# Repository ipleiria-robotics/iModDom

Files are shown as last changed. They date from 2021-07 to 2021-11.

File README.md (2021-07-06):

# iModDom
*Inexpensive Modular Domotics*

O projeto iModDom consiste num ecossistema de *hardware* e *software* desenvolvido de forma a ser utilizado em conjunto para aplicações em domótica utilizando o [Home Assistant](https://www.home-assistant.io/ "Home Assistant") e o [ESPHome](https://esphome.io/ "ESPHome").
A parte de *hardware* do projeto consiste em três placas de circuito impresso desenvolvidas para albergar todos os componentes com o objetivo de obter uma solução compacta e de fácil utilização. Já a parte de *software* consiste numa página *web* desenvolvida para o projeto, onde contém ferramentas que possibilitam a programação, do respetivo *hardware*, através de blocos.
O projeto foi desenvolvido com o intuito e objetivo de ser uma solução económica e que permitisse a sua utilização aos utilizadores sem conhecimentos na área da programação.

<p align="center">

</p>

## Passos a Seguir
- Recomenda-se que comece por consultar o manual técnico do projeto de modo a ficar a conhecer todos os componentes utilizados e o processo de montagem do *hardware*.
- Consulte os tutoriais disponíveis para poder usufruir do *software* desenvolvido.
- Faça as atividades propostas para ficar apto a criar as suas próprias aplicações para domótica.

## Ajuda
Se estiver com problemas, pode reportá-los [aqui](https://github.com/ipleiria-robotics/iModDom/issues "aqui").

## Contribuições 
Estamos abertos a sugestões com a finalidade de melhorar o projeto, pode colocá-las em forma de [pull request](https://github.com/ipleiria-robotics/iModDom/pulls "pull request") ou relatando os erros detetados.

# Autores
 - Marco Pereira - estudante do [Politécnico de Leiria](https://www.ipleiria.pt) do curso TeSP em Automação, Robótica e manutenção Industrial, GitHub: [MarcoPereira00](https://github.com/MarcoPereira00)

## Orientado por:
- Luís Conde - [Politécnico de Leiria](https://www.ipleiria.pt), GitHub:  [Luís Conde](https://github.com/conde-ISR-UC-PT)
- Carlos Neves - [Politécnico de Leiria](https://www.ipleiria.pt), [INESC-Coimbra](http://inescc.estg.ipleiria.pt/) GitHub:  [Carlos Neves](https://github.com/carlos-neves)

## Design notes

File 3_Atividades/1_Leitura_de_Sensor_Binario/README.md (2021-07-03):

# iModDom
## Exercícios de Leitura de Sensor Binário
- Com estes exercícios o utilizador irá ficar apto a realizar leituras de sensores binários, nomeadamente de botões, com vários graus de complexidade.

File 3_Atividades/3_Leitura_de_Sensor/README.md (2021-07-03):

# iModDom
## Exercícios de Leitura de Sensor
- Estes exercícios permitem ao utilizador desenvolver capacidades ao nível da leitura de sensores e também irá ficar a apto a fazer *upload* via WiFi, a criar um *web server* e visualizar as mensagens de *debug*.

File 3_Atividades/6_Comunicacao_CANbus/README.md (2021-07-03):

# iModDom
## Exercícios de Comunicação CANbus
- Estes exercícios são relativos ao protoclo de comunicação CANbus e desafiam o utilizador a realizar algumas implementações, de diferentes graus de dificuldade, através desse protocolo de comunicação.

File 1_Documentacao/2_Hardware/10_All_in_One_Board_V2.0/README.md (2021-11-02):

# iModDom
## *All Boards V2.0*
- Nesta Pasta pode encontrar os ficheiros que permitem fabricar de forma facilitada todas as placas desenvolvidas relativas à versão V2.0.


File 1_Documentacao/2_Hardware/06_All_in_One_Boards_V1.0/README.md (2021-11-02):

# iModDom
## *All Boards V1.0*
- Nesta Pasta pode encontrar os ficheiros que permitem fabricar de forma facilitada todas as placas desenvolvidas relativas à versão V1.0.


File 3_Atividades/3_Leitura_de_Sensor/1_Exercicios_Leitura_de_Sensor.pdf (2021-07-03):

# iModDom

V1.0-2021

# Leitura de Sensor - Exercícios

Elaborado por:
Marco Pereira - 2190516

Orientado por:
Luís Bento
Carlos Neves

V1.0-2021

Leitura de Sensor - Exercícios

### Índice

V1.0-2021 | 1

### 1. Introdução

Este documento integra um conjunto de exercícios de programação através de blocos para colocar em prática no projeto iModDom. Nestes exercícios a utilização das placas de circuito impresso do projeto é facultativa. Pode encontrar as soluções dos exercícios na pasta onde estes se encontram, e poderá fazer upload do ficheiro na página onde utiliza os blocos, de forma a visualizar as soluções.

1.1.Objetivos

O objetivo com estes exercícios é que o utilizador comece a ganhar capacidade de criar os seus próprios programas através dos blocos do projeto.

V1.0-2021 | 2

### 2. Exercícios

### 1. Crie um programa que permita visualizar os valores de temperatura e humidade do

sensor DHT11/DHT22, com uma taxa de atualização de 10 segundos. O pino utilizado para o sensor DHT fica ao seu critério.

1.1. Ao programa criado, adicione a possibilidade de realizar o upload via WiFi.

### 1.2. Implemente as funcionalidades que permitam a criação de um web server e a

visualização de mensagens do nível debug.

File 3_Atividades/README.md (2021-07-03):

# iModDom
## Atividades
- Nesta secção pode encontrar exercícios abrangentes a todas as funcionalidades do *software* desenvolvido. Após a realização de todos os exercicios ficará com as competências necessárias para executar e implementar as suas próprias aplicações em domótica. Cada exercício tem a respetiva solução.

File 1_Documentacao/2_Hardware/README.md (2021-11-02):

# iModDom
## *Hardware*
- Aqui estão disponíveis todos os ficheiros das placas de circuito impresso desenvolvidas através do *software Autodesk Eagle*. As placas contêm versões pelo que deverá sempre optar pela versão mais recente.
- Se desejar realizar alterações ao *hardware* desenvolvido tem todas as bibliotecas que foram utilizadas disponíveis na pasta [02_Eagle_Libraries](https://github.com/ipleiria-robotics/iModDom/tree/main/1_Documentacao/2_Hardware/02_Eagle_Libraries "02_Eagle_Libraries").
- Na pasta [01_Lista_de_Hardware](https://github.com/ipleiria-robotics/iModDom/blob/main/1_Documentacao/2_Hardware/01_Lista_de_Hardware "01_Lista_de_Hardware") pode verificar os custos do projeto de forma descriminada. Note que podem existir variações nos valores.
### Nota:
As versões V2.0 das placas, à presente data, não foram testadas nem fabricadas, pelo que a sua utilização e fabrico ficará à responsabilidade do utilizador. À exceção da versão V2.0 da *Shunt Board* que está totalmente funcional e testada.

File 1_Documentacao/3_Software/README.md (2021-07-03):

# iModDom
## *Software*
- Aqui encontra todos os ficheiros da solução de *software* desenvolvida e utilizada para a programação através de blocos. Esta solução foi desenvolvida utilizando a biblioteca do [Blockly](https://github.com/google/blockly#blockly- "Blockly").
- Na pasta [iModDom](https://github.com/ipleiria-robotics/iModDom/tree/main/1_Documentacao/3_Software/iModDom "iModDom") encontra todos os ficheiros necessários para a implementação da página *web* dos blocos.
- Através do ficheiro [library.xml](https://github.com/ipleiria-robotics/iModDom/blob/main/1_Documentacao/3_Software/library.xml "library.xml") pode editar os blocos de programação existentes utilizando a página [Blockly Developer Tools](https://blockly-demo.appspot.com/static/demos/blockfactory/index.html "Blockly Developer Tools").



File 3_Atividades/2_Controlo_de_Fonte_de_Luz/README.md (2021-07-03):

# iModDom
## Exercícios de Controlo de Fonte de Luz
- Estes exercícios permitem ao utilizador desenvolver capacidades ao nível do controlo de fontes de luz, através de vários niveis de complexidade.

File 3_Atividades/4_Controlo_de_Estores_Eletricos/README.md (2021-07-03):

# iModDom
## Exercícios de Controlo de Estores Elétricos
- Estes exercícios são relativos ao controlo de estores elétricos e desafiam o utilizador a desenvolver programações com a finalidade de controlar estores elétricos através de botões e do *Home Assistant*.

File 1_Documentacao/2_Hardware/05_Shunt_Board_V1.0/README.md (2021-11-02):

# iModDom
## *Shunt Board V1.0*
- Esta versão está finalizada, no entanto, à presente data não foi fabricada nem testada, pelo que a sua utilização fica à responsabilidade do utilizador.



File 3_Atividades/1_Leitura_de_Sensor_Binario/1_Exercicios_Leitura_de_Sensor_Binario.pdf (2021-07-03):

# iModDom

V1.0-2021

# Leitura de Sensor Binário - Exercícios

Elaborado por:
Marco Pereira - 2190516

Orientado por:
Luís Bento
Carlos Neves

V1.0-2021

Leitura de Sensor Binário - Exercícios

### Índice

V1.0-2021 | 1

### 1. Introdução

Este documento integra um conjunto de exercícios de programação através de blocos para colocar em prática no projeto iModDom. Nestes exercícios a utilização das placas de circuito impresso do projeto é facultativa. Pode encontrar as soluções dos exercícios na pasta onde estes se encontram, e poderá fazer upload do ficheiro na página onde utiliza os blocos, de forma a visualizar as soluções.

1.1.Objetivos

O objetivo com estes exercícios é que o utilizador comece a ganhar capacidade de criar os seus próprios programas através dos blocos do projeto.

V1.0-2021 | 2

### 2. Exercícios

### 1. Utilizando os blocos do projeto iModDom, crie um programa que possibilite a

leitura do estado de um botão no Home Assistant. O pino a utilizar fica ao seu critério.

### 1.1. Adicione agora, uma saída ao seu programa. O interlock e o restore mode não

deverão estar ativos e o pino a utilizar fica ao seu critério.

### 1.2. Ao programa já criado, adicione uma automação ao sensor binário, para que

quando o botão sofra um clique, de no máximo até 0.5 segundos de duração, a saída seja ativada e quando o botão sofrer um duplo clique com uma duração máxima de 0.5 segundos, a saída seja desativada.

1.3. Repita os exercícios anteriores, mas desta vez utilizando pinos, ao seu critério, do PCF8574 com o endereço 0x20 para receber a leitura do botão e do PCF8574 com o endereço 0x22 para comandar a saída.

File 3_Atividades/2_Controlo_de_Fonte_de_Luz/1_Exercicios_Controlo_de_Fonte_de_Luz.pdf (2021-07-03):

# iModDom

V1.0-2021

# Controlo de Fonte de Luz - Exercícios

Elaborado por:
Marco Pereira - 2190516

Orientado por:
Luís Bento
Carlos Neves

V1.0-2021

Controlo de Fonte de Luz - Exercícios

### Índice

V1.0-2021 | 1

### 1. Introdução

Este documento integra um conjunto de exercícios de programação através de blocos para colocar em prática no projeto iModDom. Nestes exercícios a utilização das placas de circuito impresso do projeto é facultativa. Pode encontrar as soluções dos exercícios na pasta onde estes se encontram, e poderá fazer upload do ficheiro na página onde utiliza os blocos, de forma a visualizar as soluções.

1.1.Objetivos

O objetivo com estes exercícios é que o utilizador comece a ganhar capacidade de criar os seus próprios programas através dos blocos do projeto.

V1.0-2021 | 2

### 2. Exercícios

### 1. Crie um programa, que permita controlar o estado de uma fonte de luz através do

Home Assistant. O pino utilizado para a fonte de luz fica ao seu critério.

### 1.1. Adicione ao programa criado, a possibilidade de acender a fonte luz no

momento em que se pressiona um botão e apagar quando se liberta esse mesmo botão. O pino utilizado para o botão fica ao seu critério.

### 1.2. Repita os exercícios anteriores, mas utilizando pinos, à sua escolha, do

PCF8574 com o endereço 0x22, para a fonte de luz, e do PCF8574 com o endereço 0x20 para receber a leitura do estado do botão.

### 1.3. No programa já existente, adicione mais uma fonte de luz, em que o seu estado

será alterado aquando de um clique duplo no botão com uma duração máxima, de cada clique, de 0.5 segundos. O estado da fonte de luz adicionada anteriormente será alterado sempre que existir um clique com uma duração máxima de 0.5 segundos. Deverá adicionar a nova fonte de luz num pino do PCF8574 com o endereço 0x22.

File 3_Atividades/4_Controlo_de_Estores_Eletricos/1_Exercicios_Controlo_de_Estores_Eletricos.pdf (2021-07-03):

# iModDom

V1.0-2021

# Controlo de Estores Elétricos - Exercícios

Elaborado por:
Marco Pereira - 2190516

Orientado por:
Luís Bento
Carlos Neves

V1.0-2021

Controlo de Estores Elétricos - Exercícios

### Índice

V1.0-2021 | 1

### 1. Introdução

Este documento integra um conjunto de exercícios de programação através de blocos para colocar em prática no projeto iModDom. Nestes exercícios a utilização das placas de circuito impresso do projeto é facultativa. Pode encontrar as soluções dos exercícios na pasta onde estes se encontram, e poderá fazer upload do ficheiro na página onde utiliza os blocos, de forma a visualizar as soluções.

1.1.Objetivos

O objetivo com estes exercícios é que o utilizador comece a ganhar capacidade de criar os seus próprios programas através dos blocos do projeto.

V1.0-2021 | 2

### 2. Exercícios

### 1. Crie um programa que permita controlar uns estores elétricos através do Home

Assistant, utilizando duas saídas para simular a abertura e fecho dos estores. O tempo de abertura e de fecho deverá ser de 5 segundos para cada ação.

### 1.1. Adicione ao programa, a possibilidade de abrir, fechar e parar os estores

elétricos através de três botões, um para cada função. Deverá definir a duração máxima de 0.5 segundos para cada clique. Os pinos de cada botão ficam ao seu critério.

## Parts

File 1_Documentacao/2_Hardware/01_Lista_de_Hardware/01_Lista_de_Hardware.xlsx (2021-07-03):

 |  | Dep. Eng. Eletrotécnica - UC de Projeto em Engenharia Eletrotécnica e de Computadores
 |  | Lista de Material e Fornecedores
 |  | Título Projeto: | iModDom
 |  | Orientadores: | Luis Conde Bento, Carlos Neves
 |  | Data: | 2021-06-17
Item | Descrição | Referência | Qtd | Fornecedor
 | ESPHOME
1 | Placas de Circuito Impresso (Quantidade mínima de 5 unidades) |  | 1 | JLPCB | https://jlcpcb.com/VGB
2 | Módulo RJ45 2x4 (Quantidade mínima de 10) | 10Pcs Sample 2x4 Ports 59 Series Stack-up Female RJ45 Ethernet Network LAN PCB Socket Connector Jack | 1 | AliExpress | https://es.aliexpress.com/item/32274753116.html
3 | I/O Expander PCF8574 | PCF8574 I2C Interface 8bit IO MCU Expansion Board I/O Expander I2C Bus Evaluation Development Module AVR STM8 C8051F For Arduino | 6 | AliExpress | https://es.aliexpress.com/item/4001011447071.html
4 | Módulo de 8 Relés de Estado Sólido | Low Level 5V 1/2/4/8 Channel Solid State Relay Module SSR G3MB-202P 240V 2A Output with Resistive Fuse For Arduino 1 2 4 8 Way | 3 | AliExpress | https://es.aliexpress.com/item/32788946442.html?albpd=pt32788946442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
5 | ESP32-PoE-ISO |  | 1 | Olimex | https://www.olimex.com/Products/IoT/ESP32/ESP32-POE-ISO/open-source-hardware
6 | Módulo CANbus MCP2515 | KKCHIP MCP2515 CAN Bus Module TJA1050 receiver SPI For 51 MCU ARM controller | 3 | AliExpress | https://es.aliexpress.com/item/1005002304689735.html
7 | ESP8266 D1 Mini | D1 Mini ESP8266 ESP-12 ESP-12F CH340G CH340 V2 USB WeMos WIFI Development Board D1 Mini NodeMCU Lua IOT Board 3.3V With Pins | 2 | AliExpress | https://es.aliexpress.com/item/1005001636509632.html?spm=a2g0s.9042311.0.0.30d04c4dn6QdZj
8 | Pinos conectores fêmea (Quantidade mínima de 10 unidades de 40 pinos cada) | 10pcs 40 Pin 1x40 Single Row Male And Female 2.54 Breakable Pin Header Connector Strip For Arduino Black | 1 | AliExpress | https://es.aliexpress.com/item/1005002368609978.html
9 | Parafusos plásticos M3x18 (Quantidade mínima de 50 unidades) | 50pcs Brand New M2 M3 M4 High Quality Black White Nylon Plastic Phillips Pan Head Cross Round Screw Bolt length 5mm-25mm | 1 | AliExpress | https://es.aliexpress.com/item/32979035684.html
10 | Porcas M3 (Quantidade mínima de 50 unidades) | 50pcs Brand New M2 M3 M4 High Quality Black White Nylon Plastic Phillips Pan Head Cross Round Screw Bolt length 5mm-25mm | 1 | AliExpress | https://es.aliexpress.com/item/32979035684.html
11 | Espaçadores M3 11mm (Quantidade mínima de 100 unidades) | M3x11 Nuts Hex PCB Spacer Standoff Pillar Female to Female Plastic Nylon Accessories for UAV Quadrotor Off-White Pack 100 | 1 | AliExpress | https://es.aliexpress.com/item/32775392154.html
12 | Sensor DHT11 | DHT11 Temperature Humidity Sensor Module Digital Single Bus 3.3V-5V with Jumper Wires for Arduino Raspberry Pi | 1 | AliExpress | https://es.aliexpress.com/item/1005002119274556.html
13 | Ficha RJ45 (Quantidade mínima de 10) | 10Pcs Per Lot RJ45 Metal 8 Pin Female PCB Right Angle Board Jack Connector 8P8C Crystal Head Socket 18mm Network Interface | 1 | AliExpress | https://pt.aliexpress.com/item/32680360858.html
 | HOME ASSISTANT
14 | Raspberry Pi 4 Model B |  | 1 | Mauser | https://mauser.pt/catalog/product_info.php?products_id=096-7401&src=raspberrypi

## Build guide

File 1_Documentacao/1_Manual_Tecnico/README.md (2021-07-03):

# iModDom
## Manual Técnico
- Aqui poderá consultar o manual técnico do projeto, sendo que a versão do mesmo corresponde à versão do *hardware* do projeto. Este documento inclui a descrição de todos os componentes utilizados no projeto, listagem do material e o processo de montagem do *hardware*.

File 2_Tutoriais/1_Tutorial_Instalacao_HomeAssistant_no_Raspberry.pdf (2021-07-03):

# iModDom

V1.0-2021

# Tutorial – Instalação Home Assistant no Raspberry

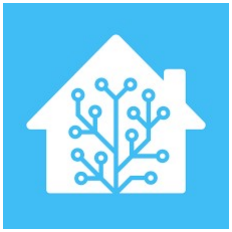
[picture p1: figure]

Elaborado por:
Marco Pereira - 2190516

Orientado por:
Luís Bento
Carlos Neves

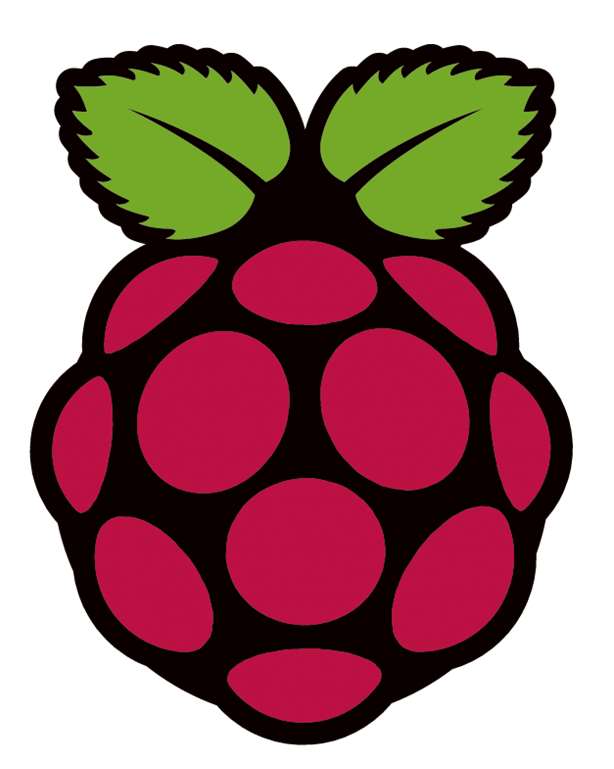
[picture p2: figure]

V1.0-2021

Tutorial – Instalação Home Assistant no Raspberry

### Índice

V1.0-2021 | 1

### 1. Introdução

O Home Assistant é uma plataforma de automação open source que permite rastrear e controlar vários dispositivos de forma automatizada. Já o Raspberry Pi é um pequeno computador que pode ser utilizado para múltiplas funções e projetos, neste caso será nele que irá estar instalado o Home Assistant.

1.1.Objetivos

Com este tutorial, o objetivo é ensinar a instalar o Home Assistant no Raspberry Pi.

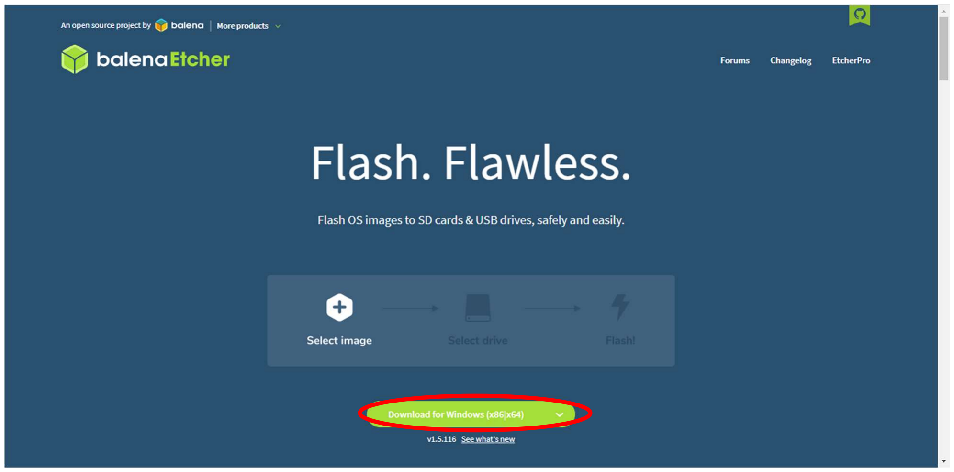
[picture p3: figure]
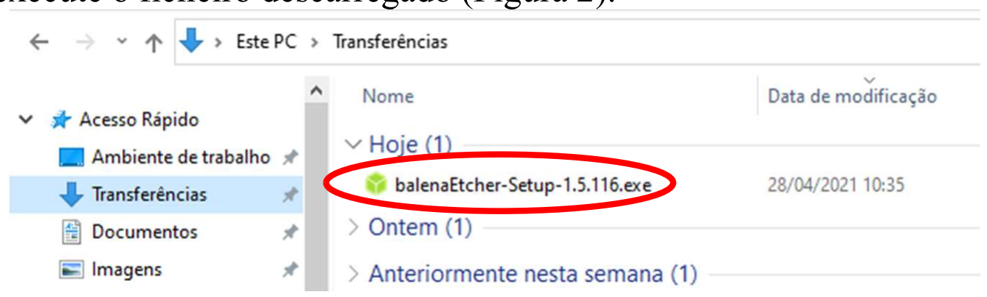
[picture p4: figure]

V1.0-2021 | 2

### 2. Instalação do Home Assistant

1. Aceda ao seguinte link: https://www.balena.io/etcher/.

### 2. Selecione o seu sistema operativo e inicie o download (Figura 1)

Figura 1 – Download balenaEtcher

### 3. Após o download estar concluído com sucesso, aceda à pasta “Transferências”

e execute o ficheiro descarregado (Figura 2).

Figura 2 – Executar o Ficheiro

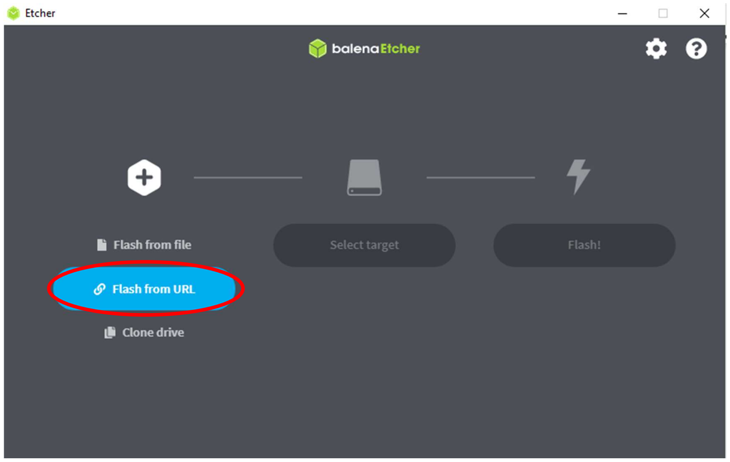
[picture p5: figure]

V1.0-2021 | 3
4. Na janela que irá surgir clique em “Aceito”.
5. De seguida clique em “Flash from URL” (Figura 3).

Figura 3 – Clicar em “Flash from URL”

6. Copie o URL que se adequa ao seu Raspberry Pi e cole no campo que surgiu, de seguida clique em “OK” (Figura 4).

Raspberry Pi 4 64-bit: https://github.com/home-assistant/operatingsystem/releases/download/5.13/hassos_rpi4-64-5.13.img.xz
Raspberry Pi 4 32-bit: https://github.com/home-assistant/operatingsystem/releases/download/5.13/hassos_rpi4-5.13.img.xz
Raspberry Pi 3 64-bit: https://github.com/home-assistant/operatingsystem/releases/download/5.13/hassos_rpi3-64-5.13.img.xz
Raspberry Pi 3 32-bit: https://github.com/home-assistant/operatingsystem/releases/download/5.13/hassos_rpi3-5.13.img.xz

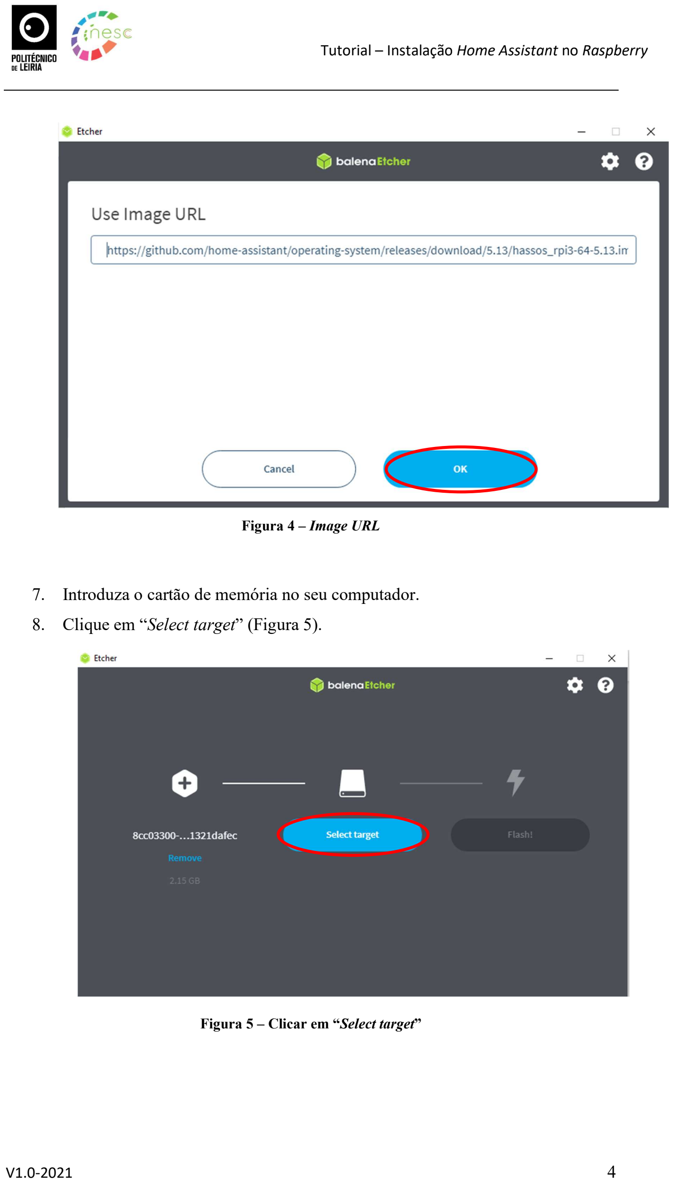
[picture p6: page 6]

V1.0-2021 | 4

Figura 4 – Image URL

7. Introduza o cartão de memória no seu computador.
8. Clique em “Select target” (Figura 5).

Figura 5 – Clicar em “Select target”

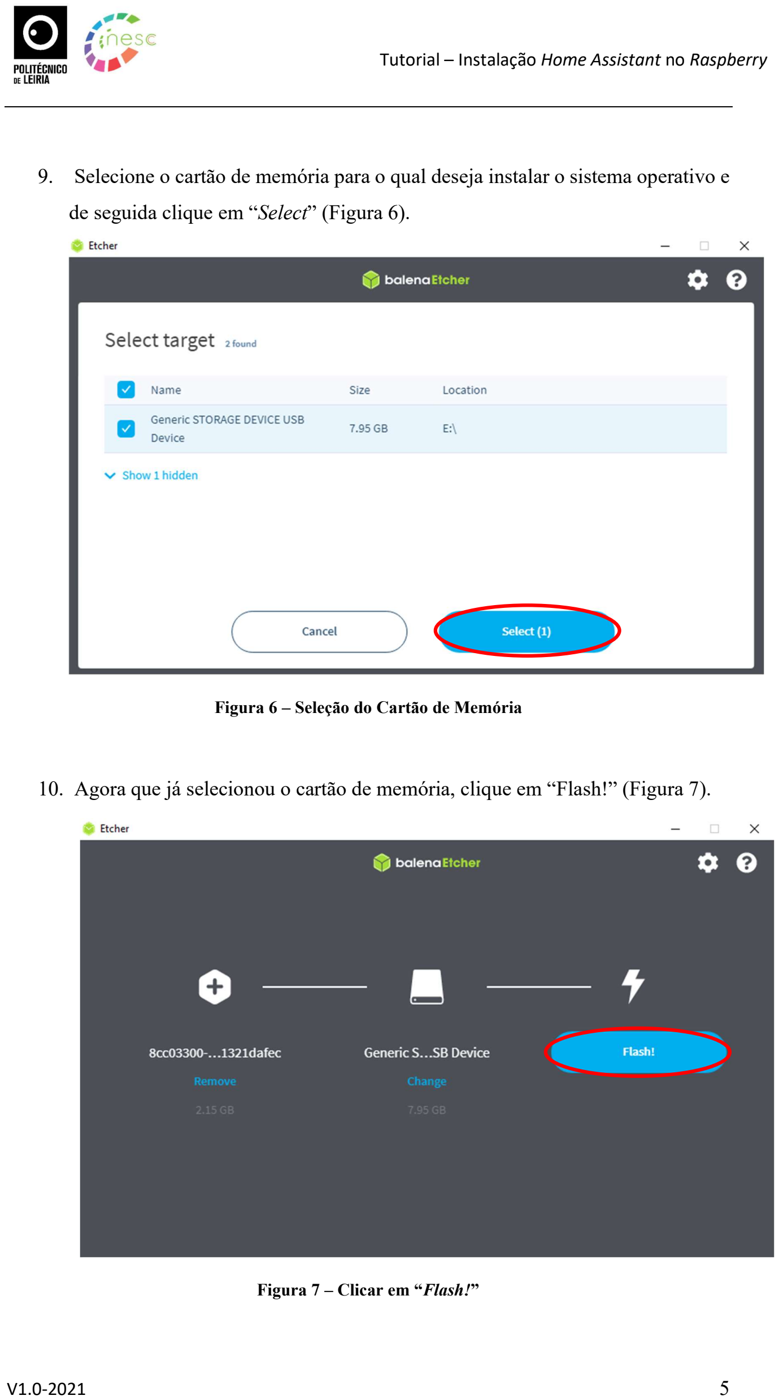
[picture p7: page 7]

V1.0-2021 | 5

### 9. Selecione o cartão de memória para o qual deseja instalar o sistema operativo e

de seguida clique em “Select” (Figura 6).

Figura 6 – Seleção do Cartão de Memória

10. Agora que já selecionou o cartão de memória, clique em “Flash!” (Figura 7).

Figura 7 – Clicar em “Flash!”

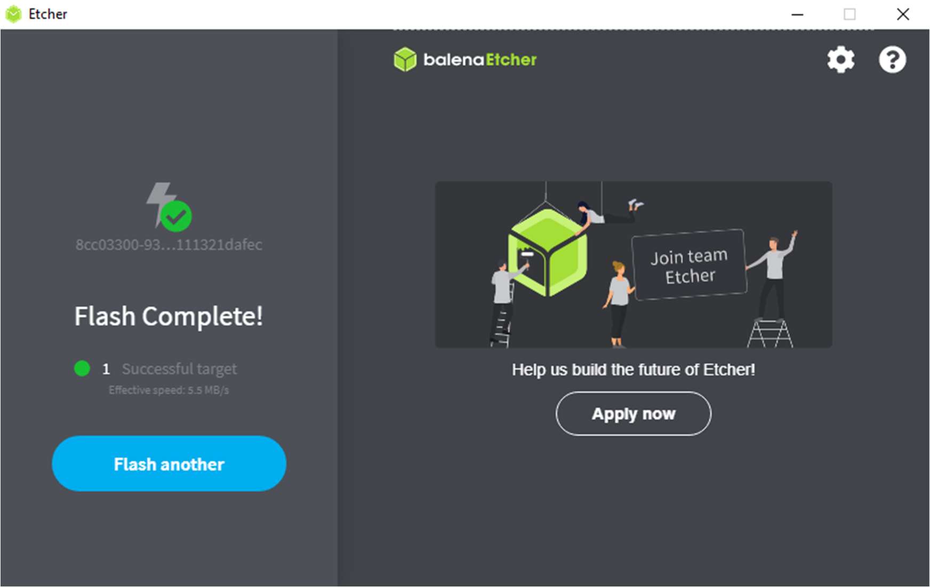
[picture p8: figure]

V1.0-2021 | 6

### 11. Quando a imagem tiver sido instalada com sucesso irá surgir-lhe uma

confirmação semelhante à da Figura 8 e pode fechar a janela.

Figura 8 – Instalação Terminada com Sucesso

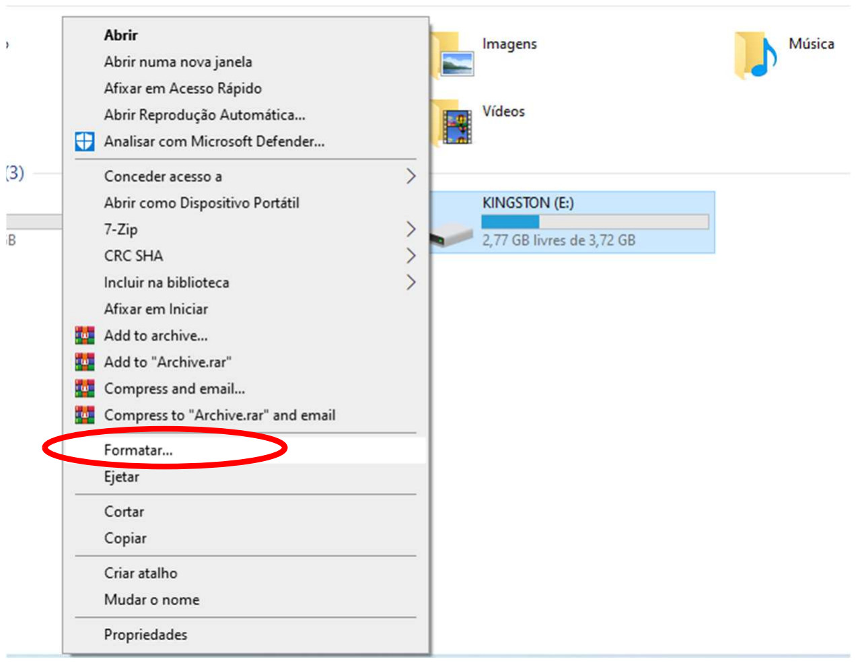
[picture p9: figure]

V1.0-2021 | 7

### 3. Arranque do Home Assistant

Nos próximos passos poderá querer ligar um monitor ao Raspberry Pi para facilitar a visualização das ações realizadas, contudo não é necessário.

### 1. Agora que já instalou o sistema operativo no cartão de memória, pode retirá-

lo e colocá-lo no seu Raspberry Pi.

### 2. Para conectar o Raspberry Pi à internet pode simplesmente ligar um cabo de

rede, se desejar fazer a ligação por WiFi terá de seguir os seguintes passos:

### 2.1. Primeiramente necessita de uma Pen formatada, para isso, clique com o lado

direito do rato sobre a Pen e de seguida clique em “Formatar…”, note que esta ação irá eliminar permanentemente todos os ficheiros da Pen (Figura 9).

Figura 9 - Formatar a Pen

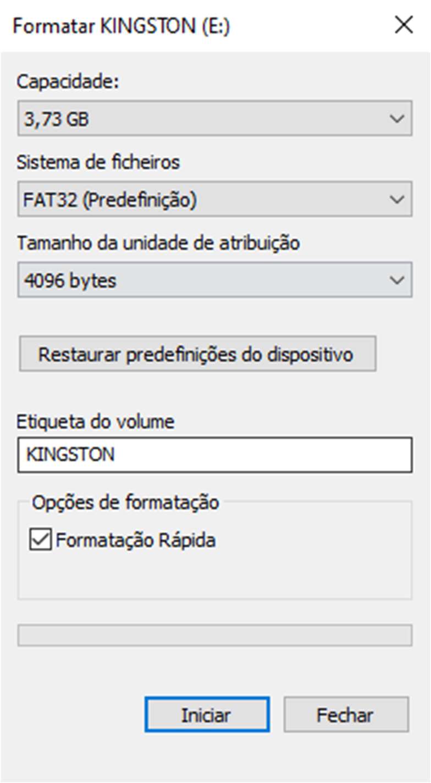
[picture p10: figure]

V1.0-2021 | 8

### 2.2. Na janela que irá surgir clique em “Iniciar” e aguarde até que a Pen esteja

formatada (Figura 10).

Figura 10 - Iniciar Formatação

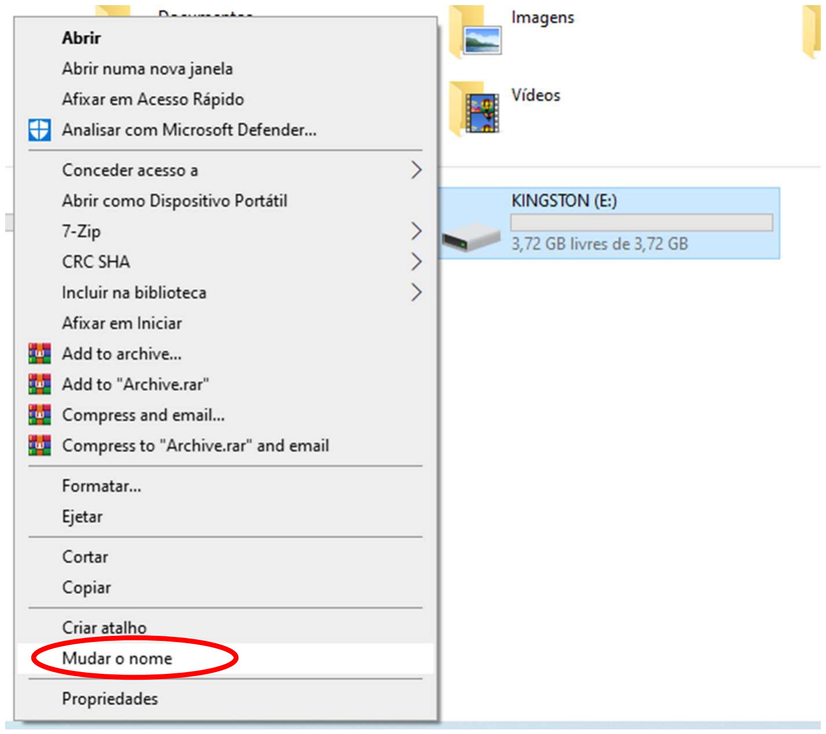
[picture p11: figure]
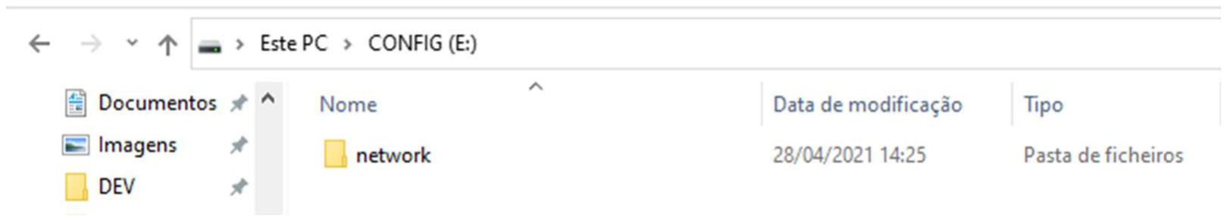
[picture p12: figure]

V1.0-2021 | 9

### 2.3. De seguida clique com o lado direito do rato na Pen e selecione a opção

“Mudar o nome” e atribua-lhe o nome “CONFIG” (Figura 11).

Figura 11 - Mudar o Nome

2.4. Crie uma pasta dentro da Pen com o nome “network” (Figura 12).

Figura 12 - Pasta "network"

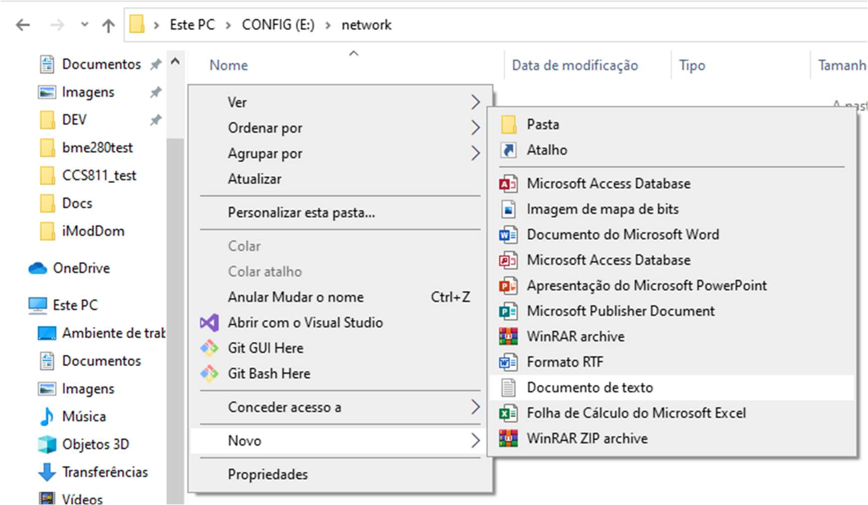
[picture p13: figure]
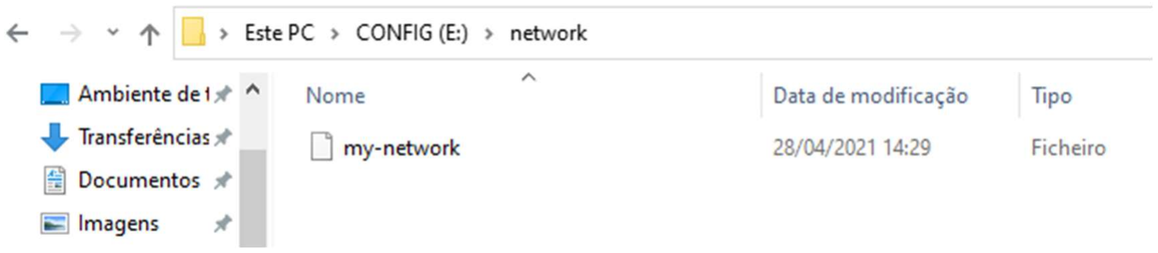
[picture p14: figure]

V1.0-2021 | 10

### 2.5. Dentro da pasta crie um ficheiro com o nome “my-network”, para isso, dentro

da pasta criada clique com o lado direito do rato, selecione “Novo” e de seguida “Documento de texto” (Figura 13). Quando atribuir o nome ao ficheiro é importante que elimine a extensão (“.txt”) do mesmo, ficando o ficheiro com o aspeto da Figura 14.

Figura 13 - Novo Ficheiro

Figura 14 - Aspeto Final do Ficheiro

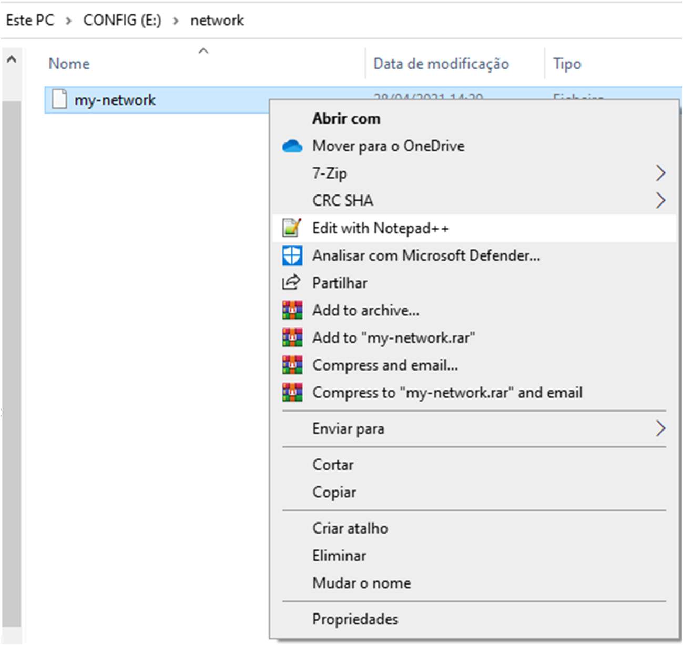
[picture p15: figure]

V1.0-2021 | 11

### 2.6. Selecione o ficheiro criado e clique com o botão direito do rato e selecione

“Edit With Notepad++” caso tenha o Notepad++ instalado, caso contrário selecione a opção do bloco de notas (Figura 15).

Figura 15 – Editar o Ficheiro

V1.0-2021 | 12

### 2.7. Coloque o seguinte texto no ficheiro, alterando “MY_SSID” por o nome da

rede à qual se pretende conectar e “MY_WLAN_SECRET_KEY” pela password da rede.

[connection]
id=my-network
uuid=72111c67-4a5d-4d5c-925e-f8ee26efb3c3 type=802-11-wireless

[802-11-wireless]
mode=infrastructure
ssid=MY_SSID
# Uncomment below if your SSID is not broadcasted #hidden=true

[802-11-wireless-security]
auth-alg=open
key-mgmt=wpa-psk
psk=MY_WLAN_SECRET_KEY

[ipv4]
method=auto

[ipv6]
addr-gen-mode=stable-privacy method=auto

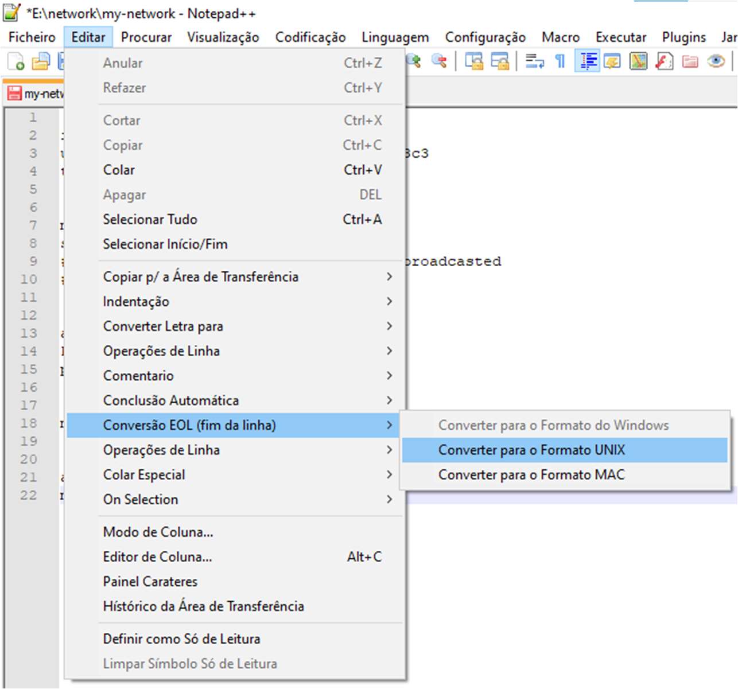
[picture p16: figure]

V1.0-2021 | 13

2.8.Ainda dentro do ficheiro, aceda a “Editar”, de seguida a “Conversão EOL (fim de linha)” e selecione a opção “Converter para o formato UNIX” (Figura 16), de seguida pode salvar e fechar o ficheiro.

Figura 16 – Conversão do Ficheiro

### 3. Se desejar conectar o Raspberry Pi por WiFi terá agora, de colocar a Pen

numa das entradas USB do mesmo, caso pretenda conectar o Raspberry Pi por cabo basta ligar o cabo ethernet.
Nota: A Pen só é necessária durante o primeiro arranque, após isso pode retirá-la e trabalhar apenas com o seu Raspberry Pi.
4. De seguida pode alimentar o Raspberry Pi com um transformador adequado, de notar que se o transformador não conseguir fornecer a potência suficiente o Raspberry Pi irá estar a reiniciar constantemente. Pode consultar as recomendações de alimentação da marca no seguinte link: https://www.raspberrypi.org/documentation/hardware/raspberrypi/power/REA DME.md

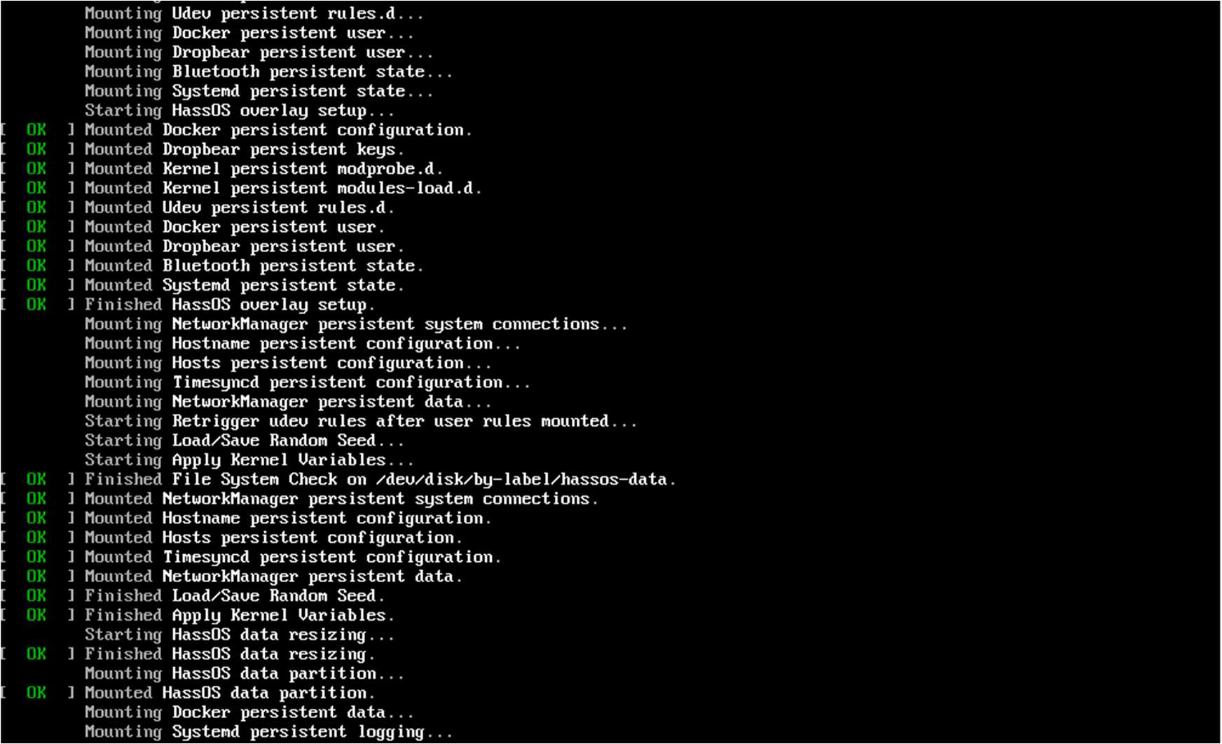
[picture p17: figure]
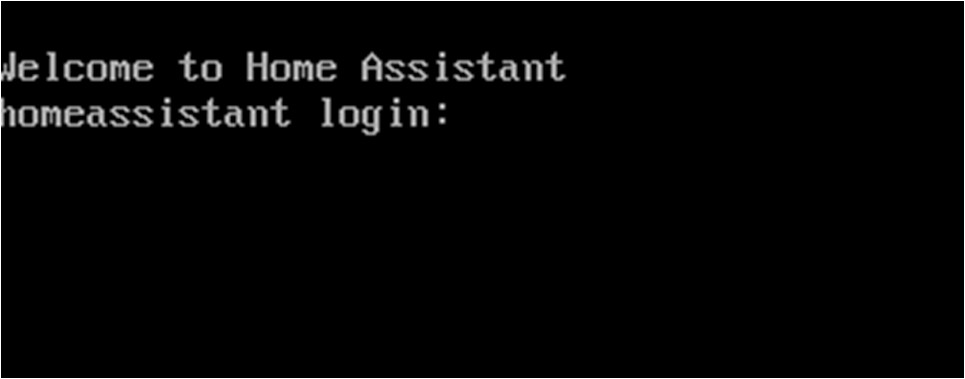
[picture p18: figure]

V1.0-2021 | 14

### 5. Se tiver o Raspberry Pi ligado a um monitor irá verificar que ao arrancar irá

apresentar uma imagem semelhante à Figura 17.

Figura 17 – Aspeto Durante o Arranque

6. Após a conclusão do arranque aparecerá uma imagem como a da Figura 18.

Figura 18 – Aspeto Após o Arranque

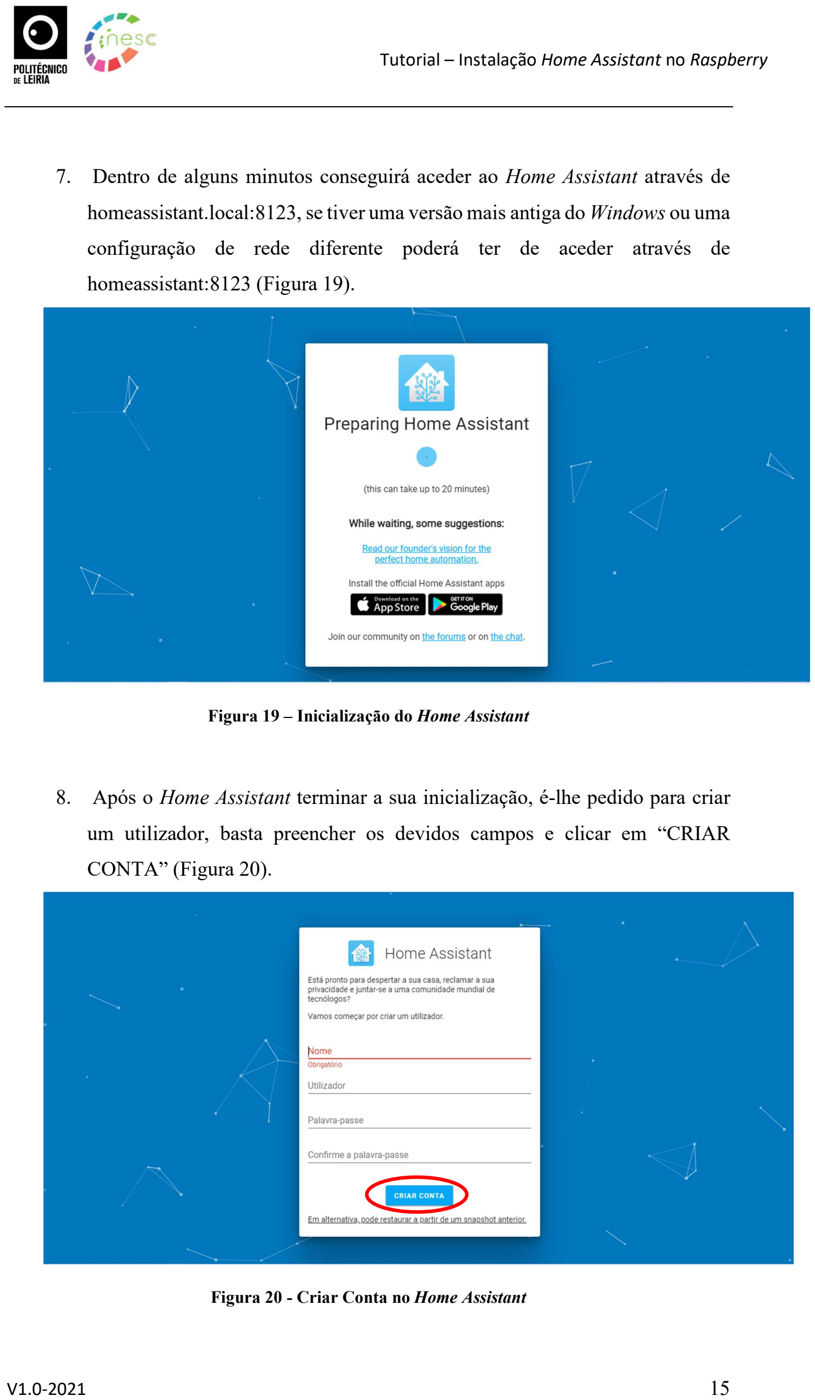
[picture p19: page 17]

V1.0-2021 | 15

### 7. Dentro de alguns minutos conseguirá aceder ao Home Assistant através de

homeassistant.local:8123, se tiver uma versão mais antiga do Windows ou uma configuração de rede diferente poderá ter de aceder através de homeassistant:8123 (Figura 19).

Figura 19 – Inicialização do Home Assistant

### 8. Após o Home Assistant terminar a sua inicialização, é-lhe pedido para criar

um utilizador, basta preencher os devidos campos e clicar em “CRIAR CONTA” (Figura 20).

Figura 20 - Criar Conta no Home Assistant

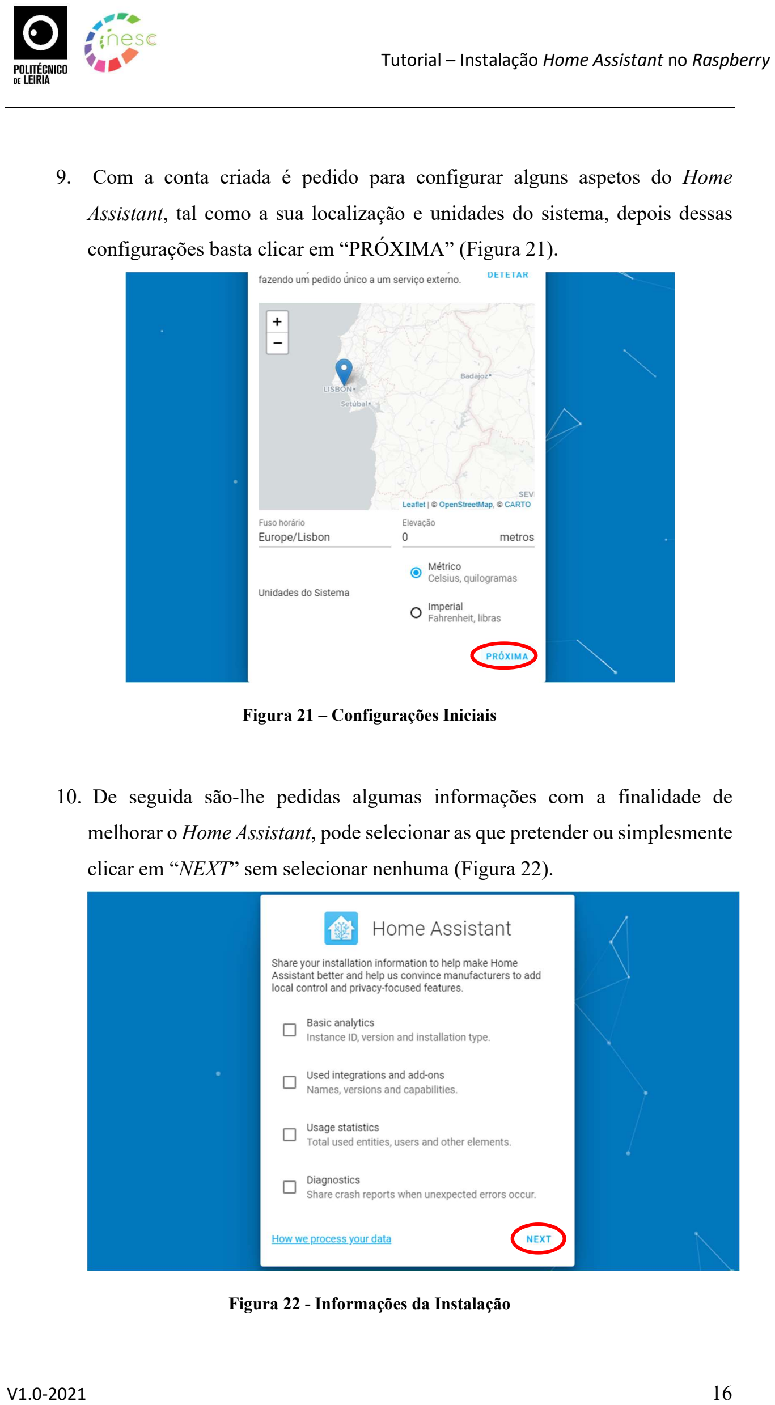
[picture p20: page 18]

V1.0-2021 | 16

### 9. Com a conta criada é pedido para configurar alguns aspetos do Home

Assistant, tal como a sua localização e unidades do sistema, depois dessas configurações basta clicar em “PRÓXIMA” (Figura 21).

Figura 21 – Configurações Iniciais

### 10. De seguida são-lhe pedidas algumas informações com a finalidade de

melhorar o Home Assistant, pode selecionar as que pretender ou simplesmente clicar em “NEXT” sem selecionar nenhuma (Figura 22).

Figura 22 - Informações da Instalação

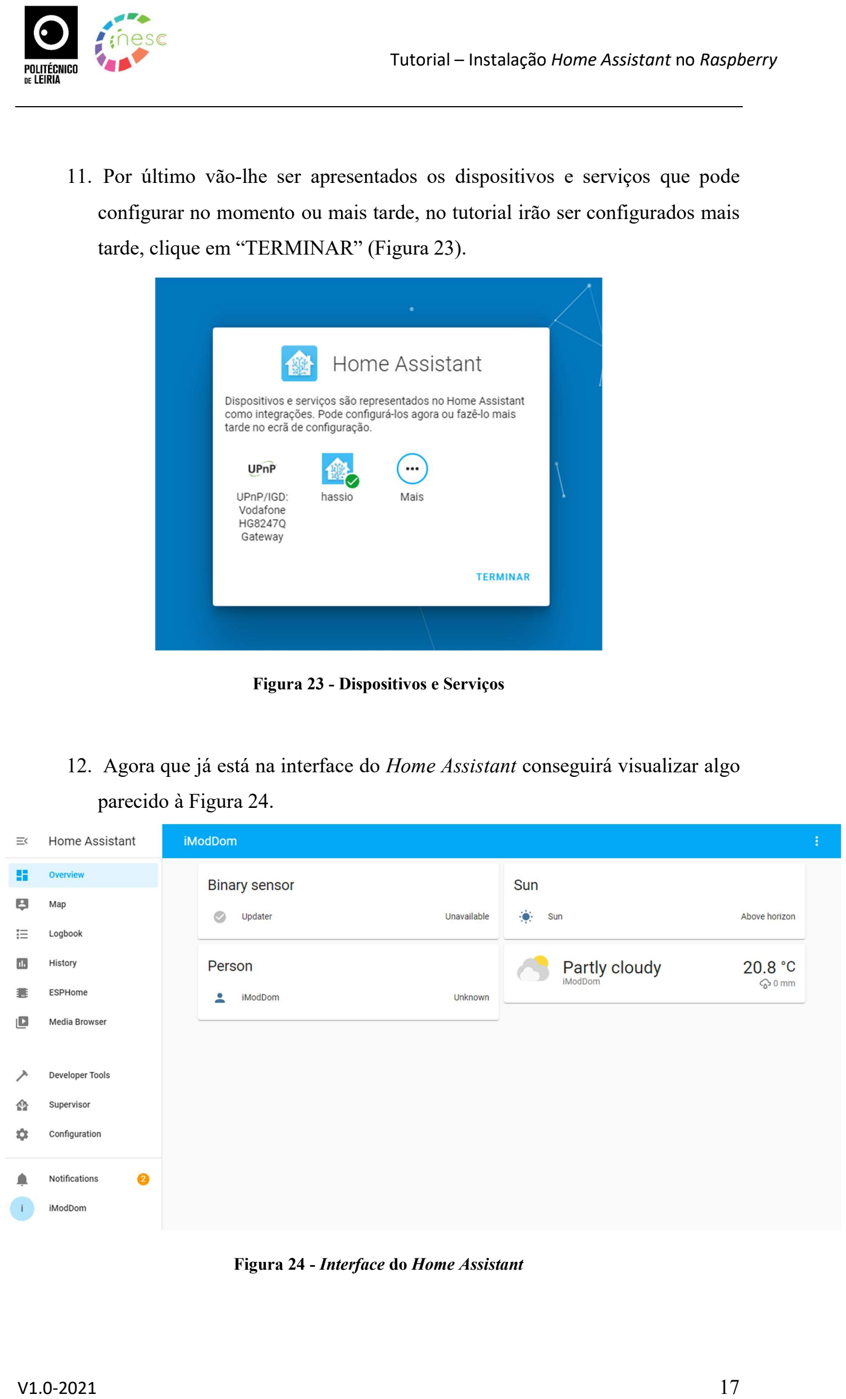
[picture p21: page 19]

V1.0-2021 | 17

### 11. Por último vão-lhe ser apresentados os dispositivos e serviços que pode

configurar no momento ou mais tarde, no tutorial irão ser configurados mais tarde, clique em “TERMINAR” (Figura 23).

Figura 23 - Dispositivos e Serviços

### 12. Agora que já está na interface do Home Assistant conseguirá visualizar algo

parecido à Figura 24.

Figura 24 - Interface do Home Assistant

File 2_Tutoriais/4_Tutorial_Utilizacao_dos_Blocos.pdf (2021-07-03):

# iModDom

V1.0-2021

# Tutorial – Utilização dos Blocos

Elaborado por:
Marco Pereira - 2190516

Orientado por:
Luís Bento
Carlos Neves

V1.0-2021

Tutorial – Utilização dos Blocos

### Índice

V1.0-2021

V1.0-2021 | 1

### 1. Introdução

Para facilitar a criação de código a todos os utilizadores, foram criados blocos que geram esse mesmo código de uma forma bastante intuitiva. Haverá pequenos passos que não serão explicados neste tutorial por já terem sido explicados em outros tutoriais.

1.1.Objetivos

O objetivo com este tutorial é ensinar a utilizar esses mesmos blocos e como tirar partido do código gerado.

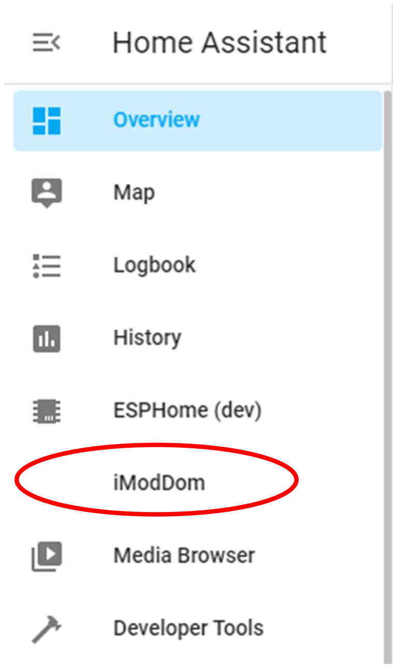
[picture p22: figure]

V1.0-2021 | 2

### 2. Utilização dos Blocos

Para utilizar os vários blocos do projeto e assim gerar o seu próprio código deverá seguir os seguintes passos.

### 1. Aceda à página do Home Assistant e de seguida ao separador “iModDom” de

modo a ter acesso a página dos blocos (Figura 1).

Figura 1 - Separador "iModDom"

### 2. Na página aberta, começando pelo canto superior esquerdo, encontram-se

vários logótipos, entre eles o do GitHub, se clicar sobre o mesmo será direcionado para o repositório do projeto, o logótipo do INESC Coimbra, em que se clicar sobre ele será direcionado para a respetiva página, o logótipo do Instituto Politécnico de Leiria, em que se clicar sobre o mesmo irá ser direcionado para a página da Escola Superior de Tecnologia e Gestão, por último existe o logótipo do Blockly que o direcionará para o repositório do mesmo. Ainda no canto superior esquerdo existem vários botões, sendo que o primeiro permite fazer o download do playground, de modo a salvar todo o trabalho realizado, o segundo botão permite fazer o upload do playground para que seja possível editar trabalhos salvos anteriormente, de seguida existe o botão que

V1.0-2021 | 3

permite guardar o código gerado num ficheiro yaml, o quarto botão tem o objetivo de gerar o código através dos blocos adicionados ao playground, através do quinto botão é possível copiar todo o conteúdo contido na caixa de texto e o ultimo botão permite apagar todo o conteúdo da caixa de texto e do playground. Abaixo dos botões existe uma caixa de texto onde será apresentado o código gerado e do lado direito da caixa de texto existem as várias abas que contêm os blocos para gerar código, estando estes divididos em “Beginner” e “Advanced”, tal como o nome indica, a primeira aba contém blocos básicos e de fácil utilização e a segunda já contém blocos mais avançados e completos. Do lado direito das abas dos blocos existe o playground, local onde colocará os blocos, no canto inferior direito existe um ícone de caixote do lixo, através do qual poderá apagar os seus blocos, arrastando-os para lá, existem ainda três ícones, sendo que o primeiro tem o objetivo de centrar os blocos na página, o segundo tem a função de zoom in e o terceiro a função de zoom out.

Figura 2 – Página “iModDom”

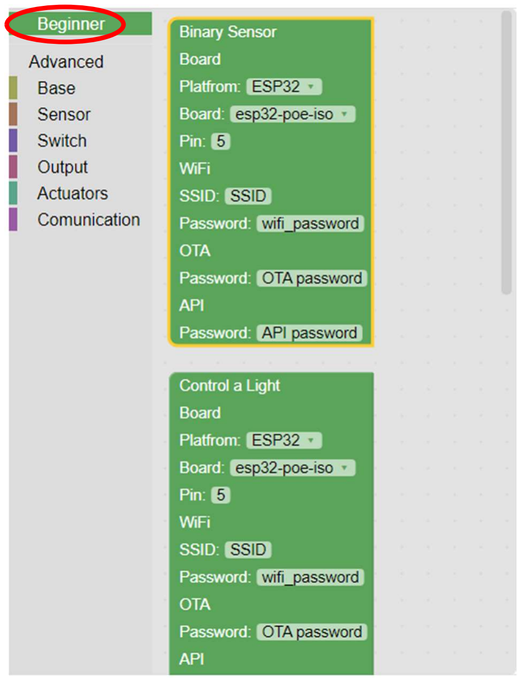
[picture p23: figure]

V1.0-2021 | 4

2.1.Utilização dos Blocos Beginner

Estes blocos permitem que o utilizador, de uma forma bastante fácil e intuitiva, utilize pela primeira vez blocos para gerar código. Os blocos desta secção só podem ser utilizados individualmente, isto é, aquando da utilização de um bloco deste tipo não se pode utilizar nenhum outro em simultâneo.

### 2.1.1. Binary Sensor

Este bloco permite gerar código para a utilização de um sensor binário, como é o caso de um botão por exemplo.

### 1. Comece por aceder ao separador “Beginner” e de seguida arraste o bloco

para o workspace (Figura 3).

Figura 3 - Seleção do bloco

### 2. Preencha todos os campos do bloco, sendo que no primeiro e segundo deve

selecionar o seu ESP, no terceiro campo (“Pin”), introduzida o número do pino onde irá ligar o seu botão, no campo “SSID” deverá introduzir o nome da rede WiFi à qual se deseja conectar e no campo “Password” a palavra-

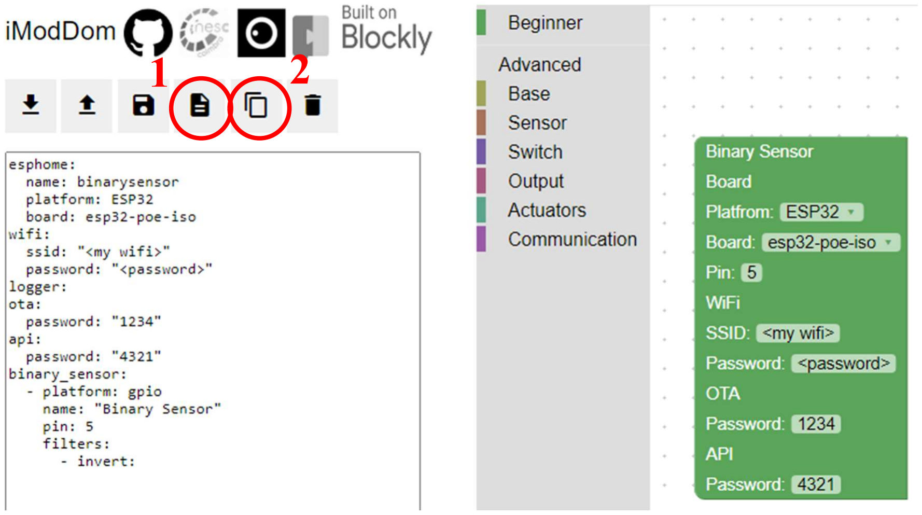
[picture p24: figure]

V1.0-2021 | 5

chave dessa mesma rede. De seguida deve colocar uma password para as atualizações por WiFi e por último uma password para poder integrar o código no Home Assistant (Figura 4).

Figura 4 - Aspeto final do bloco

### 3. Clique no ícone do ficheiro para gerar o código a ser utilizado e de seguida

clique no ícone de copiar para copiar todo o código (Figura 5).

Figura 5 - Gerar e Copiar o Código

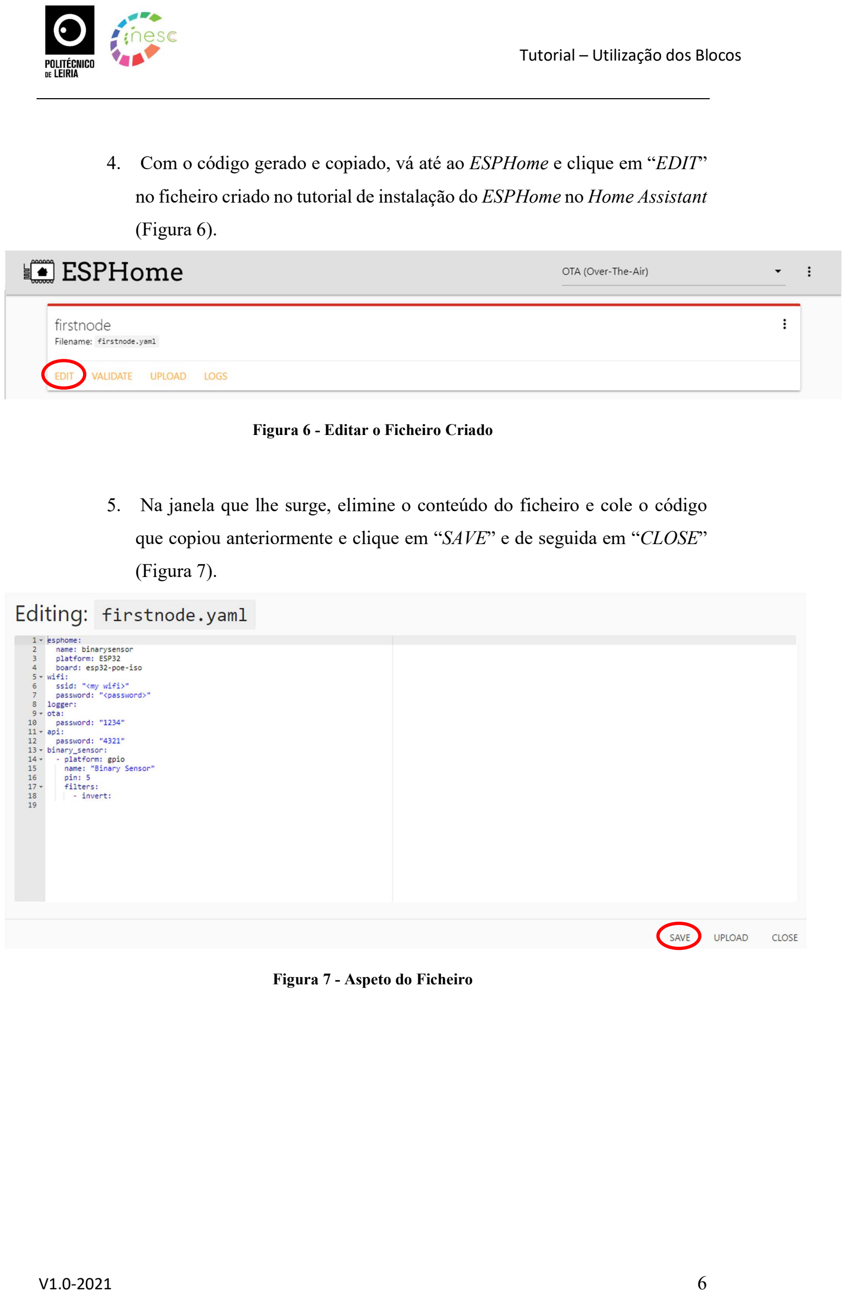
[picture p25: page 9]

V1.0-2021 | 6

### 4. Com o código gerado e copiado, vá até ao ESPHome e clique em “EDIT”

no ficheiro criado no tutorial de instalação do ESPHome no Home Assistant (Figura 6).

Figura 6 - Editar o Ficheiro Criado

### 5. Na janela que lhe surge, elimine o conteúdo do ficheiro e cole o código

que copiou anteriormente e clique em “SAVE” e de seguida em “CLOSE” (Figura 7).

Figura 7 - Aspeto do Ficheiro

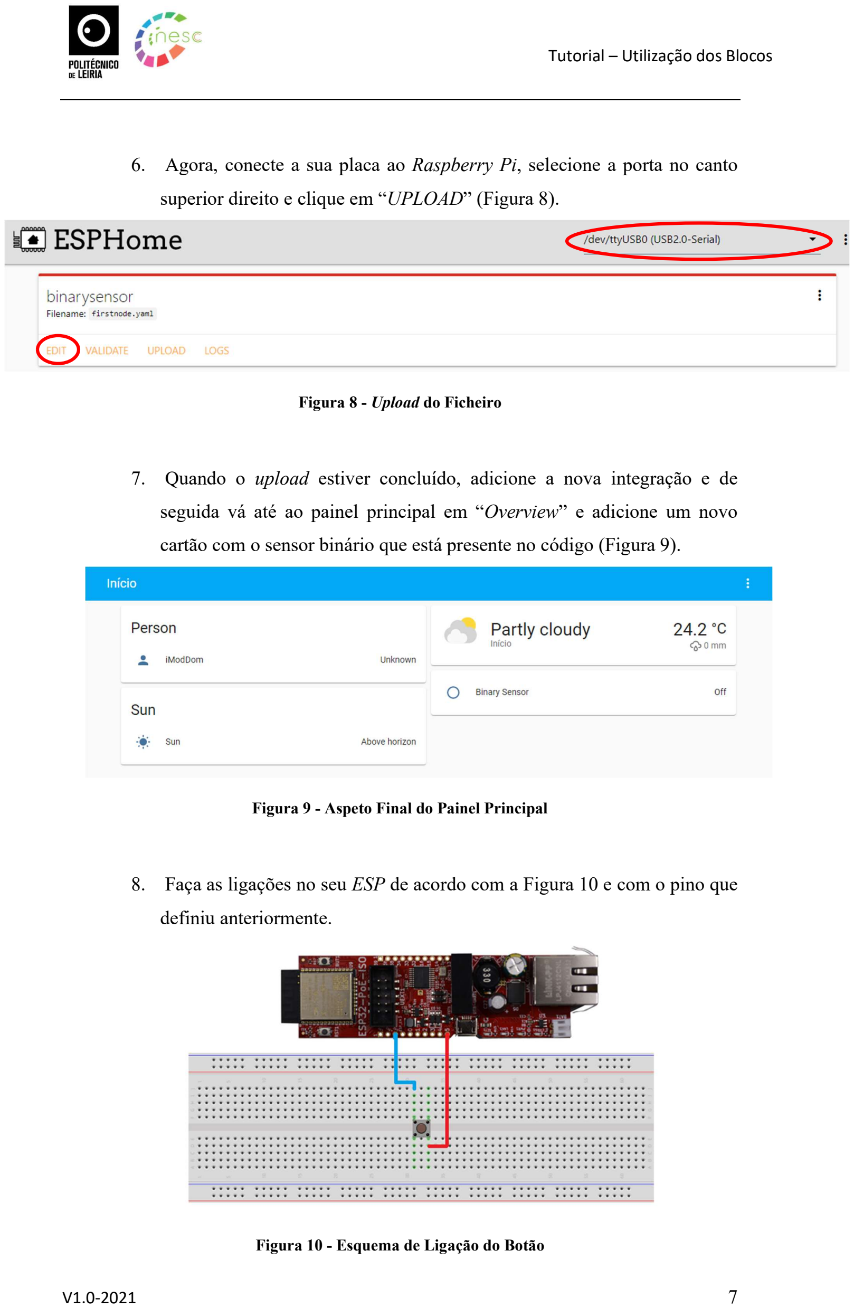
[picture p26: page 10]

V1.0-2021 | 7

### 6. Agora, conecte a sua placa ao Raspberry Pi, selecione a porta no canto

superior direito e clique em “UPLOAD” (Figura 8).

Figura 8 - Upload do Ficheiro

### 7. Quando o upload estiver concluído, adicione a nova integração e de

seguida vá até ao painel principal em “Overview” e adicione um novo cartão com o sensor binário que está presente no código (Figura 9).

Figura 9 - Aspeto Final do Painel Principal

### 8. Faça as ligações no seu ESP de acordo com a Figura 10 e com o pino que

definiu anteriormente.

Figura 10 - Esquema de Ligação do Botão

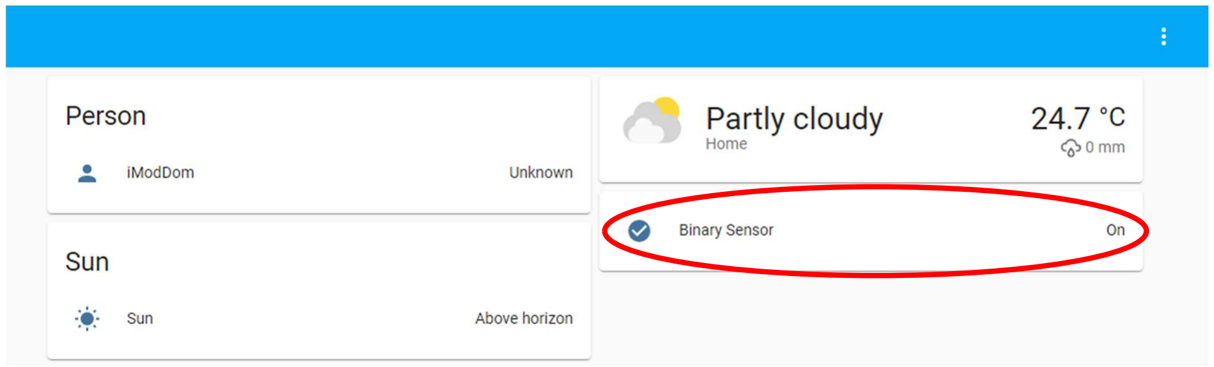
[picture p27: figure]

V1.0-2021 | 8

### 9. Verifique que ao clicar no botão o estado do sensor binário no Home

Assistant altera (Figura 11).

Figura 11 - Botão Acionado

### 2.1.2. Control a Light

Este bloco gera o código que permite controlar um LED.

### 1. Comece por arrastar o bloco “Control a Light” para o workspace e preencha

todos os campos do bloco com as mesmas informações do bloco anterior, sendo que neste bloco, o pino definido será para ligar o LED (Figura 12).

Figura 12 - Aspeto do Bloco

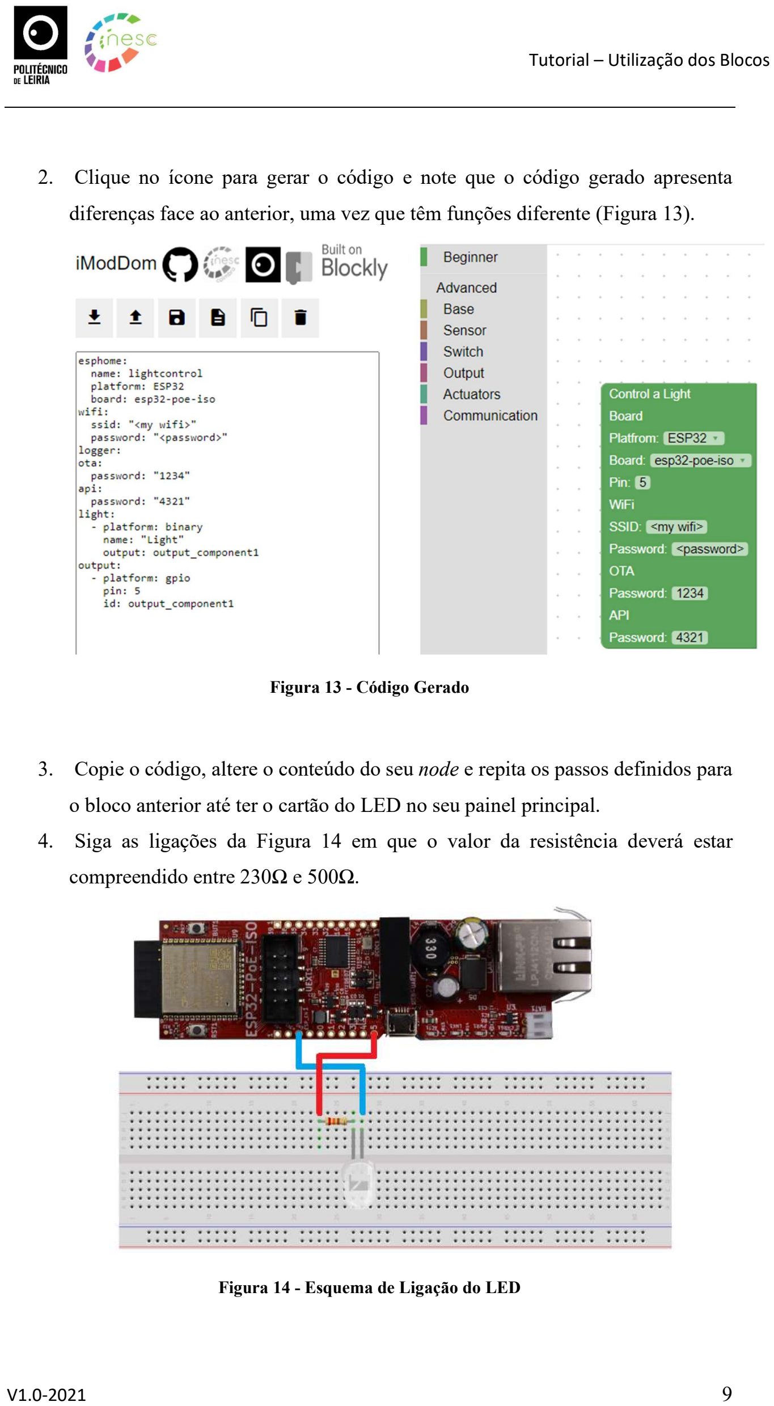
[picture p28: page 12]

V1.0-2021 | 9

### 2. Clique no ícone para gerar o código e note que o código gerado apresenta

diferenças face ao anterior, uma vez que têm funções diferente (Figura 13).

Figura 13 - Código Gerado

### 3. Copie o código, altere o conteúdo do seu node e repita os passos definidos para

o bloco anterior até ter o cartão do LED no seu painel principal.

### 4. Siga as ligações da Figura 14 em que o valor da resistência deverá estar

compreendido entre 230Ω e 500Ω.

Figura 14 - Esquema de Ligação do LED

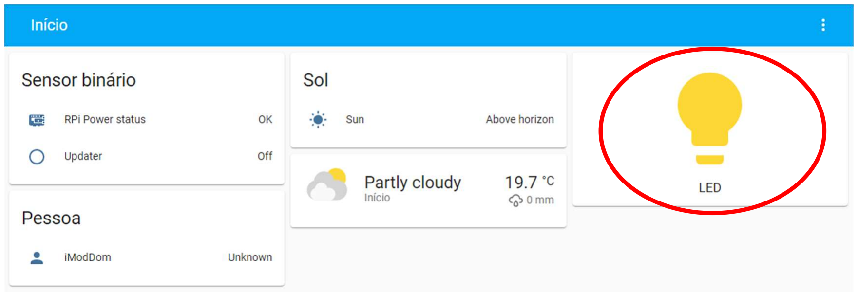
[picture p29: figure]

V1.0-2021 | 10

### 5. Como pode verificar, ao clicar no cartão do LED o estado do mesmo irá alterar

(Figura 15).

Figura 15 - Estado do LED

### 2.1.3. Control a Cover

O bloco “Control a Cover”, tal como o nome indica, permite controlar uns estores elétricos, desde a sua abertura, paragem e encerramento. Neste bloco em específico os estores têm uma duração de abertura de 5 segundos e outros 5 segundos para o seu encerramento.

### 1. Arraste o bloco para o workspace e preencha todos os campos, tal como nos

blocos anteriores, à exceção de que neste bloco existem cinco pinos a definir. O primeiro pino “Pin to open” será o pino no qual irá ligar o botão que irá abrir os estores, o segundo “Pin to close” o pino onde ligará o botão que permite fechar os estores, o terceiro “Pin to stop” onde se ligará o botão para parar os estores, no quarto pino “Open switch” ligará a saída que permite abrir os estores e no último “Close switch”, a saída que irá fechar os estores (Figura 16).

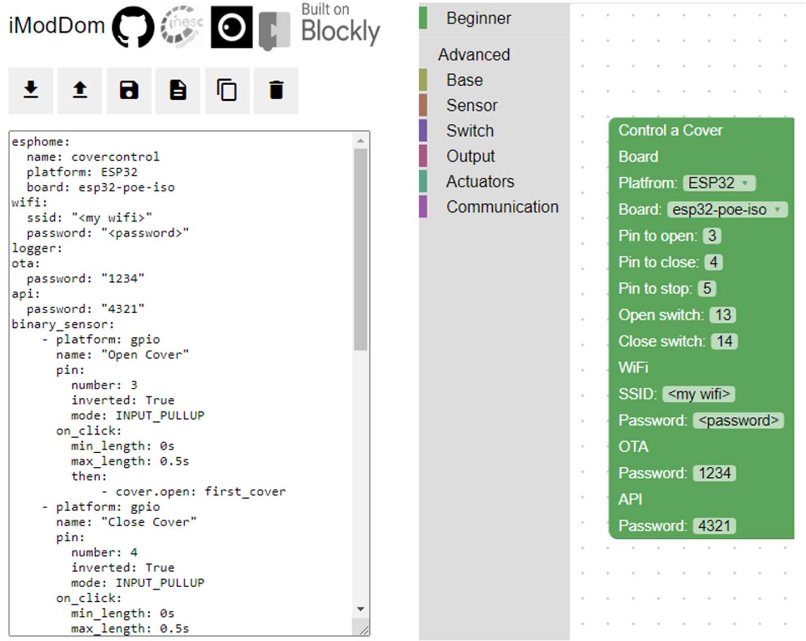
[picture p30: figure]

V1.0-2021 | 11

Figura 16 - Aspeto do Bloco

### 2. Agora com o bloco pronto, pode gerar o código, que será mais extenso e

complexo face aos anteriores, e repita todos os passos até ter adicionado os três botões e os dois switch ao painel principal (Figura 17).

Figura 17 - Código Gerado

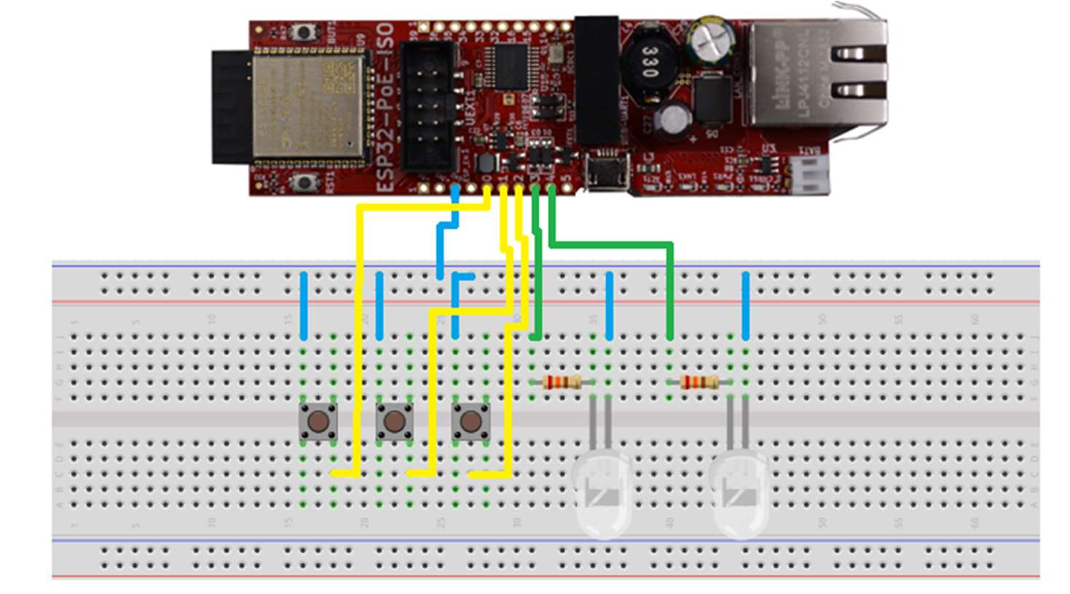
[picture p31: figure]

V1.0-2021 | 12
6. Faça as seguintes ligações para poder simular o controlo dos estores elétricos, onde os LEDs simulam a abertura e fecho dos mesmos (Figura 18). As duas resistências devem ter um valor compreendido entre 230Ω e 500Ω.

Figura 18 - Esquema de Ligações

### 3. Repare que agora, tanto pode controlar os estores elétricos clicando nos

botões que ligou ao seu ESP como clicando nos botões apresentados no Home Assistant (Figura 19). Note que só pode clicar nos botões no máximo durante 0.5 segundos para que as ações de abertura, encerramento ou paragem sejam efetuadas. Repare que se clicar no botão para abrir e de seguida para fechar ou vice versa, o que prevalece será sempre a última ordem para evitar que as duas sejam efetuadas em simultâneo, o que resultaria numa avaria do motor num caso prático.

Figura 19 - Funcionamento dos Estores Elétricos

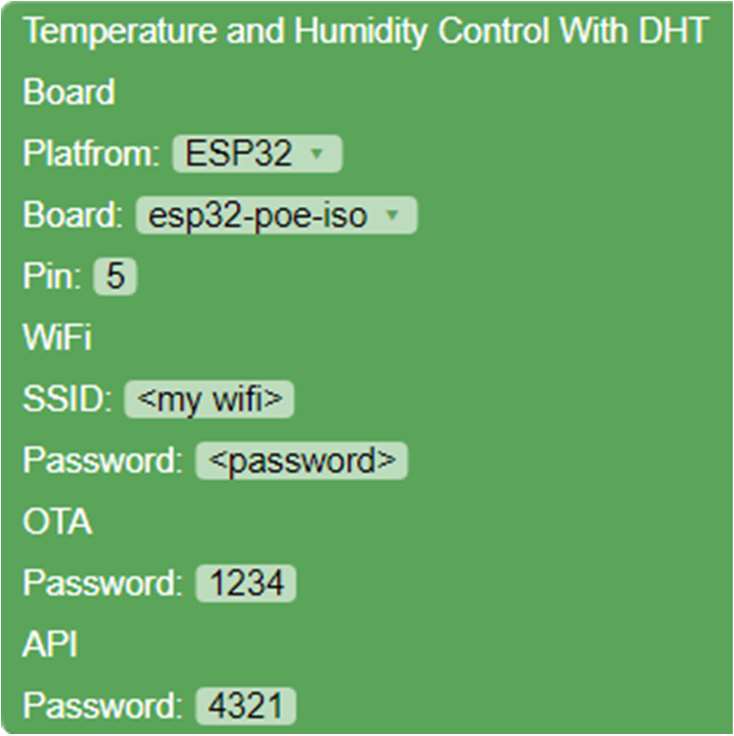
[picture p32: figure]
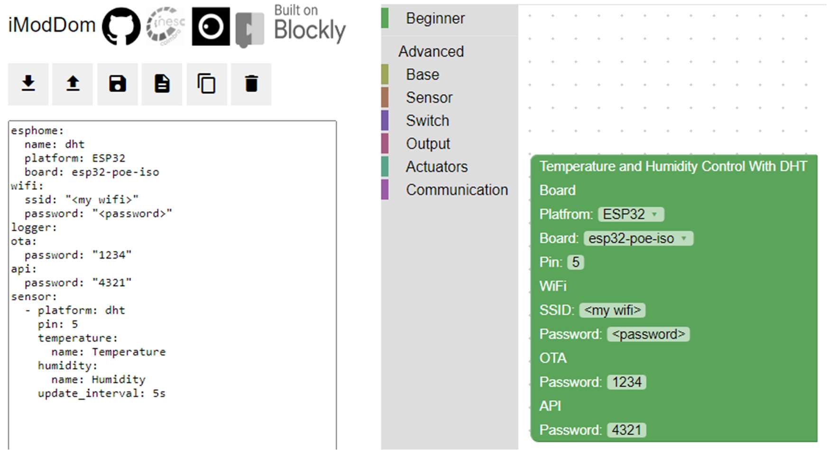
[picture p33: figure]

V1.0-2021 | 13

### 2.1.4. Temperature and Humidity Control With DHT

Através deste bloco é possível fazer leituras da temperatura e humidade com o sensor DHT, tanto o DHT11 como o DHT22, e visualizar os valores no Home Assistant.

### 1. Comece por arrastar o bloco para o workspace e de seguida preencha os

campos do mesmo tal como fez nos primeiros blocos, no campo “Pin” deve definir o pino ao qual vai ligar a saída do seu sensor DHT (Figura 20).

Figura 20 - Aspeto do Bloco

### 2. Gere o código e execute todos os passos até ter o cartão da humidade e da

temperatura apresentados no painel principal (Figura 21).

Figura 21 - Código Gerado

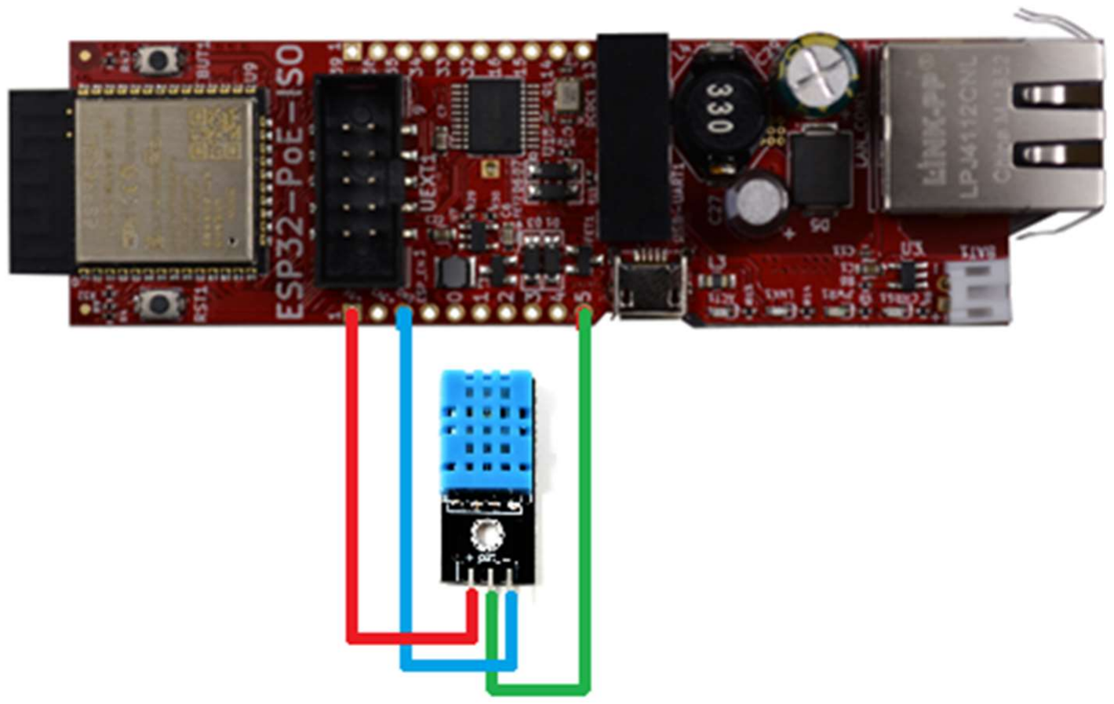
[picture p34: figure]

V1.0-2021 | 14
3. Ligue o sensor seguindo o esquema de ligações da Figura 22.

Figura 22 - Esquema de Ligações

### 4. Como pode confirmar, acendendo ao Home Assistant, pode visualizar

os valores de temperatura e humidade fornecidos pelo sensor (Figura 23).

Figura 23 - Visualização dos Valores

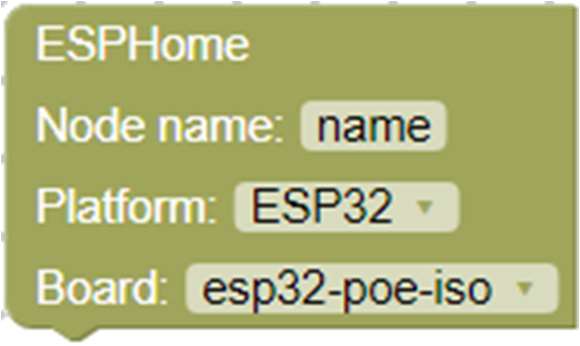
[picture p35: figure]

V1.0-2021 | 15

2.2.Utilização dos Blocos Advanced

Todos os blocos que estão incluídos na secção “Advanced”, já são mais complexos face à secção apresentada anteriormente e permitem gerar código mais completo.

### 2.2.1. Blocos Base

Na secção “Base” estão todos os blocos que geralmente são utilizados em todos os nodes ou aqueles que são mais gerais e não se incluem numa secção especifica. Todos os blocos desta secção só podem ser utilizados uma única vez e são do tipo “principais”, excetuando o bloco “I2C” que pode ser utilizado várias vezes.

### 2.2.1.1. ESPHome

Este bloco tem a função de atribuir um nome ao node, definir qual a plataforma a placa a utilizar (Figura 24). Note que a escolha da placa de desenvolvimento irá afetar a designação dos pinos, pelo que deve colocar a designação dos mesmos conforme se encontra na placa.

Figura 24 – ESPHome

V1.0-2021 | 16

### 2.2.1.2. Wifi

O bloco “Wifi” permite realizar a conexão ao WiFi, preenchendo no primeiro campo (“SSID”) com o nome da rede WiFi a conectar, e no último campo (“Password”) a password da rede. Este bloco tem ainda um encaixe lateral que permite, através de um outro bloco, definir o IP manualmente. Este bloco não pode ser utilizado se o bloco “Ethernet” estiver a ser utilizado.

Figura 25 – Wifi

### 2.2.1.3. IP

Através deste bloco é possível configurar o IP do node, colocando no primeiro campo (“Static ip”) o IP que deseja definir, no campo “Gateway” o gateway da sua rede e no último campo (“Subnet”), a subnet da sua rede. Este bloco apenas pode ser encaixado e utilizado com o bloco “Wifi” ou com o bloco “Ethernet”.

Figura 26 – IP

### 2.2.1.4. Ethernet

O bloco “Ethernet” tem a função de permitir uma ligação à rede via ethernet, onde no primeiro campo se define o chip de ethernet, no segundo campo (“MDC pin”) define-se o pino MDC, no terceiro campo (“MDIO pin”) é definido o pino MDIO, no quarto campo (“Clock mode”) seleciona-se o modo do clock e no campo “Power pin” define-se o pino através do qual controla a alimentação da placa. Este bloco contém

V1.0-2021 | 17

ainda um encaixe lateral onde se pode encaixar o bloco “IP”, para configurar o IP manualmente. Este bloco não pode ser utilizado se o bloco “Wifi” estiver a ser utilizado.

Figura 27 - Ethernet

### 2.2.1.5. API

O bloco “API”, tem a função de possibilitar a integração com o Home Assistant, sendo que para isso basta introduzir uma password no campo “API password” do bloco. Este bloco requer a utilização do bloco “Wifi” ou do bloco “Ethernet” e é do tipo “principal”, pelo que só poderá ser utilizado uma vez e encaixado em blocos do mesmo tipo.

Figura 28 - API

### 2.2.1.6. OTA

Este bloco permite fazer o upload do código via WiFi, sem ser necessário recorrer a um cabo USB, tendo em conta que o primeiro upload tem de ser feito sempre através do cabo USB e para que seja possível realizar o upload via WiFi é necessário que o nome do node seja o mesmo face ao programa que está no ESP. No campo “Safe mode” deste bloco é possível selecionar entre “True” e “False”, se estiver selecionado “True”, o safe mode é ativo e caso o ESPHome não consiga inicializar ao fim de 10 tentativas. irá inicializar em modo de segurança, desabilitando todos os componentes, e apenas a porta serial, o WiFi e o OTA serão inicializados, de modo que seja possível fazer o upload de um novo código. No campo “Password” define-se a password a

V1.0-2021 | 18

utilizar para realizar as atualizações via OTA. Este bloco requer a utilização do bloco “Wifi” ou “Ethernet”.

Figura 29 – OTA

### 2.2.1.7. Logger

O bloco “Logger” permite ativar as mensagens log, sendo que se pode selecionar uma das seguintes opções:

- NONE: Nenhuma mensagem é mostrada.
- ERROR: Apenas os erros são mostrados. Os erros são problemas que impedem o ESP de funcionar corretamente. São mostrados a vermelho.
- WARN: Os erros e os avisos são mostrados. Os avisos são problemas como leituras inválidas de sensores dos quais o ESP consegue recuperar, são mostrados a amarelo.
- INFO: Os erros e avisos são mostrados e também todas as mensagens de informações, são mostradas a verde.
- DEBUG: Todas as mensagens descritas anteriormente são apresentadas acrescentando ainda os valores das leituras de sensores e mensagens de estados, é mostrado a ciano
- VERBOSE: Semelhante ao “DEBUG”, acrescentando mensagens que geralmente são consideradas como spam, apresentadas a cinzento.
- VERY_VERBOSE: Todas as mensagens internas são apresentadas, incluindo os dados que são transmitidos nos barramentos de dados (I2C, SPI ou UART), são apresentadas a branco. Poderá fazer com que o dispositivo fique lento.

Figura 30 – Logger

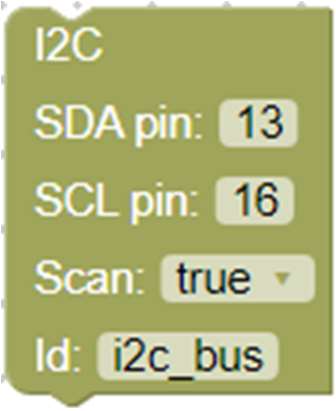
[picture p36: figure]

V1.0-2021 | 19

### 2.2.1.8. I2C

Este bloco permite definir o barramento I2C para que seja possível utilizar dispositivos que utilizem esse tipo de comunicação. No primeiro campo define-se o pino para a transmissão de dados, no segundo campo “SCL pin” define-se o pino da linha do clock, no campo “Scan” é possível escolher entre “true” e “false”, caso seja selecionada a primeira opção, o ESPHome irá fazer uma pesquisa de todos os endereços no barramento I2C. No último campo (“Id”) define-se o id do barramento I2C de forma a distinguir os vários barramentos caso haja mais do que um.

Figura 31 - I2C

### 2.2.1.9. Web Server

O bloco “Web Server” cria um web server tal como o nome indica, no campo “Port” deve definir em que porta é que o web server irá ser aberto. Para aceder ao mesmo pode utilizar o ip do node ou através de “<nome_do_node>.local/”. Note que a criação de um web server requer bastante memória do seu ESP e poderá gerar problemas, especialmente no ESP8266.

Figura 32 - Web Server

2.2.1.10.PCF8574

Este bloco permite utilizar o PCF8574, é um pequeno dispositivo que tem a função de adicionar entradas e saídas digitais. O PCF8574 em concreto, permite

V1.0-2021 | 20

expandir em até oito entradas ou saídas por dispositivo, num máximo de oito dispositivos, sendo que cada um deles necessita de um endereço que nunca pode ser repetido. Neste bloco já são apresentados o máximo de PCF8574 que podem ser utilizados em simultâneo e o utilizador deverá selecionar quantos deseja utilizar clicando na checkbox de cada um, sendo que o endereço é fixo para cada um e não pode ser alterado, o id de cada um também já está pré-definido, mas pode ser alterado desde que não seja repetido.

Figura 33 - PCF8574

### 2.2.2. Blocos Sensor

A secção “Sensor”, contém todos os blocos que estão relacionados a sensores, sejam os próprios sensores ou ações que possam ser geradas pelos mesmos. Nesta secção, apenas os blocos de cor mais escura, nomeadamente o bloco “Binary Sensor” e “Sensor”, é que são blocos do tipo “principais” e por isso apenas esses podem ser conectados a outros blocos principais.

### 2.2.2.1. Binary Sensor

Este bloco, apenas tem a função de inicializar o componente “Binary Sensor” (sensor binário), como é o caso de um botão ou de um sensor PIR. Nos encaixes exteriores podem ser encaixados todos os blocos “principais” e no encaixe interno, podem ser encaixados os blocos “Binary Sensor”, “Binary Sensor PCF8574”, “PIR Sensor” e “PIR Sensor PCF8574”. Este bloco só pode ser utilizado uma vez.

V1.0-2021 | 21

Figura 34 - Binary Sensor

### 2.2.2.2. Binary Sensor (componente)

Este bloco é utilizado para integrar o componente “Binary Sensor” no código, sendo que o encaixe superior e inferior apenas permite encaixar no interior do bloco anterior e nos blocos que representam sensores binários. Tem ainda um encaixe lateral onde poderá ser encaixado um bloco para realizar pequenas automações, através do bloco “Automations”. O primeiro campo tem a finalidade de definir o nome do componente, no segundo campo (“Id”) deverá atribuir um id que tem de ser único, no terceiro campo é onde se define o pino através do qual se vai ler o estado do sensor binário, no campo “Mode” poderá selecionar “input” que será uma entrada normal e os valores poderão sofrer flutuações, tem também a opção “input pullup” e “input pulldown” para evitar essas mesmas flutuações, sendo que o ESP faz uma pullup ou pulldown internamente (a opção “input pulldown” apenas pode ser utilizada no ESP32). Já no campo “Inverted” é possível escolher entre “True” e “False”, sendo que com a primeira opção irá inverter o valor lido no pino definido.

Figura 35 - Binary Sensor

### 2.2.2.3. Binary Sensor PCF8574

Este bloco tem a mesma função e características do anterior, à exceção de que neste se utiliza os pinos do I/O Expander e no anterior utilizam-se os pinos do ESP. Tendo isso em conta, os campos em comum têm as mesmas funções e características,

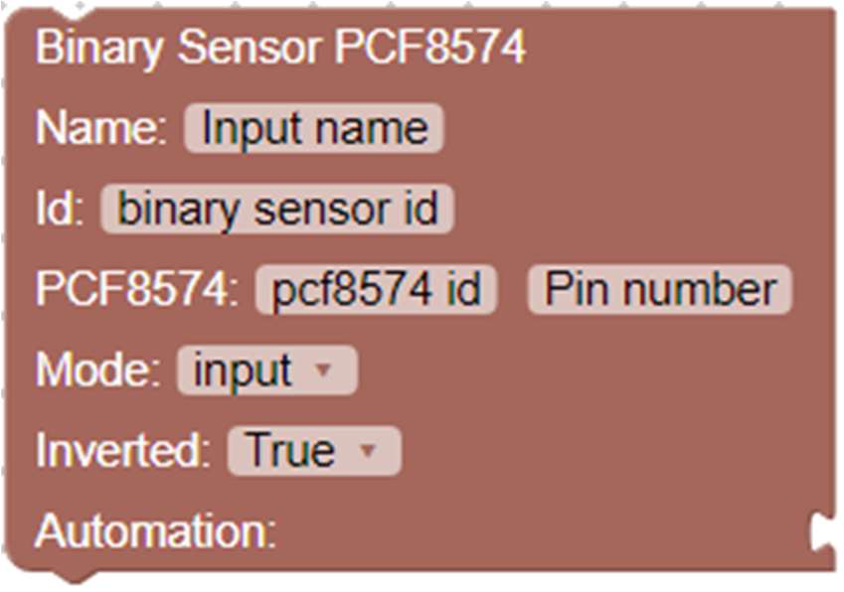
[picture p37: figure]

V1.0-2021 | 22

sendo apenas o campo “PCF8574” diferente, onde é necessário introduzir o id do PCF8574 previamente definido e o pino onde deseja ler o sensor binário, podendo ser um de oito pinos (de 0 a 7). Este bloco requer a utilização do bloco “PCF8574”.

Figura 36 - Binary Sensor PCF8574

### 2.2.2.4. PIR Sensor

Através do bloco “PIR Sensor” é possível integrar no código um sensor PIR (Passive Infrared Sensor), ou seja, um sensor de movimento. Para utilizar este bloco necessita de atribuir um nome ao sensor no primeiro campo, no campo “Id” definir um id único para o mesmo e no terceiro campo definir o pino do ESP através do qual irá fazer a leitura do sensor. Este bloco possui dois campos para realizar ações aquando da deteção e da não deteção de movimento, sendo que as ações apenas serão acionadas apenas no instante em que é detetado movimento, no caso do primeiro encaixe interior, e no instante em que o sensor deixou de detetar movimento, no caso do segundo encaixe interior. Nestes encaixes interiores apenas é possível encaixar o bloco “Binary Sensor Action” e o bloco “CAN bus Send Action”. Note que só é possível encaixar este bloco em blocos da mesma cor e que representem sensores binários ou no interior do bloco “Binary Sensor”.

Figura 37 - PIR Sensor

V1.0-2021 | 23

### 2.2.2.5. PIR Sensor PCF8574

Este bloco é igual ao anterior à exceção de que neste utiliza-se o PCF8574 para fazer a leitura do sensor PIR, definindo no campo “PCF8574” o id do I/O Expander e o número do pino. Este bloco requer a utilização do bloco “PCF8574”.

Figura 38 - PIR Sensor PCF8574

### 2.2.2.6. Automations

Este bloco tem a finalidade de incluir algumas automações nos sensores binários, nomeadamente no bloco “Binary Sensor” e “Binary Sensor PCF8574”, pois são os únicos blocos onde este bloco pode ser encaixado. Apresenta vários campos onde se podem introduzir várias ações, sendo que as ações que estiverem no campo “On Click” serão executadas quando, o botão é clicado, supondo que o sensor binário é um botão, no campo “On Double Click” quando existe um clique duplo no botão, no campo “On Multi Click” aquando o botão sofre um duplo clique ou um clique longo ou curto, no campo “On Press” as ações serão executadas quando um botão for pressionado e no campo “On Release” quando o botão deixar de ser pressionado.

V1.0-2021 | 24

Figura 39 – Automations

### 2.2.2.7. On Click

O bloco “On Click”, só pode ser encaixado no campo “On Click” do bloco “Automations”. Tem a finalidade de definir o tempo mínimo e máximo do clique necessário para que a ação, que é adicionada no encaixe interior seja executada. No encaixe interior deste bloco apenas é possível encaixar o bloco “Binary Sensor Action” e “CAN bus Send Action”.

Figura 40 - On Click

### 2.2.2.8. On Double Click

Este bloco é bastante semelhante ao anterior, no entanto tem o objetivo de definir a duração mínima e máxima dos duplos cliques para que a ação seja executada, ou seja, sempre que existir um clique duplo em que cada um tenha uma duração compreendida entre a duração mínima e máxima definida. Este bloco apenas pode ser encaixado no campo “On Double Click” do bloco “Automations” e o seu encaixe interior apenas aceita o bloco “Binary Sensor Action” e “CAN bus Send Action”.

V1.0-2021 | 25

Figura 41 - On Double Click

### 2.2.2.9. On Multi Click

O bloco “On Multi Click”, tem como objetivo executar várias ações para determinados tipos de cliques, sendo que na zona “Double click” deve definir o tempo máximo em que o botão, no primeiro clique, pode estar no estado ON, o tempo máximo que pode estar a OFF, o tempo máximo em que no segundo clique pode estar a ON e o tempo mínimo que necessita de estar a OFF para que execute a ação do primeiro encaixe do bloco. Nas zonas “Single long click” e “Single short click” é necessário definir o intervalo de tempo em que deseja que o botão esteja no estado ON e o tempo mínimo que esteja no estado OFF para que execute a ação correspondente. Nos encaixes interiores deste bloco só é possível encaixar os blocos “Binary Sensor Action” e “CAN bus Send Action” e o encaixe superior só aceita o encaixe do campo “On Multi Click” do bloco “Automations”.

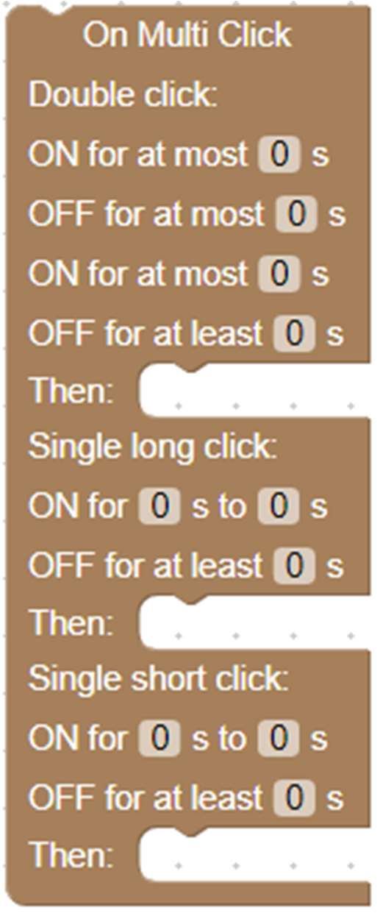
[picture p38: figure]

V1.0-2021 | 26

Figura 42 - On Multi Click

2.2.2.10.Binary Sensor Action

Este bloco é o responsável pela escolha das ações a executar, sendo que só pode ser encaixado nos campos “On Press” e “On Release” do bloco “Automations” e nos encaixes interiores dos blocos “On Click”, “On Double Click”, “On Multi Click”, “PIR Sensor”, “PIR Sensor PCF8574” em outros blocos “Binary Sensor Action” ou “CAN bus Send Action”. Só tem dois campos, um deles é para selecionar a ação a executar e o outro para definir o id do componente dessa mesma ação, sendo as opções de ações as seguintes:

- Switch toggle: Inverte o estado do componente switch, independentemente do estado atual.
- Switch turn on: Coloca o componente switch em questão no estado “ligado”.
- Switch turn off: Coloca o componente switch em questão no estado “desligado”.
- Cover open: Abre os estores elétricos definidos no campo “id”.
- Cover close: Fecha os estores elétricos definidos no campo “id”.

V1.0-2021 | 27
- Cover stop: Caso estes estejam em movimento, para os estores elétricos definidos no campo “id”.
- Light toggle: Inverte o estado do componente light.
- Light turn on: Liga o componente light em questão.
- Light turn off: Desliga o componente light definido no campo “id”.
- Fan toggle: Inverte o estado do componente fan.
- Fan turn on: Liga o componente fan definido no campo “id”.
- Fan turn off: Desliga o componente fan.
- Logger: Apresenta a mensagem escrita no campo “id” na consola.

Figura 43 – Binary Sensor Action

2.2.2.11.CAN bus Send Action

Este bloco é bastante semelhante ao anterior, sendo que as suas características de encaixe são iguais, com a diferença de que este permite enviar dados através do protocolo de comunicação CANbus. Este bloco requer a utilização do bloco “CAN Bus”. No primeiro campo deste bloco é necessário introduzir o id do componente CANbus, no campo “Can id” é necessário colocar o id do dispositivo para o qual enviará os dados e no último campo deverá colocar os dados a transmitir, sendo que terão de ser introduzidos num dos seguintes formatos:

- ‘mensagem’: Para enviar uma mensagem escrita.
- [0x01]: Para enviar um byte
- [0x01, 0x02, 0x03, 0x04, 0x05, 0x06, 0x07, 0x08]: Para enviar vários bytes, até num máximo de 8.

Figura 44 - CAN bus Send Action

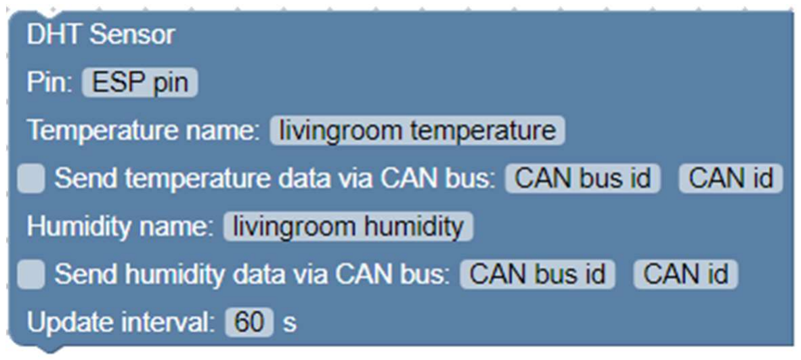
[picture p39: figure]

V1.0-2021 | 28

2.2.2.12.Sensor

O bloco “Sensor” é do tipo “principal” e por isso pode ser encaixado em outros blocos do mesmo tipo, tem a função de inicializar o componente “Sensor” para que seja possível utilizar os vários sensores disponíveis. No seu encaixe interior apenas podem ser encaixados blocos de cor azul clara que representem sensores. Este bloco apenas pode ser utilizado uma vez, não se podendo repetir.

Figura 45 – Sensor

2.2.2.13.DHT Sensor

O bloco “DHT Sensor” permite integrar o sensor DHT, tanto o DHT11 como o DHT22, sendo que no primeiro campo se deve definir o pino que irá receber a leitura do sensor, no campo “Temperature name” deve introduzir o nome a apresentar na componente de temperatura, no campo “Humidity name” o nome a apresentar na componente de humidade e no último campo o intervalo de tempo, em segundos, que o ESPHome deverá atualizar os valores. Caso pretenda enviar os valores do sensor através do protocolo de comunicação CANbus, deverá selecionar a checkbox do valor que pretende enviar, tal como o CANbus id do dispositivo CAN e o CAN id da mensagem a enviar, o CAN id deverá ser diferente e único. Este bloco apenas pode ser encaixado no encaixe interior do bloco “Sensor” e em blocos da mesma cor e caso selecione alguma das checkbox será necessário utilizar o bloco “CAN Bus”

Figura 46 - DHT Sensor

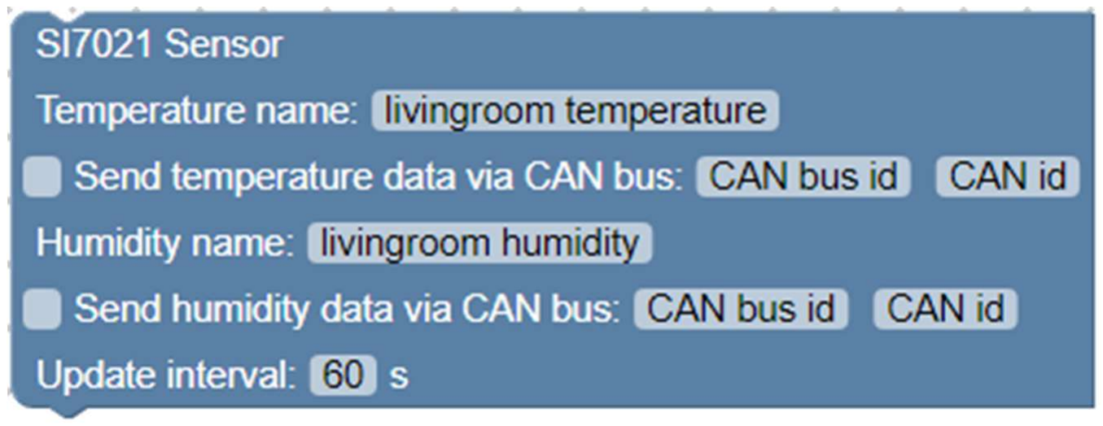
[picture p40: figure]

V1.0-2021 | 29

2.2.2.14.SI7021 Sensor

Este bloco é bastante semelhante ao anterior, alterando o facto de este integrar o sensor SI7021, também ele de temperatura e humidade, no entanto neste bloco não é necessário definir o pino de leitura, já que o ESPHome consegue detetar automaticamente o endereço do sensor, sendo necessário, para a utilização deste bloco, o componente I2C que pode ser integrado utilizando o bloco “I2C”. Todas as características dos campos e conexões do bloco são iguais às do bloco anterior.

Figura 47 - SI7021 Sensor

2.2.2.15.BMP280 Sensor

Este bloco integra o sensor BMP280, é um sensor de temperatura e pressão, comunica via I2C e como tal é necessário adicionar o componente I2C através do bloco “I2C”. No primeiro campo define-se o nome a apresentar para o valor de temperatura, no campo “Pressure name” define-se o nome a apresentar para o valor de pressão, no campo “Address” deve selecionar o endereço do sensor, podendo variar entre 0x77 e 0x76 (geralmente é 0x77), no último campo define-se a frequência com que o ESPHome deve atualizar os valores. Este bloco apenas pode ser encaixado no bloco “Sensor” ou em blocos da mesma cor e as características dos campos de envio de dados via CANbus são iguais às do bloco anterior.


V1.0-2021 | 30

Figura 48 – BMP280 Sensor

2.2.2.16.MQ-7

O bloco “MQ-7” integra o sensor MQ-7. Este sensor mede os níveis de monóxido de carbono presente no ar. No campo “Pin” deste bloco é necessário definir o pino do ESP através do qual se irão receber as leituras do sensor, de notar que o pino terá de ser capaz de receber valores analógicos, no segundo campo deverá definir o id do sensor que deve ser único, e no último campo a frequência com que o ESPHome atualiza os valores das leituras. As características dos encaixes bem como de envio de dados via CANbus são iguais às do bloco anterior. Este sensor necessita de calibração para que os valores do mesmo sejam coerentes.

Figura 49 - MQ-7

2.2.2.17.Template Sensor

A função deste bloco é criar um template de um sensor onde os valores do mesmo serão fornecidos através do bloco “CAN bus Receive Action”, ou seja, permite visualizar os valores de um sensor, que são recebidos através do protocolo de comunicação CANbus, na forma de sensor no Home Assistant. Este bloco apenas poderá ser encaixado em blocos da mesma cor e terá de ser utilizado em conjunto com o bloco “CAN bus Receive Action”. No seu primeiro campo, deverá atribuir um nome ao valor

V1.0-2021 | 31

que irá apresentar, no campo “Id” deve definir um id para o template do sensor, no campo “Unit of measurement” terá de colocar a unidade do valor que o template apresentará, sendo que pode selecionar um das seguintes opções:

- ºC: Graus Celsius.
- ºF: Graus Fahrenheit.
- %: Percentagem.
- hPa: Hectopascal.
- mbar: Milibar.
- lx: Lux.
- lm: Lúmen.
- CO: Monóxido de carbono.
- CO2: Dióxido de carbono.
- V: Diferença de potencial.
- A: Corrente elétrica.
- Wh: Watt-hora.
- kWh: Quilowatt-hora.
- W: Watt.
- kW: Quilowatt.

No campo “Device class” deve selecionar a classe dos valores, para que no Home Assistant seja mostrado o ícone certo, pode selecionar uma das seguinte opções:

- Temperature: Para valores de temperatura.
- Humidity: Para valores de humidade.
- Pressure: Para valores de pressão.
- Illuminance: Para valores de iluminância.
- Carbon moxide: Para valores de monóxido de carbono.
- Carbon dioxide: Para valores de dióxido de carbono.
- Battery: Para níveis de bateria.
- Voltage: Para valores de diferença de potencial.
- Current: Para valores de corrente elétrica.
- Energy: Para valores de energia.
- Power: Para valores de potência.

V1.0-2021 | 32

No campo “Update interval”, deve introduzir o intervalo de tempo, em segundos, que deseja que os valores sejam atualizados. Note que a seleção das unidades de medida não altera os valores do sensor em questão, apenas tem o objetivos de mostrar as unidades de medida no Home Assistant, cabe ao utilizador verificar a unidade dos valores.

Figura 50 - Template Sensor

### 2.2.3. Blocos Switch

A secção de blocos “Switch” permite utilizar os pinos do ESP para acionar alguns dispositivos, seja com recurso a relés ou ligando diretamente ao ESP. Nesta secção apenas o bloco “Switch” é do tipo “principal” e por isso apenas esse pode ser conectado a outros do mesmo tipo.

### 2.2.3.1. Switch

O bloco “Switch”, permite inicializar o componente switch possibilitando assim a utilização de todos os blocos desta secção. Este bloco é do tipo “principal” e só pode ser utilizado uma vez.

Figura 51 – Switch

V1.0-2021 | 33

### 2.2.3.2. Switch (componente)

Este bloco permite definir um pino do ESP como uma saída e apenas pode ser encaixado no interior do bloco “Switch” ou em blocos da mesma cor. No primeiro campo do bloco deve atribuir um nome para o switch, no campo “Pin” deverá definir o pino que será controlado, caso pretenda inverter o estado da sua saída, pode fazê-lo selecionando a opção “True” no campo “Inverted”. No campo “Id” deve introduzir o id que pretende atribuir ao componente e este tem de ser único. Este bloco permite realizar o interlock entre dois componentes switch, o interlock é útil em casos onde existem duas saídas que não podem ser acionadas em simultâneo, o interlock impedirá que isso aconteça. De modo a acionar essa função, basta selecionar a checkbox “Interlock”, atribuir um nome ao interlock que deseja fazer e no terceiro e quarto campo dessa linha, introduzir o id de cada switch que deseja que não sejam acionados em simultâneo. Deverá fazer este procedimento em ambos os blocos “Switch”, sendo que os nomes dos interlock têm de ser diferentes, veja-se o exemplo da Figura 53. Através deste bloco, é também possível ativar o restore mode, que permite ao ESPHome, em caso de falha, recuperar o estado do switch ou colocar o estado do mesmo a ON ou OFF quando o ESP ligar, para isso basta selecionar a checkbox do último campo e selecionar uma das várias opções da lista:

- Always OFF: Sempre que o ESP ligar o estado do switch será OFF.
- Always ON: Sempre que o ESP ligar o estado do switch será ON.
- Restore default OFF: Ao iniciar, o ESPHome irá tentar recuperar o estado anterior do switch, caso não seja possível a recuperação o mesmo iniciará com o estado OFF.
- Restore default ON: Ao iniciar, o ESPHome irá tentar recuperar o estado anterior do switch, caso não seja possível a recuperação o mesmo iniciará com o estado ON.


V1.0-2021 | 34

Figura 52 – Switch (componente)

Figura 53 - Exemplo de Interlock

### 2.2.3.3. Switch PCF8574

Este bloco é idêntico ao anterior em todos os aspetos, à exceção de que neste o pino a controlar não será do ESP, mas sim do PCF8574, como tal no campo “PCF8574” deverá introduzir o id do PCF8574 e o pino do mesmo ao qual vai ligar a sua saída. Este bloco requer a utilização do bloco “PCF8574”.

V1.0-2021 | 35

Figura 54 - Switch PCF8574

### 2.2.3.4. Restart Switch

O bloco “Restart Switch” tem o objetivo de criar um switch que permite reinicializar o ESP. O bloco apenas tem um campo, onde deve definir um nome para o switch e este bloco pode ser encaixado no interior do bloco “Switch” ou em qualquer um da mesma cor.

Figura 55 - Restart Switch

### 2.2.3.5. Shutdown Switch

Este bloco permite desligar o node através de um switch, colocando-o em deep sleep. Após isso a única maneira de iniciar o node é clicando no botão de reset do ESP ou desconectar o ESP da alimentação e voltar a conectá-lo à mesma. Este bloco tem as mesmas características de encaixes do anterior.

Figura 56 - Shutdown Switch

### 2.2.4. Blocos Output

A secção de blocos “Output”, permite utilizar pinos do ESP como saída, no entanto, ao contrário dos blocos da secção anterior, estes não são apresentados no Home

V1.0-2021 | 36

Assistant nem no web server. Estes blocos são apenas blocos intermediários que podem ser utilizados com blocos “Light” por exemplo.

### 2.2.4.1. Output

O bloco “Output” é do tipo “principal”, e como tal apenas pode ser encaixado em outros blocos do mesmo tipo e utilizado uma única vez. Tem o objetivo de inicializar o componente output, de modo a possibilitar a utilização de blocos desta secção.

Figura 57 – Output

### 2.2.4.2. Output (componente)

Este bloco permite controlar um pino do ESP como saída, de forma intermediária. No seu primeiro campo deve definir o pino do ESP a controlar, no campo “Inverted” pode inverter o estado da saída escolhendo a opção “True”, e no último campo deve atribuir, ao componente, um id que tem de ser único. Este bloco apenas pode ser encaixado no interior do bloco “Output” e nos blocos da mesma cor.

Figura 58 - Output (componente)

### 2.2.4.3. Output PCF8574

O bloco “Output PCF8574” possui as mesmas características face ao anterior, alterando o facto de que neste bloco o pino a ser controlado é do PCF8574, e por isso, no primeiro campo deve introduzir o id do mesmo e o número do pino a controlar. Este bloco requer a utilização do bloco “PCF8574”.

V1.0-2021 | 37

Figura 59 - Output PCF8574

### 2.2.5. Blocos Actuators

Esta secção de blocos inclui todos os blocos que permitem acionar saídas de componentes específicos. Os blocos “Light” e “Fan” desta secção têm de ser utilizados em conjunto com o bloco “Output”, para que exista uma saída possível de acionar, já os blocos “Cover” e “Endstop Cover” terão de ser utilizados juntamente com o bloco “Switch” e o bloco “Endstop Cover” necessita também de dois blocos “Binary Sensor”.

### 2.2.5.1. Light

Este bloco permite inicializar o componente light e é do tipo “principal”, pelo que só poderá ser encaixado em blocos desse tipo e apenas pode ser utilizado uma vez.

Figura 60 – Light

### 2.2.5.2. Light (componente)

Através deste bloco pode integrar o componente light no seu node e assim controlar uma fonte de luz. Este bloco apenas pode ser encaixado no interior do bloco “Light”. No primeiro campo do bloco deve atribuir um nome ao componente, no campo “Output” deve colocar o id do componente output ao qual estará ligada a fonte de luz, no campo “Id” necessita de atribuir um id único ao componente light e no último campo pode selecionar a checkbox de modo que o ESPHome, em caso de falha, tente recuperar o estado do componente em questão ou colocar o estado do mesmo a ON ou OFF quando o ESP ligar, para isso basta selecionar uma das várias opções da lista:

- Always OFF: Sempre que o ESP ligar o estado da light será OFF.

V1.0-2021 | 38
- Always ON: Sempre que o ESP ligar o estado da light será ON.
- Restore default OFF: Ao iniciar, o ESPHome irá tentar recuperar o estado anterior da light, caso não seja possível a recuperação o mesmo iniciará com o estado OFF.
- Restore default ON: Ao iniciar, o ESPHome irá tentar recuperar o estado anterior da light, caso não seja possível a recuperação o mesmo iniciará com o estado ON.

Figura 61 - Light (componente)

### 2.2.5.3. Fan

O bloco “Fan” possibilita a integração do componente fan, é um bloco do tipo “principal”, o que faz com que apenas seja possível utilizá-lo uma vez e encaixá-lo em outros blocos do mesmo tipo.

Figura 62 – Fan

### 2.2.5.4. Binary Fan

Este bloco permite controlar o estado de uma ventoinha. No campo “Name” é pedido que atribua um nome ao componente, no segundo campo deve atribuir um id que seja único e no último campo deve introduzir o id do componente output onde a ventoinha estará ligada. Este bloco só pode ser encaixado no interior do bloco “Fan”.

V1.0-2021 | 39

Figura 63 - Binary Fan

### 2.2.5.5. Cover

O bloco “Cover” possibilita a integração do componente cover e a utilização dos seus blocos. É um bloco do tipo “principal”, ou seja, apenas poderá ser encaixado em blocos do mesmo tipo e só pode ser utilizado uma única vez.

Figura 64 – Cover

### 2.2.5.6. Cover (componente)

Este bloco permite controlar uns estores elétricos, sendo que no primeiro campo deve atribuir um nome ao componente e no segundo campo um id único ao mesmo. No campo “Open action” deverá colocar as ações que pretende realizar quando é dada ordem de abertura, o mesmo se passa nos campos “Close action” e “Stop Action”, para as ordens de fecho e paragem, respetivamente. No campo “Open duration” deverá introduzir o intervalo de tempo, em segundos, que os estores elétricos demoram a abrir e no campo “Close duration”, o intervalo de tempo que demoram a fechar, note que é de extrema importância que este valor seja certo já que os estores apenas irão parar de abrir e/ou fechar passado esse tempo (caso não seja bem definido o motor poderá entrar em esforço). Os encaixes interiores deste bloco apenas permitem encaixar o bloco “Cover Action” desta secção e os encaixes superior e inferior só permitem que o bloco seja encaixado no bloco “Cover” e em blocos da mesma cor. Este bloco requer a implementação de duas saídas através do bloco “Switch (componente)” e que os seus encaixes interiores estejam preenchidos.


V1.0-2021 | 40

Figura 65 - Cover (componente)

### 2.2.5.7. Endstop Cover

Este bloco permite controlar uns estores elétricos tal como o bloco anterior, no entanto, neste bloco a abertura e fecho dos estores será controlada através de sensores binários, ou seja, os estores só irão parar de fechar ou abrir quando o respetivo sensor for acionado, contudo, é necessário preencher os campos “Open duration” e “Close duration”. Todas as configurações deste bloco são iguais ao anterior, sendo que neste é necessário introduzir o id do sensor que irá detetar a abertura total e o fecho total, nos campos “Open endstop” e “Close endstop”, respetivamente. Este bloco requer a implementação de duas saídas através do bloco “Switch (componente)” e que os seus encaixes interiores estejam preenchidos, tal como a implementação de dois sensores binários através do bloco “Binary Sensor”.

Figura 66 - Endstop Cover

V1.0-2021 | 41

### 2.2.5.8. Cover Action

O bloco “Cover Action” tem a função de alterar o estado dos componentes switch quando dada ordem de abertura, fecho ou paragem dos estores elétricos, sendo que para isso, deve selecionar o estado que deseja e inserir o id do switch do qual pretende alterar o estado. Este bloco apenas pode ser encaixado em blocos iguais ou nos encaixes interiores dos blocos “Cover” e “Endstop Cover”.

Figura 67 - Cover Action

### 2.2.6. Blocos Communication

Esta secção de blocos inclui todos os blocos que permitem realizar a comunicação entre dispositivos via CANbus.

### 2.2.6.1. SPI

O bloco “SPI”, permite inicializar o componente SPI e desse modo adicionar outros blocos que dependam desse mesmo componente. Este bloco é do tipo “principal” e por isso, só pode ser encaixado noutros blocos do mesmo tipo. No primeiro campo deve definir o pino a utilizar para a linha do clock, no campo “Mosi pin” é onde se define o pino da linha mosi, através da qual o dispositivo master irá enviar os dados para os dispositivos slave, no campo “Miso pin” deverá definir o pino a utilizar para a linha miso, linha essa onde os dispositivos slave enviam os dados para os dispositivos master. No último campo, é necessário definir um id único para o barramento SPI.

Figura 68 – SPI


V1.0-2021 | 42

### 2.2.6.2. CAN Bus

O bloco “CAN Bus” possibilita a comunicação entre dispositivos via CANbus, que é um protocolo de comunicação que utiliza apenas duas linhas para a sua comunicação. Este bloco é do tipo “principal”, o que faz com que só possa ser encaixado em blocos do mesmo tipo e utilizado uma vez. Este bloco requer a utilização do bloco “SPI”. No primeiro campo deste bloco deve definir um id para o componente CANbus e no segundo campo, um id para identificar o dispositivo em questão, no campo “Use extended id” ao selecionar a opção “True” o componente irá suportar um espaço de 29 bits para o Can id, caso selecione “False” suportará um espaço de 11 bits. No campo “CS pin” deve definir o pino da linha chip select (CS), no campo “Bit rate” deverá selecionar uma das várias velocidades de comunicação, no campo “clock” deverá selecionar a frequência do clock utilizada no seu CANbus transceiver, no encaixe interior do bloco, deve colocar as ações que deseja executar através do bloco “CAN bus Receive Action” (só este bloco é suportado no encaixe), no campo “Mode” é necessário selecionar uma das seguintes opções de funcionamento:

- NORMAL: Irá ter o funcionamento normal, recebe e envia dados.
- LOOPBACK: Pode ser utilizado para testar as ligações do componente SPI, pelo que irá enviar mensagens e recebê-las de volta.
- LISTENONLY: Neste modo, o CANbus apenas irá receber mensagens.

Figura 69 - CAN Bus


V1.0-2021 | 43

### 2.2.6.3. CAN bus Receive Action

Este bloco apenas pode ser encaixado no encaixe interior do bloco “CAN Bus” e em blocos da mesma cor. O bloco “CAN bus Receive Action”, permite executar determinadas ações quando se recebe uma mensagem de determinado dispositivo, sendo que para isso basta introduzir o id da mensagem CANbus, do qual irá receber a mensagem, no primeiro campo. No último campo deverá introduzir o id do componente da ação a executar e selecionar uma ação da lista:

- Switch toggle: Inverte o estado do componente switch, independentemente do estado atual.
- Switch turn on: Coloca o componente switch em questão no estado “ligado”.
- Switch turn off: Coloca o componente switch em questão no estado “desligado”.
- Cover open: Abre os estores elétricos definidos no campo “id”.
- Cover close: Fecha os estores elétricos definidos no campo “id”.
- Cover stop: Caso estes estejam em movimento, para os estores elétricos definidos no campo “id”.
- Light toggle: Inverte o estado do componente light.
- Light turn on: Liga o componente light em questão.
- Light turn off: Desliga o componente light definido no campo “id”.
- Fan toggle: Inverte o estado do componente fan.
- Fan turn on: Liga o componente fan definido no campo “id”.
- Fan turn off: Desliga o componente fan.
- Receive sensor data: Coloca os valores recebidos no id definido no campo “Can id” no template definido através do seu id no campo “id”.
- Logger: Apresenta a mensagem escrita no campo “id” na consola.

Figura 70 – CAN bus Receive Action

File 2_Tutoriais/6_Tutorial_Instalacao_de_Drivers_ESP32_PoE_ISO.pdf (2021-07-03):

# iModDom


V1.0-2021

# Tutorial - Instalação de Drivers ESP32-PoE-ISO

Elaborado por:
Marco Pereira - 2190516

Orientado por:
Luís Bento
Carlos Neves

V1.0-2021

Tutorial - Instalação de Drivers ESP32-PoE-ISO

### Índice


V1.0-2021 | 1

### 1. Instalação dos Drivers

Se ao tentar fazer upload para a placa ESP32-PoE-ISO, aparecer um erro a indicar que a placa não está conectada, muito provavelmente necessitará de instalar os drivers da mesma.

### 1. Aceda ao seguinte link:

https://www.olimex.com/Products/IoT/ESP32/ESP32-POE-ISO/opensource-hardware.
2. Será direcionado para a página da Figura 1.

Figura 1 - Página Web

### 3. Fazendo scroll para a parte de baixo da página encontrará uma secção onde

contém os drivers, selecione aquele que se adequa ao seu sistema operativo e descompacte o ficheiro transferido (Figura 2).

Figura 2 - USB Drivers


V1.0-2021 | 2
4. Execute o ficheiro descompactado (Figura 3).

Figura 3 - Ficheiro a Executar

5. Na janela que surgirá, basta clicar em “INSTALL” (Figura 4).

Figura 4 - Janela de Instalação

### 6. Quando os drivers forem instalados com sucesso aparecerá a mensagem da

Figura 5 e já conseguirá fazer o upload.

Figura 5 - Mensagem de Instalação Concluída

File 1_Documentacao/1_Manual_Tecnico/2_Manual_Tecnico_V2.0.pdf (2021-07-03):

# iModDom

V1.0-2021

# Manual Técnico V2.0

Elaborado por:
Marco Pereira - 2190516

Orientado por:
Luís Bento
Carlos Neves

V1.0-2021

Manual Técnico V2.0

### Índice

V1.0-2021 | 1

### 1. Introdução

O projeto iModDom consiste num ecossistema de hardware e software desenvolvido de forma a ser utilizado em conjunto para aplicações em domótica. A parte de hardware do projeto consiste em três placas de circuito impresso desenvolvidas para albergar todos os componentes com o objetivo de obter uma solução compacta e de fácil utilização. Já a parte de software consiste numa página web desenvolvida para o projeto, onde contém ferramentas que possibilitam a programação, do respetivo hardware, através de blocos. O projeto foi desenvolvido com o intuito e objetivo de ser uma solução económica e que permitisse a sua utilização aos utilizadores sem conhecimentos na área da programação.
Neste documento poderá encontrar uma descrição bem como uma lista de todo o material necessário, a nível de hardware, para a realização deste projeto, também irá ficar a conhecer os passos necessários para a preparação, processo de soldadura e montagem da versão V2.0 do hardware do projeto.


V1.0-2021 | 2

### 2. Descrição dos Componentes

Nesta secção todos os componentes utilizados no projeto irão ser descritos detalhadamente, de forma a dar a conhecer o funcionamento e características de cada um.

### 1. ESP32-PoE-ISO

O ESP32-PoE-ISO é uma placa de desenvolvimento baseada no microcontrolador ESP32, fabricado pela Espressif Systems. Esta placa contém WiFi, Bluetooth Low Energy (BLE) e ethernet, suportando Power over Ethernet (PoE) através do chip Si3402-B, seguindo o padrão IEEE 802.3. Pode também ser alimentada através do seu conector de bateria ou através da sua porta micro USB, sendo também utilizada para programar a placa, a tensão de alimentação da placa através destas duas vias não deverá exceder os 5V DC. A placa tem uma tensão de operação de 3.3V DC, pelo que essa é a tensão máxima que os seus pinos aceitam.

### 2. ESP8266 D1 Mini

O ESP8266 D1 Mini, à semelhança do ESP32-PoE-ISO, é uma placa de desenvolvimento, no entanto é baseada no microprocessador ESP8266. É uma placa de pequenas dimensões, conta com WiFi e uma porta micro USB que pode ser utilizada

V1.0-2021 | 3

para programá-la e/ou fornecer energia, sendo que esta placa requer uma alimentação de 5V DC e a sua tensão de operação é de 3.3V DC.

### 3. Raspberry Pi 4 Model B

A Raspberry Pi 4 Model B é um minicomputador, possui um processador quad-core, existem versões de 2, 4 e 8gb de memória RAM, sendo esta a versão de 4gb, possui WiFi, BLE e LAN, conta com duas portas USB 2.0 e duas portas USB 3.0, duas portas micro HDMI e uma porta USB-C. A sua alimentação pode ser feita através dos seus pinos a 5V DC, da porta USB-C a 5V DC e ainda através da porta ethernet recorrendo a um adaptador, o PoE HAT. Neste projeto, a Raspberry irá albergar o sistema operativo do Home Assistant de modo a criar um servidor ao qual se possa aceder através da internet e controlar os dispositivos a partir de lá.

### 4. PoE HAT

O PoE HAT é um acessório para a Raspberry Pi, apenas é compatível com a Raspberry Pi 4 Model B e com a Raspberry Pi 3 Model B+. É um acessório que é encaixado sobre a Raspberry Pi e permite alimentá-la através de PoE, sendo que para

V1.0-2021 | 4

isso é necessário que a rede possua um aparelho que forneça esse tipo de alimentação. Note que não é aconselhável alimentar a Raspberry Pi simultaneamente por PoE e USB-C ou pelos seus pinos, assim como quando a alimentação da mesma seja feita através da porta USB-C, o PoE HAT não deve estar encaixado, correndo o risco de danificar a Raspberry Pi.

### 5. MCP2515

O MCP2515 para além de ser o nome do chip integrado neste módulo é um controlador CAN stand-alone que converte mensagens CAN em SPI, e vice versa, para facilitar a integração com os microcontroladores. Este módulo contém um cristal de 8MHz e o transceiver TJA1050, a tensão de alimentação do mesmo é de 5V DC e para realizar a comunicação CANbus tem disponíveis dois pontos de acesso, sendo um deles os pinos conectores macho representados como H e L no módulo, e o outro é o terminal de aperto. Contém também dois pinos conectores macho denominados de J1 que são um jumper para uma resistência de 120Ω, necessária em pelo menos um dos módulos quando se realiza a comunicação CANbus com vários módulos.

V1.0-2021 | 5

### 6. DHT11

O sensor DHT11 é um sensor de temperatura e humidade que permite realizar leituras de temperatura de 0ºC a 50ºC e leituras de humidade de 20% a 90%. Pode ser alimentado com tensões entre 3.3V e 5V DC e faz a comunicação com o microcontrolador através de apenas um pino.

### 7. PCF8574

O PCF8574 é um chip fabricado pela Texas Instruments e também o nome atribuído à placa que é um expansor de entradas e saídas digitais. Esta placa em concreto permite expandir até um máximo de 8 entradas/saídas, tem uma tensão de alimentação de 5V DC e comunica com o microcontrolador através do protocolo de comunicação I2C, pelo que necessita de um endereço que pode ser definido através dos três jumpers, a configuração dos endereços pode ser conhecida na Figura 1. Como pode verificar existem oito endereços diferentes o que significa que pode ligar oito expansores em simultâneo, ficando no total com 64 entradas/saídas disponíveis, sendo que cada um deverá possuir um endereço único.


V1.0-2021 | 6

Figura 1 - Tabela de Endereços

### 8. Módulo de 8 Relés

O módulo apresentado é uma placa que inclui 8 relés de estado sólido, a sua tensão de alimentação é de 5V DC e são ativos alimentado o respetivo canal com o sinal de ground. Os relés podem ser alimentados e ativos através dos pinos conectores machos (canto inferior esquerdo) ou através dos conectores de aperto (canto inferior direito). A saída destes relés em concreto, só funciona com cargas de corrente alternada (AC), sendo que, no máximo, cada relé suporta cargas de 240V e 2A. Estas saídas podem ser acedidas através dos conectores de aperto de cada relé (parte superior), onde um dos conectores é a entrada da fase e o outro a saída do relé, na Figura 2 pode-se observar um exemplo de ligação de uma carga num dos relés.


V1.0-2021 | 7

Figura 2 - Exemplo de Ligação

### 9. Módulo RJ45 2x4

O módulo de fichas RJ45 com a configuração de 2x4 permite integrar 8 fichas RJ45 de forma compacta e garante boas ligações entre dispositivos através de cabos de rede ethernet. É possível visualizar todas as cotas e dimensões deste módulo na Figura 3.


V1.0-2021 | 8

Figura 3 - Dimensões Módulo RJ45 2x4

### 10. Ficha RJ45

Esta ficha RJ45 é acoplada na placa remota e tem o objetivo de fornecer à mesma as tensões de 5V DC e 3V DC, tal como os respetivos ground e também o barramento de comunicação CANbus, que está encarregue de transmitir os dados dos sensores ou dispositivos remotos à placa principal. É possível visualizar todas as cotas e dimensões deste módulo na Figura 4.


V1.0-2021 | 9

Figura 4 - Dimensões da Ficha RJ45

### 11. Placa de Shunt

Uma das placas de circuito impresso tem a função de shunt e proteção nas placas de relés, de modo a evitar colocar um fio condutor com a fase em cada conector dos relés. Com esta placa, basta soldar o fio com a fase no orifício central e se desejar, pode soldar um fusível em cada saída com o objetivo de proteger o fusível do módulo de relés, já que é de difícil substituição. Caso não deseje colocar um fusível, poderá soldar os solder jumpers individualmente. Note que deverá fazer uma boa distribuição das cargas, já que cada saída da placa apenas poderá debitar 1,2A no máximo, no entanto, a placa de shunt não suporta mais do que 2,65A em cada metade da placa. Na Figura 5 pode-se observar o layout desta placa.

Figura 5 - Layout da Placa de Shunt


V1.0-2021 | 10

### 12. Placa Remota

A placa remota tem o objetivo de receber sinais de sensores ou dispositivos remotos, que estejam distantes da placa principal, e enviá-los, através do protocolo de comunicação CANbus, para a mesma, onde serão tratados e apresentados no Home Assistant. Esta placa remota irá albergar um módulo MCP2515, um ESP8266 D1 Mini, uma ficha RJ45 e pinos conectores fêmea. Na Figura 6 pode visualizar o esquema elétrico desta placa e na Figura 7 o layout, como pode verificar através das figuras, os pinos 7 e 8 da ficha RJ45 não estão conectados a nenhum dispositivo, mas estão acessíveis, assim como todos os pinos do ESP8266 D1 Mini. Através do esquema, é possível verificar que existe uma resistência de 4K7Ω, cuja sua função é limitar a tensão que chega ao pino D6 do ESP8266 D1 Mini, no entanto, através de testes realizados, chegou-se à conclusão de que a resistência poderá não ser colocada, sendo, nesse caso, necessário soldar o solder jumper que se encontra no mesmo local, de modo a permitir a comunicação entre o modulo MCP2515 e o ESP8266 D1 Mini.

Figura 6 - Esquema Elétrico da Placa Remota


V1.0-2021 | 11

Figura 7 - Layout da Placa Remota

### 13. Placa Principal

Esta é a placa principal do projeto, é nela que serão montados a maioria dos componentes descritos anteriormente de forma a ficar tudo compacto e bem conectado. Na Figura 8 pode visualizar o seu esquema elétrico e na Figura 9 o layout, verificando


V1.0-2021 | 12

que os pinos 7 e 8 da quarta ficha inferior e superior não estão conectados a nada, pelo que estão acessíveis junto do módulo de fichas RJ45 para o caso de serem necessários em aplicações futuras. Todos os pinos do ESP32-PoE-ISO também estão acessíveis junto do mesmo, de forma que seja possível pôr em prática novas aplicações. À semelhança da placa remota, nesta placa também existe uma resistência de 4K7Ω, cuja sua função é limitar a tensão que chega ao pino 15 do ESP32-PoE-ISO, no entanto, através de testes realizados, chegou-se à conclusão de que a resistência poderá não ser colocada, sendo, nesse caso, necessário soldar o solder jumper que se encontra no mesmo local, de modo a permitir a comunicação entre o modulo MCP2515 e o ESP32-PoE-ISO. A configuração das portas do módulo RJ45 pode ser visualizada na Figura 10 e Tabela 1, verificando-se que o pino 1 e 2 de cada porta estão destinados ao sinal de ground e o pino 3 e 4 estão destinados à tensão de 3.3V e 5V, respetivamente.

Figura 8 - Esquema elétrico da Placa Principal


V1.0-2021 | 13

Figura 9 - Layout da Placa Principal


V1.0-2021 | 14

Figura 10 – Configuração das Portas

Tabela 1 - Configuração das Portas

UP1 | UP2 | UP3 | UP4
LP1 | LP2 | LP3 | LP4

V1.0-2021 | 15

### 3. Lista de Material

Nesta secção ficará a conhecer quais os materiais necessários para a montagem de todo o hardware do projeto.

- 1x Placa principal
- 2x Placa remota
- 3x Placa de shunt
- 1x Módulo RJ45 2x4
- 6x PCF8574
- 1x DHT11/DHT22
- 3x Módulo de 8 relés
- 1x ESP32-PoE-ISO
- 3x Módulo MCP2515
- 2x ESP8266 D1 Mini
- 1x Raspberry Pi 4 Model B/Raspberry Pi 3 Model B+
- 1x PoE HAT
- 2x Ficha RJ45
- 3x 2 Pinos conectores fêmea
- 7x 4 Pinos conectores fêmea
- 3x 7 Pinos conectores fêmea
- 4x 8 Pinos conectores fêmea
- 10x 9 Pinos conectores fêmea
- 7x 10 Pinos conectores fêmea
- 1x Cartão micro SD
- 1x Switch PoE
- 12x Parafusos plásticos M3x18
- 12x Porcas M3
- 12x Espaçadores M3 11mm

V1.0-2021 | 16

### 4. Preparação da Montagem

Agora que já possui todos os materiais reunidos pode começar a preparar a montagem, visto que é necessário fazer alterações nos seis PCF8574, para isso siga os passos abaixo.

### 1. Com auxílio de um alicate, coloque, com cuidado, os pinos macho do

componente PCF8574 na vertical (Figura 11) de modo a ficar com o aspeto da Figura 12.

Figura 11 - Pinos Macho na Horizontal

Figura 12 - Pinos Macho na Vertical

### 2. Cuidadosamente, com o auxílio de um alicate, empurre a o plástico dos

pinos para baixo, até ficar encostado na placa, ficando com o aspeto da Figura 13.

Figura 13 - Plástico Encostado na Placa

V1.0-2021 | 17

### 3. Agora necessita de cortar os pinos de modo a ficarem nivelados com os

outros oito pinos do componente (Figura 14).

Figura 14 - Aspeto Final do Componente

V1.0-2021 | 18

### 5. Soldadura

5.1.Placa Principal

Tendo os componentes todos reunidos e preparados, pode começar a soldar os mesmos na placa de circuito impresso principal, para isso recomenda-se a visualização de um tutorial em vídeo onde ficará a conhecer todos os procedimentos. Note que, apesar do vídeo ser relativo à versão V1.0 da placa desenvolvida, poderá guiar-se pelo mesmo, uma vez que a montagem dos componentes é igual em ambas as versões, alterando apenas o facto, de que, na versão V2.0 existe um solder jumper no local destinado à resistência de 4K7Ω, pelo que se não desejar colocar a resistência terá de soldar o solder jumper. As restantes diferenças entre as versões das placas é apenas nas legendagem dos componentes. O vídeo está disponível através do seguinte link: https://www.youtube.com/watch?v=TkQqE3qw0ag.

Após todos os componentes estarem soldados, é de extrema importância que verifique, com um multímetro, se existem curto-circuitos ou pinos interligados que não seria suposto, de modo a garantir que quando alimentar os componentes nenhum se danifica. Pode fazer essa verificação com o teste de continuidade do multímetro.

5.2.Placa Remota

Para o processo de soldadura das placas remotas poderá seguir os passos abaixo para cada uma delas. Esta versão da placa, face à versão V1.0, apenas difere na legendagem da ficha RJ45 e na existência de um solder jumper no mesmo local da resistência de 4K7Ω.

V1.0-2021 | 19

### 1. Na face da placa mostrada na Figura 15, comece por encaixar as barras de 8

pinos conectores fêmea e proceda à soldadura das mesmas.

Figura 15 - Barras de 8 Pinos Conectores Fêmea

### 2. Ainda na mesma face da placa, coloque a resistência de 4K7Ω no local

destinado e proceda à sua soldadura, caso não deseje colocar a resistência, terá de soldar o solder jumper que se encontra no mesmo local (Figura 16).

Figura 16 - Resistência de 4K7Ω


V1.0-2021 | 20

### 3. Na mesma face dos passos anteriores, encaixe a ficha RJ45 no local

destinado e proceda à sua soldadura (Figura 17).

Figura 17 - Ficha RJ45

### 4. Na face oposta, encaixe as duas barras de 9 pinos conectores fêmea e

proceda à soldadura das mesmas (Figura 18).

Figura 18 - Barras de 9 pinos conectores fêmea


V1.0-2021 | 21

### 5. Na mesma face da placa de circuito impresso, encaixe a barra de 2 pinos

conectores fêmea, bem como a barra de 7 pinos conectores fêmea e proceda à soldadura de ambas (Figura 19).

Figura 19 - Barras de 2 e 7 pinos conectores fêmea

Após todos os componentes estarem soldados, é de extrema importância que verifique, com um multímetro, se existem curto-circuitos ou pinos interligados que não seria suposto, de modo a garantir que quando alimentar os componentes nenhum se danifica. Pode fazer essa verificação com o teste de continuidade do multímetro.


V1.0-2021 | 22

5.3.Placa de Shunt

Para proceder ao processo de soldadura da placa de shunt deverá seguir os passos descritos abaixo para cada uma das placas.

### 1. Se desejar, comece por colocar um fusível em cada saída da placa e proceda

á sua soldadura, caso contrário, apenas solde o solder jumper que se encontra no mesmo local (Figura 20).

Figura 20 - Fusível/Solder Jumper

### 2. De seguida, no orifício central, solde um fio que irá alimentar a placa com a

fase proveniente do seu quadro elétrico (Figura 21). Note que ao soldar o fio não o deve ter ligado a nada e que o mesmo deve de ter uma secção mínima de 2.5mm

, ou 1.5mm
caso todas as cargas sejam de iluminação.

Figura 21 - Alimentação da Placa

### 3. Após realizados os passos anteriores, as placas deverão ficar com um aspeto

semelhante à Figura 22, sendo que neste caso não se utilizaram fusíveis.

Figura 22 - Aspeto Final da Placa de Shunt


V1.0-2021 | 23

### 6. Montagem

Neste ponto já deverá ter todo o trabalho de soldadura realizado, posto isto, basta seguir os passos abaixo para finalizar a montagem das placas.

6.1.Fixação dos Relés

### 1. Com o módulo de relés no sítio, basta colocar o espaçador entre o mesmo e

a placa principal (Figura 23).

Figura 23 - Espaçador

### 2. Insira o parafuso através da furação placa principal, de modo que este entre

no espaçador e na furação do módulo de relés (Figura 24).

Figura 24 - Parafuso


V1.0-2021 | 24

### 3. Agora só necessita de apertar a porca no parafuso de modo a ficar seguro

(Figura 25), repita o processo para as restantes furações dos relés, ficando com o aspeto da Figura 26.

Figura 25 – Porca

Figura 26 - Aspeto Final


V1.0-2021 | 25

6.2.Montagem da Placa Remota

Após ter os devidos componentes soldados na placa, basta encaixar os restantes nos devidos conectores de modo a ficar com o aspeto da Figura 27 e da Figura 28. Note que o ESP8266 D1 Mini tem uma posição própria, sendo que pode danificá-lo caso não respeite a sua posição.

Figura 27 - Aspeto da Placa Finalizada Face 1

Figura 28 - Aspeto da Placa Finalizada Face 2


V1.0-2021 | 26

6.3.Montagem das Placas de Shunt

### 1. Para a montagem das placas de shunt, é necessário que, com o auxílio de uma

pequena chave de fendas, force a abertura de um ligador de cada saída da placa de relés, de forma a ter o espaço suficiente para encaixar as placas. Na Figura 29 estão demonstrados os ligadores que têm a necessidade de serem forçados.

Figura 29 – Ligadores a Forçar

### 2. Nos ligadores que acabou de forçar a sua abertura, encaixe a placa de shunt

exercendo força de forma uniforme por toda a placa e aperte os devidos parafusos dos ligadores para que fique fixa (Figura 30). Note que não deverá apertar em demasia os parafusos para evitar danificar a placa.

Figura 30 - Placa de Shunt Encaixada

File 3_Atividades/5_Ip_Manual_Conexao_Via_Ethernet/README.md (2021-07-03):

# iModDom
## Exercícios de Ip Manual e Conexão via *Ethernet*
- Estes exercícios desafiam o utilizador a desenvolver uma programação que lhe permita obter uma conexão à rede via *ethernet* e a definir um Ip manualmente.

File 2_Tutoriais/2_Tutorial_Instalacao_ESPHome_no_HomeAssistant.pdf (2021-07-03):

# iModDom


V1.0-2021

# Tutorial – Instalação ESPHome no Home Assistant

Elaborado por:
Marco Pereira - 2190516

Orientado por:
Luís Bento
Carlos Neves

V1.0-2021

Tutorial – Instalação ESPHome no Home Assistant

### Índice

V1.0-2021 | 1

### 1. Introdução

O ESPHome é um sistema que permite controlar o ESP8266/ESP32 através de arquivos de configuração simples, no entanto muito poderosos, e controlá-los remotamente através de sistemas de automação residencial. O Home Assistant é uma plataforma de automação open source que permite rastrear e controlar vários dispositivos de forma automatizada.

1.1.Objetivos

Com este tutorial, o objetivo é ensinar a instalar o ESPHome no Home Assistant.

### 2. Instalação do ESPHome


V1.0-2021 | 2

### 1. Dentro do Home Assistant, aceda a “Supervisor” e de seguida a “Add-on Store”

(Figura 1).

Figura 1 - Loja de Add-ons

### 2. Aceda aos três pontos no canto superior direito e clique em “Respositories”

(Figura 2)

Figura 2 – Repositórios


V1.0-2021 | 3

### 3. Na janela que irá surgir, coloque o seguinte link:

https://github.com/esphome/hassio, e clique em “ADD”, depois de adicionado o repositório pode clicar em “CLOSE” (Figura 3).

Figura 3 - Inserir o Repositório

### 4. Faça scroll até à parte de baixo da página e clique no Add-on “ESPHome (dev)”

(Figura 4).

Figura 4 - Selecionar o Add-on


V1.0-2021 | 4

### 5. De seguida será encaminhado para o Add-on e deverá clicar em “INSTALL”

(Figura 5).

Figura 5 – Instalar o ESPHome

### 6. Após a instalação estar concluída, clique em “START” para iniciar o ESPHome

(Figura 6). Note que pode ativar a opção “Show in sidebar” se desejar que o ícone do ESPHome apareça na barra lateral para facilitar o seu acesso.

Figura 6 - Iniciar o ESPHome


V1.0-2021 | 5

### 7. Pode agora, abrir o ESPHome, clicando no ícone na barra lateral caso tenha

ativado a opção ou clicando em “OPEN WEB UI” (Figura 7).

Figura 7 - Abrir o ESPHome

### 3. Primeiro Node


V1.0-2021 | 6

Nesta secção irá ficar a saber como criar um node e a fazer o seu upload para o ESP.

### 1. Em primeiro lugar deve conectar o seu ESP a uma porta USB do seu

Raspberry Pi.

### 2. De seguida clique no ícone verde que se encontra no canto inferior direito

(Figura 8).

Figura 8 - Criação de um Node

3. Irá surgir-lhe uma janela com o aspeto da Figura 9, clique em “BEGIN”.

Figura 9 - Janela do Wizard


V1.0-2021 | 7

### 4. De seguida deve atribuir um nome ao seu node e clicar em “NEXT” (Figura

10).

Figura 10 - Nome do node

### 5. No passo seguinte é-lhe pedido para selecionar o seu ESP, após isso clique

em “NEXT” (Figura 11).

Figura 11 - Seleção do ESP


V1.0-2021 | 8

### 6. Agora deve introduzir o nome da sua rede WiFi, a respetiva password e uma

password para realizar as atualizações OTA (over the air), via WiFi, de seguida clique em “NEXT” (Figura 12).

Figura 12 - Dados do WiFi

### 7. Por último irá surgir a informação que criou com sucesso o node e pode

clicar em “SUBMIT” (Figura 13).

Figura 13 - Node Criado com Sucesso


V1.0-2021 | 9
8. Note que agora o node que acabou de criar aparece no ESPHome.

### 9. Com o ESP conectado ao Raspberry Pi, aceda ao menu no canto superior

direito e selecione o ESP (Figura 14).

Figura 14 - Seleção do ESP

### 10. Após selecionar o ESP, clique em “UPLOAD” de modo a carregar o node

para o ESP (Figura 15). Irá surgir uma janela idêntica à da Figura 16.

Figura 15 - Upload do Node

Figura 16 - Janela de Upload


V1.0-2021 | 10

### 11. Caso surja um erro como o da Figura 17, deverá tentar fazer o upload

novamente, mas tentando umas das seguintes hipóteses:
1- Manter o botão de boot pressionado até que o upload esteja concluído. 2- Manter o botão de boot pressionado, clicar e soltar o botão de reset e quando o upload estiver concluído soltar o botão de boot.
3- Conectar o pino GND ao pino GPIO0 enquanto o upload é executado, seguindo o esquema apresentado na Figura 18.

Figura 17 - Erro de Upload

Figura 18 – Esquema de Ligação


V1.0-2021 | 11

### 12. Após o upload ter sido concluído com sucesso irá visualizar uma mensagem

semelhante à da Figura 19.

Figura 19 - Upload Concluído com Sucesso

### 4. Configuração do Painel Inicial


V1.0-2021 | 12

No painel inicial é onde vai poder controlar os seus dispositivos, no entanto, como verificar na Figura 20 ainda não existe nenhum dispositivo disponível, uma vez que o node criado não continha nenhum dispositivo. Nos passos seguintes vamos adicionar um LED.

Figura 20 - Painel Inicial

### 1. Primeiramente faça as seguintes ligações no seu ESP, para isso utilize um LED

vulgar e uma resistência com valores compreendidos entre 230Ω e 500Ω (Figura 21).

Figura 21 - Esquema de Ligação do LED


V1.0-2021 | 13
2. Comece por abrir o ESPHome e clicar em “EDIT” no seu node (Figura 22).

Figura 22 - Editar o Node

3. Cole o seguinte código de modo a ficar com o aspeto da Figura 23.

Figura 23 - Aspeto do Código

light:
- platform: binary
name: "LED"
output: output_component1

output:
- platform: gpio
pin: 5
id: output_component1


V1.0-2021 | 14

### 4. Após adicionar o código clique em “SAVE” e de seguida em “UPLOAD”

(Figura 23). O ESP apenas necessita de estar conectado ao Raspberry Pi no primeiro upload de cada node, após isso pode estar desconectado do mesmo, desde que esteja alimentado, pois o ESPHome irá fazer o upload através da rede WiFi, sendo que para isso é necessário que o node contenha o código necessário para essa funcionalidade.
5. Quando o upload estiver concluído pode clicar em “STOP” (Figura 24).

Figura 24 - Upload Concluído


V1.0-2021 | 15

### 6. Aceda à aba lateral e de seguida a “Configuration” e depois clique em “ADD

INTEGRATION” | (Figura | 25).

Figura 25 - Adicionar uma Integração

### 7. Na janela que surgiu, pesquise por “ESPHome” e clique na aba “ESPHome”

(Figura 26).

Figura 26 - Nova Integração


V1.0-2021 | 16

### 8. Irá ser-lhe pedido para que coloque o IP do seu ESP, coloque-o e de seguida

clique em “SUBMIT” (Figura 27). Note que é possível saber o IP do seu ESP quando faz o upload para o mesmo, tal como se pode verificar na primeira linha da Figura 24.

Figura 27 - IP do ESP

### 9. De seguida é-lhe pedido para colocar a password que definiu anteriormente

como password do API, coloque-a e clique em “SUBMIT” (Figura 28) e de seguida clique em “FINISH” (Figura 29).

Figura 28 - Password do API

Figura 29 - "FINISH"


V1.0-2021 | 17
10. Agora pode aceder ao painel inicial clicando em “Overview” (Figura 30).

Figura 30 - Aceder ao Painel Inicial

### 11. Para adicionar o controlo do LED ao painel inicial, aceda ao menu no canto

superior direito e clique em “Edit Dashboard” (Figura 31).

Figura 31 - Configurar Painel


V1.0-2021 | 18

### 12. Como pode verificar, neste momento pode configurar todo o painel, editando

cartões existentes e adicionando novos, para isso, clique em “ADD CARD” (Figura 32).

Figura 32 - Adicionar Cartão

### 13. Na janela que se abrirá clique no cartão “Button” que corresponde ao LED que

acabou de adicionar (Figura 33).

Figura 33 - Cartão do LED


V1.0-2021 | 19

### 14. Neste momento é capaz de configurar o seu cartão, pode alterar o nome do

mesmo, alterar o ícone, entre outras. Após concluir a configuração clique em “SAVE” (Figura 34).

Figura 34 - Configuração do Cartão

15. Pode alterar as posições dos cartões clicando nas setas que os mesmos contêm. Quando o painel inicial estiver com o aspeto que deseja pode clicar no ícone no junto do nome do seu painel (Figura 35).

Figura 35 - Configuração Concluída


V1.0-2021 | 20

### 16. Como pode observar, neste momento já tem o cartão do LED disponível no

painel inicial, pode alterar o estado do mesmo clicando sobre o cartão (Figura 36).

Figura 36 - Aspeto Final do Painel Inicial

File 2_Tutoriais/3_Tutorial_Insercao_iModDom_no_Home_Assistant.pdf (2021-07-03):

# iModDom

V1.0-2021

# Tutorial – Inserção iModDom no Home Assistant

Elaborado por:
Marco Pereira - 2190516

Orientado por:
Luís Bento
Carlos Neves


V1.0-2021

Tutorial – Inserção iModDom no Home Assistant

### Índice

V1.0-2021 | 1

### 1. Introdução

Sendo o Home Assistant uma ferramenta poderosa ao nível da automação residencial e sendo bastante configurável, uma das suas muitas vantagens é permitir aceder a ficheiros locais ou até páginas web através de um botão na aba lateral.

1.1.Objetivos

Neste tutorial, vai aprender a criar um iframe Panel e a aceder aos ficheiros do sistema operativo do Home Assistant.

### 2. Instalação do Add-on Filebrowser


V1.0-2021 | 2

De forma a poder aceder aos ficheiros do sistema operativo do Home Assistant, terá de instalar o Add-on Filebrowser, para isso, siga os próximos passos.

### 1. Na sua página do Home Assistant, no separador “Supervisor” aceda a “Add-on

Store” (Figura 1).

Figura 1 - Add-on Store

### 2. Clique no ícone apresentado no canto superior direito da página e selecione

“Repositories” (Figura 2).

Figura 2 – Repositories


V1.0-2021 | 3

### 3. Na janela que surgiu coloque no campo “Add” o seguinte link:

https://github.com/alexbelgium/hassio-addons. De seguida clique em “ADD”, quando terminar de adicionar o repositório pode clicar em “CLOSE” (Figura 3).

Figura 3 - Adição do Add-on

### 4. Ainda no separador “Add-on Store”, faça scroll até ao final da página e clique

no add-on “Filebrowser” (Figura 4).

Figura 4 - Add-on Filebrowser


V1.0-2021 | 4

### 5. Clique em “INSTALL” para proceder à instalação do add-on e aguarde que a

mesma esteja concluída (Figura 5).

Figura 5 - Instalar o Add-on

### 3. Inserção iModDom no Home Assistant


V1.0-2021 | 5
1. Clique em “START” para iniciar o add-on (Figura 6), após o mesmo ter iniciado, clique em “OPEN WEB UI” de forma a abrir a interface do add-on (Figura 7).

Figura 6 - Iniciar o Add-on

Figura 7 - Abrir a Interface do Add-on


V1.0-2021 | 6

### 2. Será direcionado para uma página web, onde lhe é pedido um nome de utilizador

e uma password para aceder aos ficheiros do sistema, o utilizador e a password são ambos “admin” (Figura 8). Note que o utilizador e password podem ser alterados posteriormente.

Figura 8 - Acesso aos Ficheiros

### 3. Como pode verificar, agora tem acesso a todos os ficheiros do sistema. Aceda

à pasta “config” (Figura 9).

Figura 9 - Acesso à pasta "config"


V1.0-2021 | 7

### 4. Nesta pasta, clicando em “New folder”, crie uma nova pasta com o nome

“www” (Figura 10 e Figura 11).

Figura 10 - "New folder"

Figura 11 - Nome da Nova Pasta

### 5. Faça o upload da pasta iModDom, que se encontra no repositório do GitHub em

1_Documentacao->3_Software->iModDom, para esta nova pasta, clicando no ícone de “upload” no canto superior direito (Figura 12), de seguida clique em “Folder” (Figura 13) e selecione a pasta iModDom.

Figura 12 - Ícone de "upload"


V1.0-2021 | 8

Figura 13 - Upload Folder

### 6. Após ter realizado o upload, aceda novamente à pasta “config” e abra o ficheiro

"configuration.yaml" (Figura 14).

Figura 14 - Pasta "configuration.yaml"

### 7. Adicione o código da Caixa de Texto 1 ao ficheiro de forma a ficar com o aspeto

da Figura 15 e salve o ficheiro clicando no ícone no canto superior direito. Note que pode alterar o título do iframe Panel na terceira linha de código alterando “iModDom” por o título que deseja.

Caixa de Texto 1 - Código a Adicionar

panel_iframe:
router:
title: "iModDom"
url: "http://homeassistant.local:8123/local/iModDom/tests/iModDom.html"


V1.0-2021 | 9

Figura 15 - Aspeto do Código Final

### 8. Agora deverá desconectar o seu Raspberry Pi da alimentação e voltar a conectar

de forma que as alterações sejam carregadas.

### 9. Quando o Raspberry Pi iniciar, aceda ao Home Assistant e repare que o iframe

Panel já se encontra na aba lateral com o nome que lhe atribuiu (Figura 16), se clicar nele verifique que a página web surge dentro do Home Assistant (Figura
17) e deste modo poderá criar os seus programas diretamente a partir do Home Assistant.

Figura 16 - Iframe Panel


V1.0-2021 | 10

Figura 17 – Página Web Integrada

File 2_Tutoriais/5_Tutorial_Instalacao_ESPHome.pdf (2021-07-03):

# iModDom

V1.0-2021

# Tutorial - Instalação ESPHome

Elaborado por:
Marco Pereira - 2190516

Orientado por:
Luís Bento
Carlos Neves

V1.0-2021

Tutorial - Instalação ESPHome

### Índice

V1.0-2021 | 1

### 1. Introdução

O ESPHome é um sistema que permite controlar o ESP8266/ESP32 através de arquivos de configuração simples, no entanto muito poderosos, e controlá-los remotamente através de sistemas de automação residencial.

1.1.Objetivos

Pretende-se com este tutorial demonstrar como instalar o ESPHome bem como criar e configurar o primeiro projeto.


V1.0-2021 | 2

### 2. Instalação ESPHome

2.1.Instalação Python

Caso não tenha instalado o Python irá necessitar de o instalar, para isso basta aceder ao seguinte link: https://www.python.org/.

### 1. Após ter acedido ao link fornecido anteriormente, no menu “Downloads”, clique

em “Python 3.9.2” (Figura 1).

Nota: À data que estiver a seguir o tutorial a versão do Python poderá ser mais recente.

Figura 1 – Download Python

### 2. Após o download estar concluído com sucesso, aceda à pasta “Transferências”

e execute o ficheiro descarregado (Figura 2).

Figura 2 – Executar o Ficheiro


V1.0-2021 | 3

### 3. Na janela que irá surgir selecione a opção “Add Python 3.8 to PATH” e de

seguida clique em “Install Now” (Figura 3).

Figura 3 – Instalação do Python

### 4. Quando a instalação terminar, surgir-lhe-á a seguinte janela onde vai clicar em

“Disable path length limit” e de seguida em “Close” (Figura 4).

Figura 4 – Instalação Terminada

1

2

1

2


V1.0-2021 | 4

### 5. Pode confirmar que o Python foi instalado corretamente abrindo a linha de

comandos do seu computador e executar o seguinte comando “python --version”. Deverá surgir uma mensagem com a indicação da versão do Python instalada (Figura 5). Se ao executar o comando indicado surgir um erro semelhante ao da Figura 6 , aceda a https://packaging.python.org/tutorials/installing-packages/ de forma a solucionar o mesmo e conseguir prosseguir com o tutorial.

Figura 5 – Versão do Python Instalada

Figura 6 – Possível Erro ao Executar o Comando


V1.0-2021 | 5

2.2.Instalação do ESPHome

Agora que já instalou o Python com sucesso, passemos à instalação do ESPHome.

### 1. Comece por executar o comando “pip install esphome” (Figura 7), aguarde uns

segundos até que a instalação seja terminada com sucesso, ficando com o aspeto da Figura 8.

Figura 7 – Comando para Instalar o ESPHome

Figura 8 – Instalação Terminada com Sucesso


V1.0-2021 | 6

### 3. Primeiro Projeto

3.1.Criação de um Projeto

### 1. Agora que já instalou o ESPHome, crie uma pasta onde pretende guardar os seus

projetos, de seguida, na linha de comandos, selecione a diretoria da pasta criada através do comando “cd” seguido do caminho da pasta que criou (Figura 9).

Figura 9 – Pasta Criada

### 2. Execute o comando “esphome myfirst.yaml wizard” de modo a executar o

assistente de configuração do ESPHome. O primeiro passo é atribuir um nome para o node, pode atribuir o nome que desejar (Figura 14).

Figura 10 - Nome do Node

### 3. Depois de escolher o nome do seu node, é-lhe pedido para escolher entre o

ESP32 e o ESP8266 dependendo daquele que esteja a utilizar, escolha um (Figura 11).

Figura 11 - Seleção do Microcontrolador


V1.0-2021 | 7

### 4. De seguida é pedido para selecionar a placa que está a utilizar, de notar que é

apresentada uma lista das mesmas (Figura 12).

Figura 12 - Seleção da Placa

### 5. O próximo passo será introduzir as credenciais da sua rede WiFi, primeiramente

é-lhe pedido para introduzir o ssid e de seguida a password da rede (Figura 13).

Figura 13 - Configuração da Rede WiFi


V1.0-2021 | 8

### 6. O último passo será para introduzir uma password para realizar uploads dos

seus nodes via WiFi, caso não pretenda definir uma password basta clicar na tecla “ENTER” (Figura 14).

Figura 14 – Password OTA

3.2.Editar o Projeto

### 1. Agora que criou o seu projeto, abra o ficheiro “myfirst.yaml” com um editor à

sua escolha (Figura 15).

Figura 15 - Abrir o Ficheiro “myfirst.yaml”


V1.0-2021 | 9

### 2. Pode verificar que todas as configurações estão contidas neste ficheiro e podem

ser alteradas (Figura 16).

Figura 16 - Conteúdo do Ficheiro

3.3.Upload do Projeto

### 1. Neste momento necessita de conectar a sua placa à porta USB do seu

computador.

### 2. Voltando à linha de comandos, pode agora, executar o comando “esphome

myfirst.yaml run” de modo a compilar o ficheiro ”myfirst.yaml” e a criar e fazer upload do firmware para a sua placa (Figura 17).

Nota: Se ao fazer este passo, ocorrer um erro a informar que a placa não está conectada, muito provavelmente necessitará de instalar os drivers da mesma, pode encontrar alguns dos drivers aqui: https://docs.espressif.com/projects/esp-idf/en/latest/esp32/get-started/establish-serial-connection.html. Caso esteja a utilizar a placa ESP32-PoE-ISO, pode encontrar os drivers para a mesma no seguinte link: https://www.olimex.com/Products/IoT/ESP32/ESP32-POE-ISO/open-source-hardware ou seguir o tutorial “6_Tutorial_Instalacao_de_Drivers_ESP32_PoE_ISO”.


V1.0-2021 | 10

Figura 17 - Comando para Compilar

### 3. Após executar o comando irá aparecer a seguinte informação, onde terá de

escolher se pretende realizar o upload através da porta USB ou Over The Air (OTA), ou seja, via WiFi, como é a primeira vez que irá fazer o upload tem de ser através da porta USB, por isso escolha a opção 1 (Figura 18).

Figura 18 - Opção de Upload

### 4. Quando o upload estiver concluído com sucesso irá surgir uma mensagem do

género da apresentada na Figura 19. Caso surja o erro apresentado na Figura 20 deverá fazer o upload novamente, mas tentando uma das seguintes hipóteses:

1. Manter o botão de boot pressionado até que o upload esteja concluído.

### 2. Manter o botão de boot pressionado, clicar e soltar o botão de reset e

quando o upload estiver concluído soltar o botão de boot.
3. Conectar o pino GND ao pino GPIO0 enquanto o upload é executado, seguindo o esquema apresentado na Figura 21.


V1.0-2021 | 11

Figura 19 - Upload Concluído com Sucesso

Figura 20 - Erro no Upload

Figura 21 - Esquema de Ligação

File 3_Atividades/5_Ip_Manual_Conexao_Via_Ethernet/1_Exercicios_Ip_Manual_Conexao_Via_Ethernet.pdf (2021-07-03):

# iModDom

V1.0-2021

# Ip Manual/Conexão Via Ethernet - Exercícios

Elaborado por:
Marco Pereira - 2190516

Orientado por:
Luís Bento
Carlos Neves

V1.0-2021

Ip Manual/Conexão Via Ethernet - Exercícios

### Índice

V1.0-2021 | 1

### 1. Introdução

Este documento integra um conjunto de exercícios de programação através de blocos para colocar em prática no projeto iModDom. Nestes exercícios a utilização das placas de circuito impresso do projeto é facultativa. Pode encontrar as soluções dos exercícios na pasta onde estes se encontram, e poderá fazer upload do ficheiro na página onde utiliza os blocos, de forma a visualizar as soluções.

1.1.Objetivos

O objetivo com estes exercícios é que o utilizador comece a ganhar capacidade de criar os seus próprios programas através dos blocos do projeto.

V1.0-2021 | 2

### 2. Exercícios

1. Utilizando | o | programa | criado | no | exercício | 1.2 | do | documento
“Exercícios_Leitura_de_Sensor”, altere o ip do node para um ip à sua escolha e aceda ao web server através do mesmo.

### 1.1. Faça as modificações necessárias para que a conexão à rede de internet seja

feita através de ethernet, mantendo o ip definido na alínea anterior.

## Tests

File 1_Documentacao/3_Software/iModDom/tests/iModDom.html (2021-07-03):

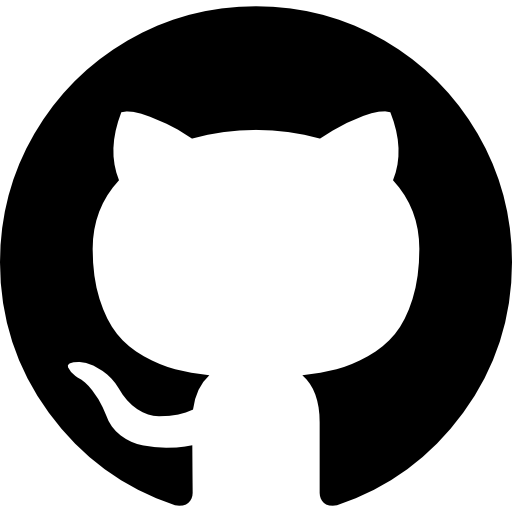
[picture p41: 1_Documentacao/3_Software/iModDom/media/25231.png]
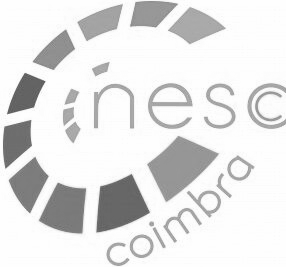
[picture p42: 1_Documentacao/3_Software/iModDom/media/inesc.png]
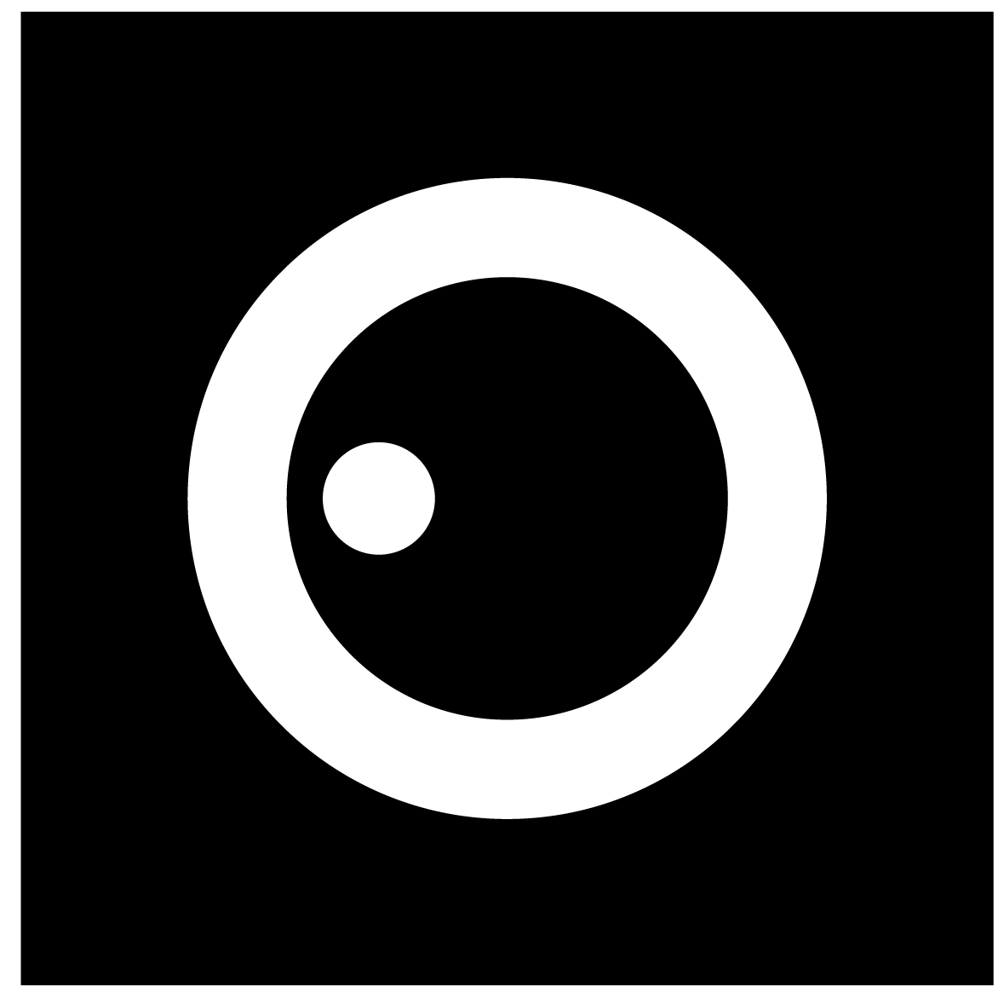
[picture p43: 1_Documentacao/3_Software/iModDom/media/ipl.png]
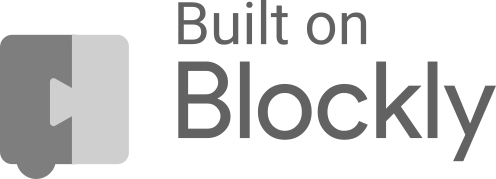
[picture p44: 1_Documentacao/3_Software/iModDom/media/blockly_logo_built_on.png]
# iModDom  (https://github.com/ipleiria-robotics/iModDom)  (https://www.uc.pt/en/org/inescc)  (https://www.ipleiria.pt/estg/)  (https://github.com/google/blockly)

download file_upload save description content_copy delete

ESP32 esp32-poe-iso 5 SSID wifi_password OTA password API password ESP32 esp32-poe-iso 5 SSID wifi_password OTA password API password ESP32 esp32-poe-iso 3 4 5 13 14 SSID wifi_password OTA password API password ESP32 esp32-poe-iso 5 SSID wifi_password OTA password API password name ESP32 esp32-poe-iso SSID wifi_password 0 0 0 0 0 0 0 0 0 0 0 0 LAN8720 23 18 GPIO17_OUT 12 API password True insert your password NONE 13 16 True i2c_bus 80 TRUE pcf8574_0x20 FALSE pcf8574_0x21 FALSE pcf8574_0x22 FALSE pcf8574_0x23 FALSE pcf8574_0x24 FALSE pcf8574_0x25 FALSE pcf8574_0x26 FALSE pcf8574_0x27 Input name binary sensor id esp pin INPUT True Input name binary sensor id pcf8574 id pin number True sensor name pir_id esp pin sensor name pir_id pcf8574 id pin number 0 0 0 0 0 0 0 0 0 0 0 0 0 0 switch.toggle id CAN bus id CAN id data to transmit ESP pin livingroom temperature livingroom humidity 60 livingroom temperature livingroom humidity 60 outside temperature outside pressure 0x77 60 adc pin mq7_id 60 value name sensor id ยบC temperature 60 switch name esp pin true switch id TRUE interlock name switch id switch id TRUE always_off switch name pcf8574 id pin number true switch id TRUE interlock name switch id switch id TRUE always_off switch name switch name ESP pin true output id pcf8574 id pin number true output id input name output id light id TRUE always off input name fan id output id input name cover id open duration close duration input name cover id open duration binary sensor id close duration binary sensor id switch.turn_on switch id 14 2 15 spi_bus CAN bus id CAN id True 5 500KBPS 8MHZ NORMAL CAN id switch.toggle id

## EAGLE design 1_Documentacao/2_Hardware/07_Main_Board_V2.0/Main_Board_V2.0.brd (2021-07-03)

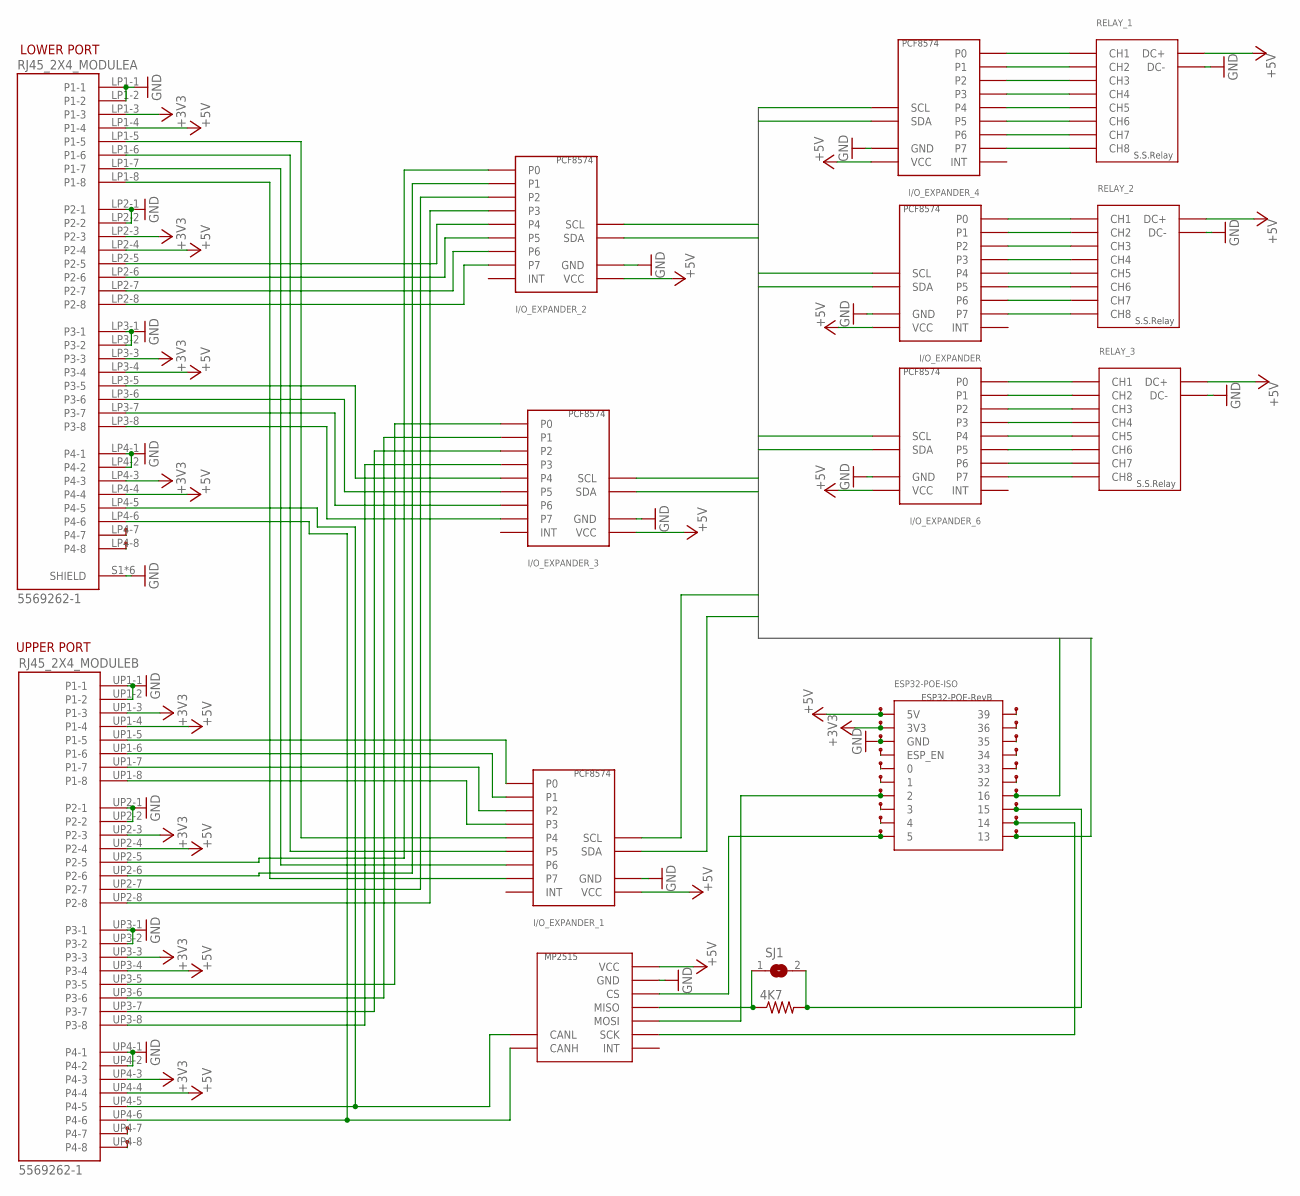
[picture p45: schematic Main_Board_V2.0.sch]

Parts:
4K7: R-US_0207/10; 0207/10
ESP32-POE-ISO: ESP-POE
I/O_EXPANDER: PCF8574-MODULE_ESPELHADO
I/O_EXPANDER_1, I/O_EXPANDER_2, I/O_EXPANDER_3, I/O_EXPANDER_4, I/O_EXPANDER_6: PCF8574-MODULE_ESPELHADO
RELAY_1, RELAY_2, RELAY_3: SSR_M_FULL_SEM_LIGACOES; SSR_M_SEM_LIGACOES
RJ45_2X4_MODULE: 5569262-1; TE_5569262-1
SJ1: SJ
U$1, U$2, U$4, U$5, U$6, U$7, U$8, U$9, U$10, U$11, U$12, U$13, U$14, U$15, U$16, U$17, U$18, U$19, U$20, U$21, U$22, U$23, U$24, U$25: TP
U$26: MCP2515_MODULE_SEM_LIGACOES

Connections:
+3V3: ESP32-POE-ISO.3V3, RJ45_2X4_MODULE.LP1-3 (P1-3), RJ45_2X4_MODULE.LP2-3 (P2-3), RJ45_2X4_MODULE.LP3-3 (P3-3), RJ45_2X4_MODULE.LP4-3 (P4-3), RJ45_2X4_MODULE.UP1-3 (P1-3), RJ45_2X4_MODULE.UP2-3 (P2-3), RJ45_2X4_MODULE.UP3-3 (P3-3), RJ45_2X4_MODULE.UP4-3 (P4-3), U$6.P$1
+5V: ESP32-POE-ISO.5V, I/O_EXPANDER.VCC, I/O_EXPANDER_1.VCC, I/O_EXPANDER_2.VCC, I/O_EXPANDER_3.VCC, I/O_EXPANDER_4.VCC, I/O_EXPANDER_6.VCC, RELAY_1.DC+, RELAY_2.DC+, RELAY_3.DC+, RJ45_2X4_MODULE.LP1-4 (P1-4), RJ45_2X4_MODULE.LP2-4 (P2-4), RJ45_2X4_MODULE.LP3-4 (P3-4), RJ45_2X4_MODULE.LP4-4 (P4-4), RJ45_2X4_MODULE.UP1-4 (P1-4), RJ45_2X4_MODULE.UP2-4 (P2-4), RJ45_2X4_MODULE.UP3-4 (P3-4), RJ45_2X4_MODULE.UP4-4 (P4-4), U$2.P$1, U$26.VCC
GND: ESP32-POE-ISO.GND, I/O_EXPANDER.GND, I/O_EXPANDER_1.GND, I/O_EXPANDER_2.GND, I/O_EXPANDER_3.GND, I/O_EXPANDER_4.GND, I/O_EXPANDER_6.GND, RELAY_1.DC-, RELAY_2.DC-, RELAY_3.DC-, RJ45_2X4_MODULE.LP1-1 (P1-1), RJ45_2X4_MODULE.LP1-2 (P1-2), RJ45_2X4_MODULE.LP2-1 (P2-1), RJ45_2X4_MODULE.LP2-2 (P2-2), RJ45_2X4_MODULE.LP3-1 (P3-1), RJ45_2X4_MODULE.LP3-2 (P3-2), RJ45_2X4_MODULE.LP4-1 (P4-1), RJ45_2X4_MODULE.LP4-2 (P4-2), RJ45_2X4_MODULE.S1 (SHIELD), RJ45_2X4_MODULE.S2 (SHIELD), RJ45_2X4_MODULE.S3 (SHIELD), RJ45_2X4_MODULE.S4 (SHIELD), RJ45_2X4_MODULE.S5 (SHIELD), RJ45_2X4_MODULE.S6 (SHIELD), RJ45_2X4_MODULE.UP1-1 (P1-1), RJ45_2X4_MODULE.UP1-2 (P1-2), RJ45_2X4_MODULE.UP2-1 (P2-1), RJ45_2X4_MODULE.UP2-2 (P2-2), RJ45_2X4_MODULE.UP3-1 (P3-1), RJ45_2X4_MODULE.UP3-2 (P3-2), RJ45_2X4_MODULE.UP4-1 (P4-1), RJ45_2X4_MODULE.UP4-2 (P4-2), U$7.P$1, U$26.GND
unnamed: I/O_EXPANDER_1.P0, RJ45_2X4_MODULE.UP1-5 (P1-5)
unnamed: I/O_EXPANDER_1.P1, RJ45_2X4_MODULE.UP1-6 (P1-6)
unnamed: I/O_EXPANDER_1.P2, RJ45_2X4_MODULE.UP1-7 (P1-7)
unnamed: ESP32-POE-ISO.ESP_EN, U$8.P$1
unnamed: ESP32-POE-ISO.0, U$9.P$1
unnamed: ESP32-POE-ISO.1, U$10.P$1
unnamed: ESP32-POE-ISO.2, U$11.P$1, U$26.MOSI
unnamed: ESP32-POE-ISO.3, U$12.P$1
unnamed: ESP32-POE-ISO.4, U$13.P$1
unnamed: ESP32-POE-ISO.5, U$14.P$1, U$26.CS
unnamed: ESP32-POE-ISO.39, U$15.P$1
unnamed: ESP32-POE-ISO.36, U$16.P$1
unnamed: ESP32-POE-ISO.35, U$17.P$1
unnamed: ESP32-POE-ISO.34, U$18.P$1
unnamed: ESP32-POE-ISO.33, U$19.P$1
unnamed: ESP32-POE-ISO.32, U$20.P$1
unnamed: I/O_EXPANDER_1.P3, RJ45_2X4_MODULE.UP1-8 (P1-8)
unnamed: 4K7.2, ESP32-POE-ISO.15, SJ1.2, U$22.P$1
unnamed: ESP32-POE-ISO.14, U$23.P$1, U$26.SCK
unnamed: I/O_EXPANDER_2.P0, RJ45_2X4_MODULE.UP2-5 (P2-5)
unnamed: I/O_EXPANDER_4.P0, RELAY_1.CH1
unnamed: I/O_EXPANDER_4.P1, RELAY_1.CH2
unnamed: I/O_EXPANDER_4.P2, RELAY_1.CH3
unnamed: I/O_EXPANDER_4.P3, RELAY_1.CH4
unnamed: I/O_EXPANDER_4.P4, RELAY_1.CH5
unnamed: I/O_EXPANDER_2.P1, RJ45_2X4_MODULE.UP2-6 (P2-6)
unnamed: I/O_EXPANDER_4.P5, RELAY_1.CH6
unnamed: I/O_EXPANDER_4.P6, RELAY_1.CH7
unnamed: I/O_EXPANDER_4.P7, RELAY_1.CH8
unnamed: I/O_EXPANDER_6.P0, RELAY_3.CH1
unnamed: I/O_EXPANDER_6.P1, RELAY_3.CH2
unnamed: I/O_EXPANDER_6.P2, RELAY_3.CH3
unnamed: I/O_EXPANDER_6.P3, RELAY_3.CH4
unnamed: I/O_EXPANDER_6.P4, RELAY_3.CH5
unnamed: I/O_EXPANDER_6.P5, RELAY_3.CH6
unnamed: I/O_EXPANDER_6.P6, RELAY_3.CH7
unnamed: I/O_EXPANDER_6.P7, RELAY_3.CH8
unnamed: I/O_EXPANDER.P0, RELAY_2.CH1
unnamed: I/O_EXPANDER.P1, RELAY_2.CH2
unnamed: I/O_EXPANDER.P2, RELAY_2.CH3
unnamed: I/O_EXPANDER.P3, RELAY_2.CH4
unnamed: I/O_EXPANDER.P4, RELAY_2.CH5
unnamed: I/O_EXPANDER.P5, RELAY_2.CH6
unnamed: I/O_EXPANDER.P6, RELAY_2.CH7
unnamed: I/O_EXPANDER.P7, RELAY_2.CH8
unnamed: I/O_EXPANDER_1.P4, RJ45_2X4_MODULE.LP1-5 (P1-5)
unnamed: I/O_EXPANDER_1.P5, RJ45_2X4_MODULE.LP1-6 (P1-6)
unnamed: I/O_EXPANDER_1.P6, RJ45_2X4_MODULE.LP1-7 (P1-7)
unnamed: I/O_EXPANDER_1.P7, RJ45_2X4_MODULE.LP1-8 (P1-8)
unnamed: I/O_EXPANDER_2.P2, RJ45_2X4_MODULE.UP2-7 (P2-7)
unnamed: I/O_EXPANDER_2.P3, RJ45_2X4_MODULE.UP2-8 (P2-8)
unnamed: I/O_EXPANDER_2.P4, RJ45_2X4_MODULE.LP2-5 (P2-5)
unnamed: I/O_EXPANDER_2.P5, RJ45_2X4_MODULE.LP2-6 (P2-6)
unnamed: I/O_EXPANDER_2.P6, RJ45_2X4_MODULE.LP2-7 (P2-7)
unnamed: I/O_EXPANDER_2.P7, RJ45_2X4_MODULE.LP2-8 (P2-8)
unnamed: 4K7.1, SJ1.1, U$26.MISO
unnamed: I/O_EXPANDER_3.P0, RJ45_2X4_MODULE.UP3-5 (P3-5)
unnamed: RJ45_2X4_MODULE.LP4-5 (P4-5), RJ45_2X4_MODULE.UP4-5 (P4-5), U$26.CL (CANL)
unnamed: I/O_EXPANDER_3.P1, RJ45_2X4_MODULE.UP3-6 (P3-6)
unnamed: I/O_EXPANDER_3.P2, RJ45_2X4_MODULE.UP3-7 (P3-7)
unnamed: I/O_EXPANDER_3.P3, RJ45_2X4_MODULE.UP3-8 (P3-8)
unnamed: I/O_EXPANDER_3.P4, RJ45_2X4_MODULE.LP3-5 (P3-5)
unnamed: I/O_EXPANDER_3.P5, RJ45_2X4_MODULE.LP3-6 (P3-6)
unnamed: I/O_EXPANDER_3.P6, RJ45_2X4_MODULE.LP3-7 (P3-7)
unnamed: I/O_EXPANDER_3.P7, RJ45_2X4_MODULE.LP3-8 (P3-8)
unnamed: RJ45_2X4_MODULE.UP4-7 (P4-7), U$1.P$1
unnamed: RJ45_2X4_MODULE.UP4-8 (P4-8), U$4.P$1
unnamed: RJ45_2X4_MODULE.LP4-7 (P4-7), U$5.P$1
unnamed: RJ45_2X4_MODULE.LP4-8 (P4-8), U$25.P$1
unnamed: RJ45_2X4_MODULE.LP4-6 (P4-6), RJ45_2X4_MODULE.UP4-6 (P4-6), U$26.CH (CANH)
SCL: ESP32-POE-ISO.16, I/O_EXPANDER.SCL, I/O_EXPANDER_1.SCL, I/O_EXPANDER_2.SCL, I/O_EXPANDER_3.SCL, I/O_EXPANDER_4.SCL, I/O_EXPANDER_6.SCL, U$21.P$1
SDA: ESP32-POE-ISO.13, I/O_EXPANDER.SDA, I/O_EXPANDER_1.SDA, I/O_EXPANDER_2.SDA, I/O_EXPANDER_3.SDA, I/O_EXPANDER_4.SDA, I/O_EXPANDER_6.SDA, U$24.P$1

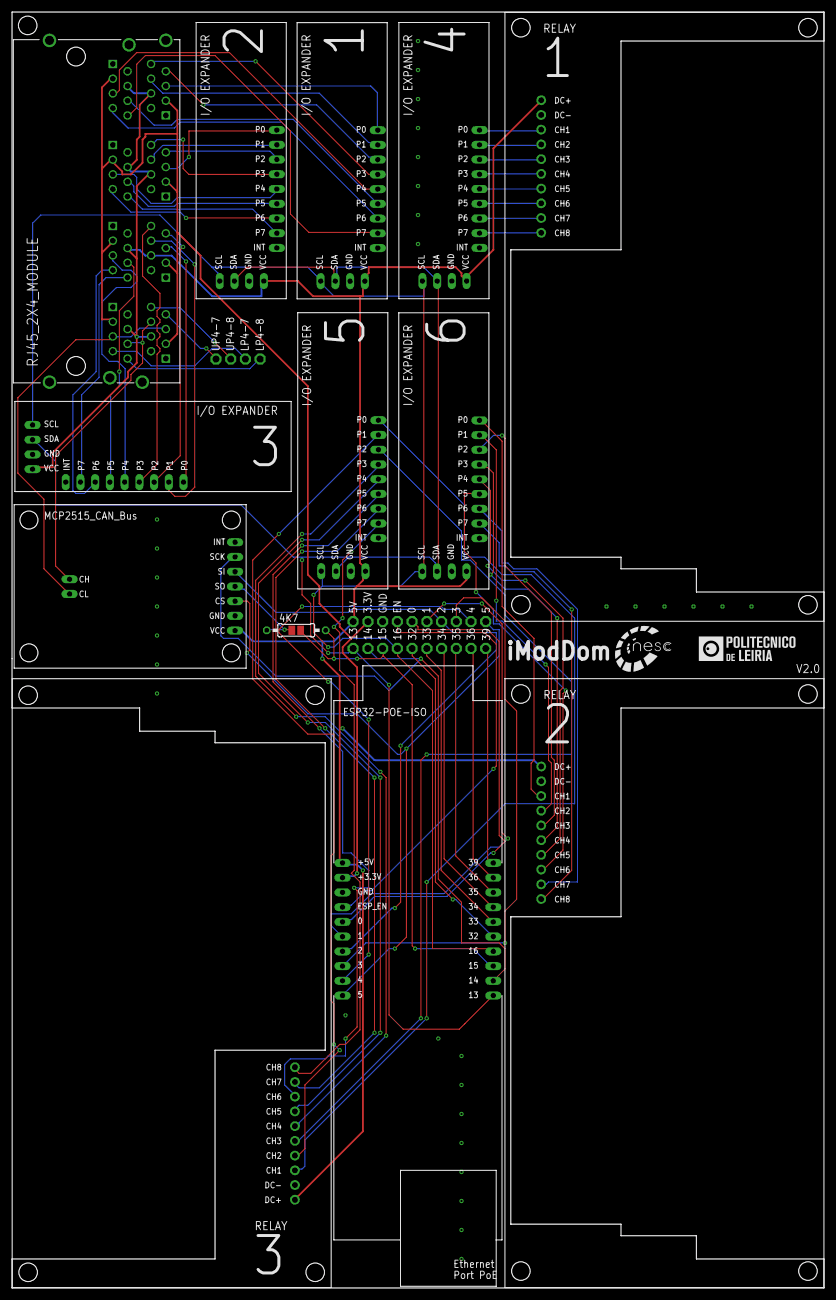
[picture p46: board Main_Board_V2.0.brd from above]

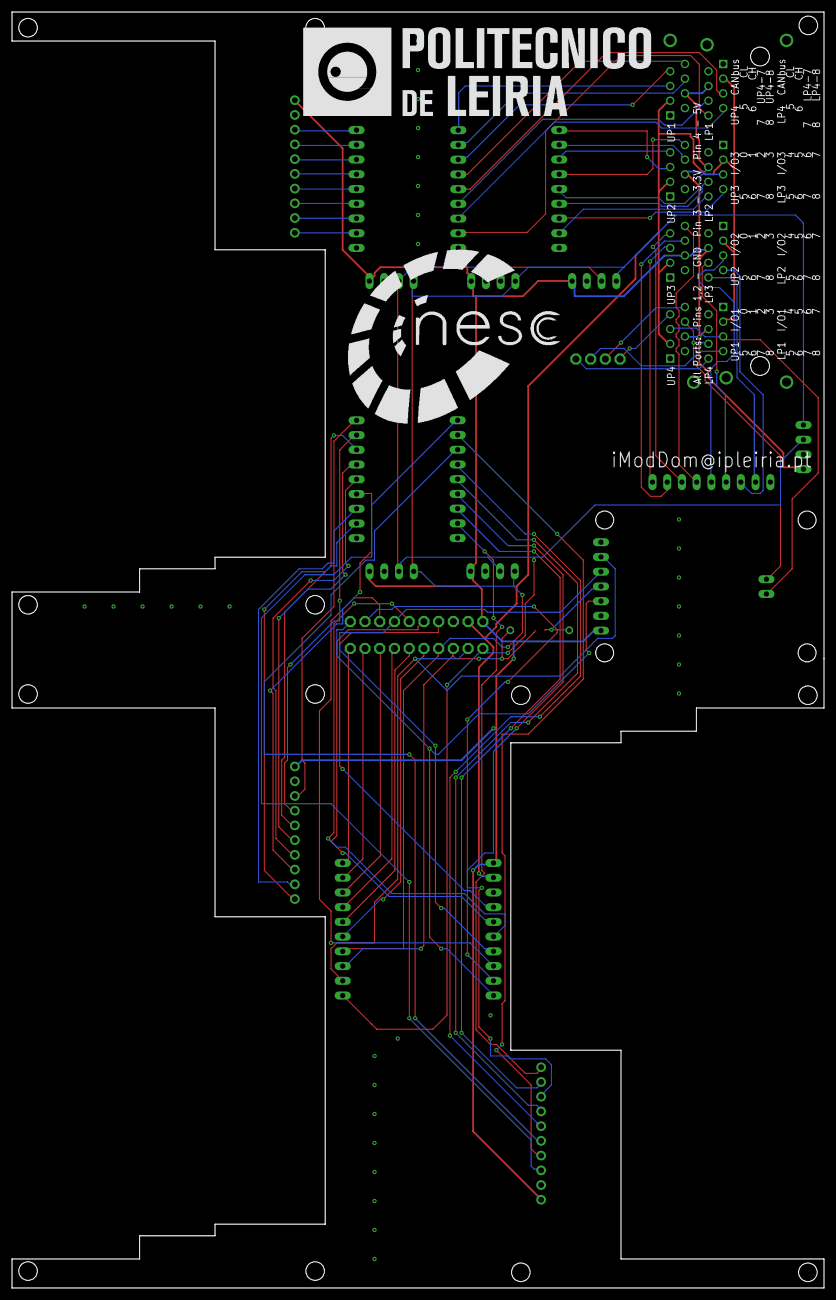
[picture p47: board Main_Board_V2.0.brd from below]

Board: 2 copper layers, 140.0 x 220.0 mm, 38 parts (5 on the bottom side), 75 nets.

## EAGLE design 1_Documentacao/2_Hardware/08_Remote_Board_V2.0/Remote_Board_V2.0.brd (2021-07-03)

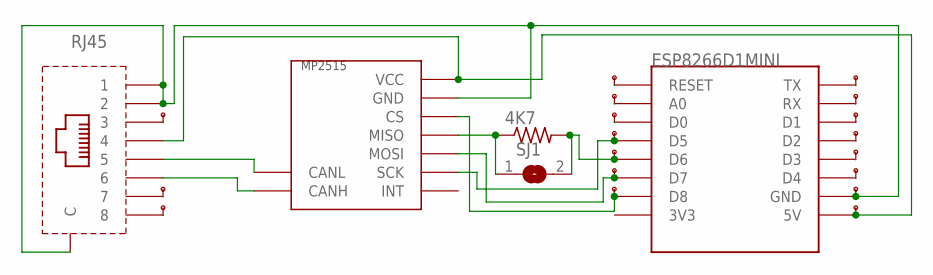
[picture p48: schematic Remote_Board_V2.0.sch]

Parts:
4K7: R-US_0207/10; 0207/10
ESP8266D1MINI: WEMOS-D1-MINI_SEM_LAYOUT
RJ45: ALI-RJ45_SEM_LAYOUT
SJ1: SJ
U$1, U$2, U$3, U$4, U$5, U$6, U$7, U$8, U$9, U$10, U$11, U$12, U$13, U$14, U$15, U$16, U$17, U$18: TP
U$31: MCP2515_MODULE_SEM_LAYOUT

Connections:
GND: ESP8266D1MINI.GND, RJ45.1, RJ45.2, RJ45.P$1 (C), RJ45.P$2 (C), U$15.P$1, U$31.GND
unnamed: RJ45.3, U$10.P$1
unnamed: RJ45.7, U$17.P$1
unnamed: RJ45.8, U$18.P$1
unnamed: ESP8266D1MINI.RESET, U$1.P$1
unnamed: ESP8266D1MINI.A0, U$2.P$1
unnamed: ESP8266D1MINI.D0, U$3.P$1
unnamed: ESP8266D1MINI.D5, U$4.P$1, U$31.SCK
unnamed: 4K7.2, ESP8266D1MINI.D6, SJ1.2, U$5.P$1
unnamed: ESP8266D1MINI.D7, U$8.P$1, U$31.MOSI
unnamed: ESP8266D1MINI.D8, U$9.P$1, U$31.CS
unnamed: RJ45.5, U$31.CL (CANL)
unnamed: RJ45.6, U$31.CH (CANH)
unnamed: ESP8266D1MINI.D4, U$14.P$1
unnamed: ESP8266D1MINI.D3, U$13.P$1
unnamed: ESP8266D1MINI.D2, U$12.P$1
unnamed: ESP8266D1MINI.D1, U$11.P$1
unnamed: ESP8266D1MINI.RX, U$7.P$1
unnamed: ESP8266D1MINI.TX, U$6.P$1
unnamed: 4K7.1, SJ1.1, U$31.MISO
unnamed: ESP8266D1MINI.5V, RJ45.4, U$16.P$1, U$31.VCC

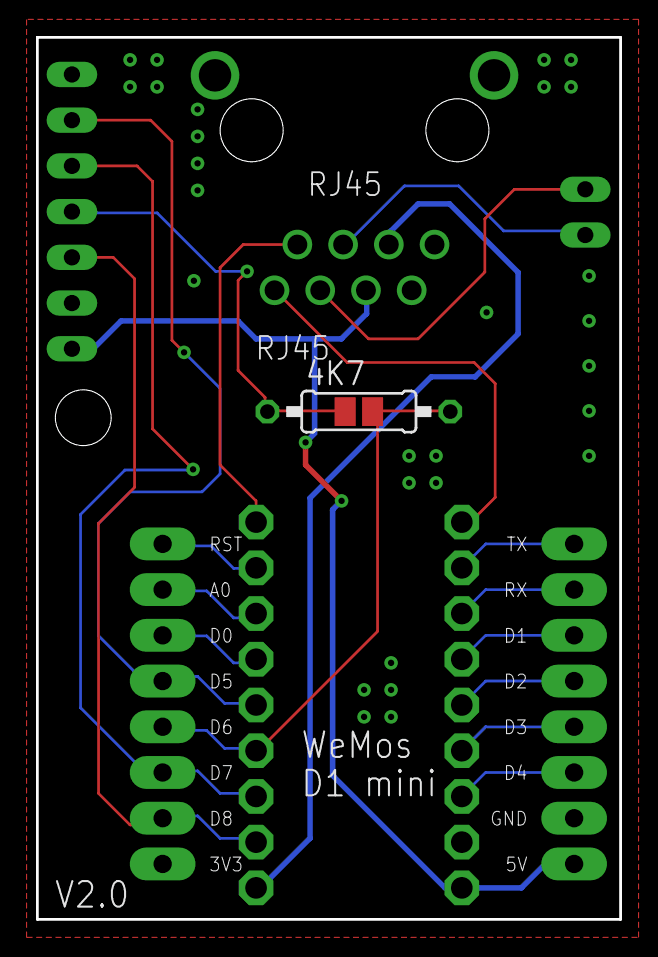
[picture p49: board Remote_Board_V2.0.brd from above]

Board: 2 copper layers, 32.4 x 49.0 mm, 23 parts (0 on the bottom side), 21 nets.

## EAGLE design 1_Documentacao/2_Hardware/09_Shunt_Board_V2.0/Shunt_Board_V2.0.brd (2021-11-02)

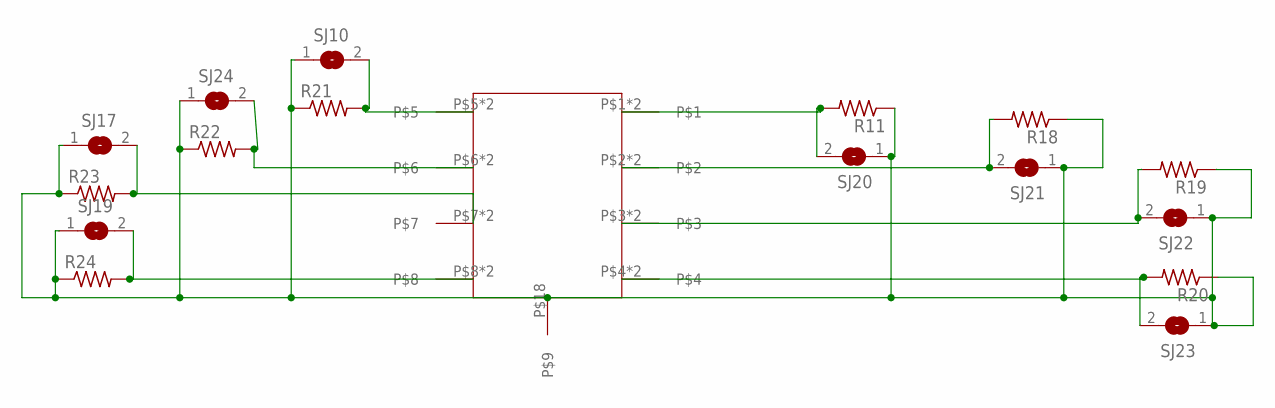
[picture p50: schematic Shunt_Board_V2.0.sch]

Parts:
R11, R18, R19, R20, R21, R22, R23, R24: R-US_0204/5; 0204/5
SJ10, SJ17, SJ19, SJ20, SJ21, SJ22, SJ23, SJ24: SJ
U$28: SHUNT2

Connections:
unnamed: R18.2, SJ21.2, U$28.P$2, U$28.P$11
unnamed: R19.2, SJ22.2, U$28.P$3, U$28.P$12
unnamed: R20.2, SJ23.2, U$28.P$4, U$28.P$13
unnamed: R21.2, SJ10.2, U$28.P$5, U$28.P$14
unnamed: R22.2, SJ24.2, U$28.P$6, U$28.P$15
unnamed: R23.2, SJ17.2, U$28.P$7, U$28.P$16
unnamed: R24.2, SJ19.2, U$28.P$8, U$28.P$17
unnamed: R11.1, R18.1, R19.1, R20.1, R21.1, R22.1, R23.1, R24.1, SJ10.1, SJ17.1, SJ19.1, SJ20.1, SJ21.1, SJ22.1, SJ23.1, SJ24.1, U$28.P$18
unnamed: R11.2, SJ20.2, U$28.P$1, U$28.P$10

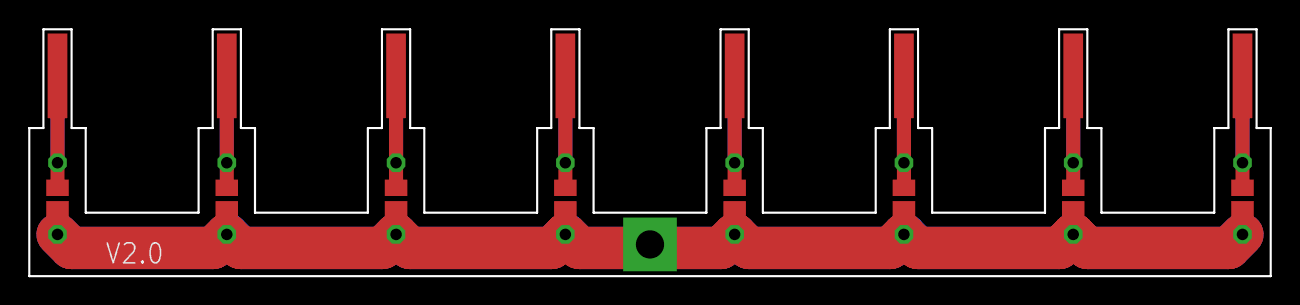
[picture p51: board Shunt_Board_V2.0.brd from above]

Board: 2 copper layers, 88.0 x 17.5 mm, 17 parts (0 on the bottom side), 9 nets.

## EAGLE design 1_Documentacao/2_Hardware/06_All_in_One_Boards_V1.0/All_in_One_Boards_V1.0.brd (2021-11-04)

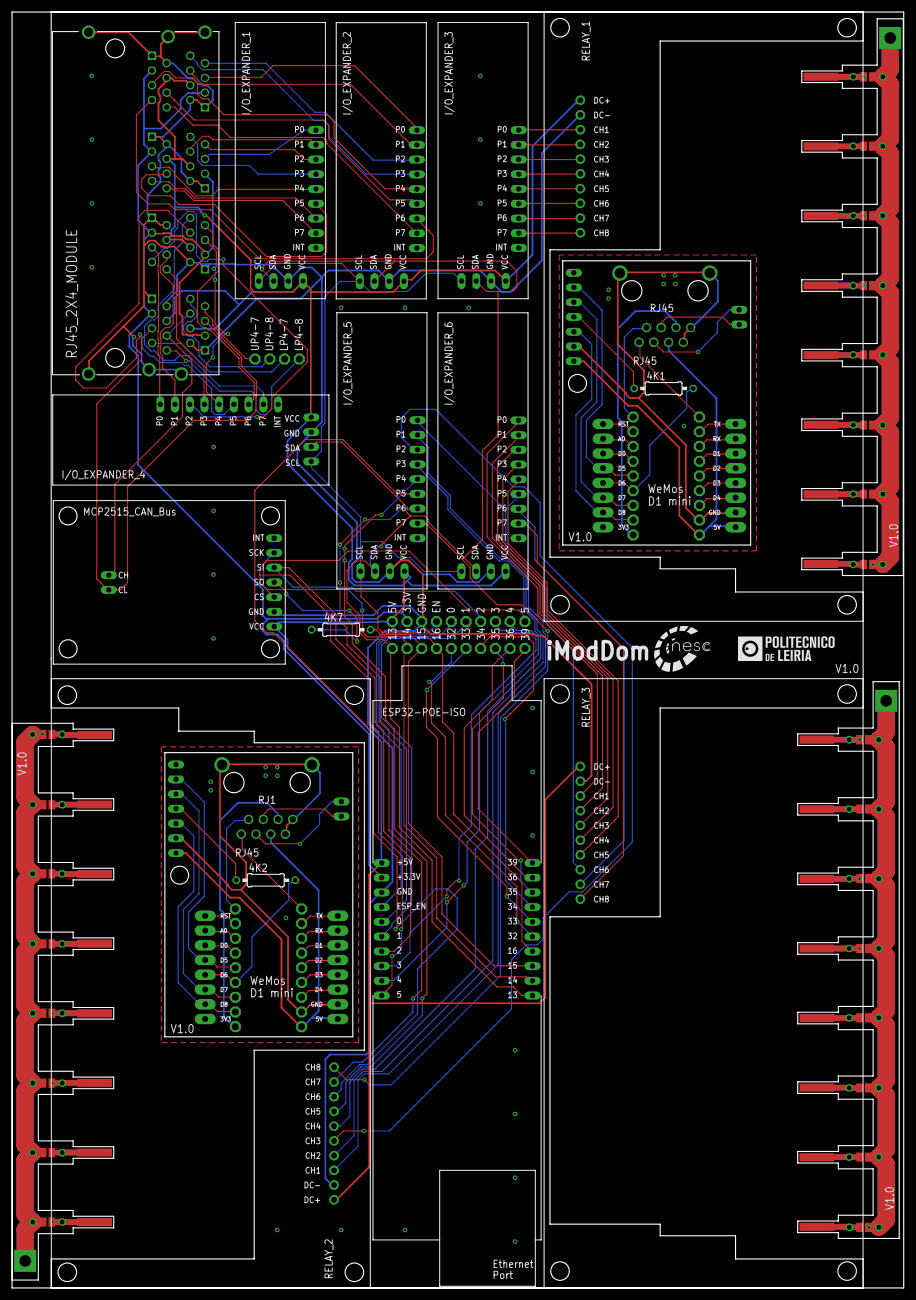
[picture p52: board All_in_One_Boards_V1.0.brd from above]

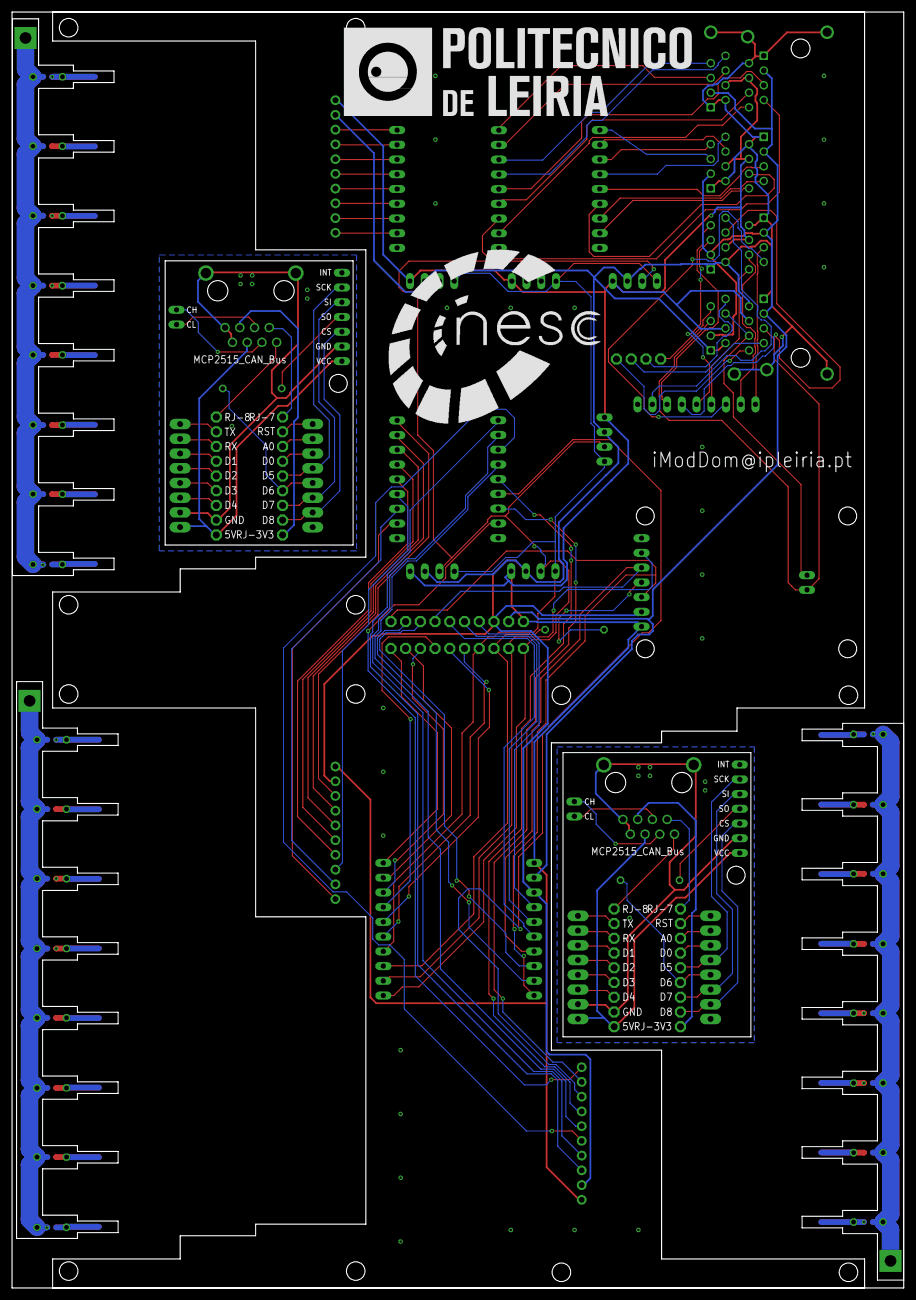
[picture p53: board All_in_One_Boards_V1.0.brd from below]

Board: 2 copper layers, 153.8 x 220.0 mm, 132 parts (8 on the bottom side), 144 nets.

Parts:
4K1, 4K2, 4K7: 0207/10
ESP32-POE-ISO: ESP-POE
ESP8266D1MINI, ESP8266D1MINI1: WEMOS-D1-MINI_SEM_LAYOUT
I/O_EXPANDER_1, I/O_EXPANDER_2, I/O_EXPANDER_3, I/O_EXPANDER_4, I/O_EXPANDER_5, I/O_EXPANDER_6: PCF8574-MODULE_ESPELHADO
R1, R2, R3, R4, R5, R6, R7, R8, R9, R10, R11, R12, R13, R14, R15, R16, R17, R18, R19, R20, R21, R22, R23, R24: 0204/5
RELAY_1, RELAY_2, RELAY_3: SSR_M_FULL_SEM_LIGACOES; SSR_M_SEM_LIGACOES
RJ1, RJ45: ALI-RJ45_SEM_LAYOUT
RJ45_2X4_MODULE: 5569262-1; TE_5569262-1
SJ1, SJ2, SJ3, SJ4, SJ5, SJ6, SJ7, SJ8, SJ9, SJ10, SJ11, SJ12, SJ13, SJ14, SJ15, SJ16, SJ17, SJ18, SJ19, SJ20, SJ21, SJ22, SJ23, SJ24: SJ
U$1, U$2, U$3, U$4, U$5, U$6, U$7, U$8, U$9, U$10, U$11, U$12, U$13, U$14, U$15, U$16, U$17, U$18, U$19, U$20, U$21, U$22, U$23, U$24, U$25, U$27, U$28, U$29, U$30, U$32, U$33, U$34, U$35, U$36, U$37, U$38, U$39, U$40, U$41, U$42, U$43, U$44, U$46, U$47, U$48, U$49, U$50, U$51, U$52, U$53, U$54, U$55, U$56, U$57, U$58, U$59, U$60, U$61, U$62, U$63: TP
U$26: MCP2515_MODULE_SEM_LIGACOES
U$31, U$45: MCP2515_MODULE_SEM_LAYOUT
U$64, U$65, U$66: SHUNT

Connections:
+3V3: ESP32-POE-ISO.3V3, RJ45_2X4_MODULE.LP1-3, RJ45_2X4_MODULE.LP2-3, RJ45_2X4_MODULE.LP3-3, RJ45_2X4_MODULE.LP4-3, RJ45_2X4_MODULE.UP1-3, RJ45_2X4_MODULE.UP2-3, RJ45_2X4_MODULE.UP3-3, RJ45_2X4_MODULE.UP4-3, U$6.P$1
+5V: ESP32-POE-ISO.5V, I/O_EXPANDER_1.VCC, I/O_EXPANDER_2.VCC, I/O_EXPANDER_3.VCC, I/O_EXPANDER_4.VCC, I/O_EXPANDER_5.VCC, I/O_EXPANDER_6.VCC, RELAY_1.DC+, RELAY_2.DC+, RELAY_3.DC+, RJ45_2X4_MODULE.LP1-4, RJ45_2X4_MODULE.LP2-4, RJ45_2X4_MODULE.LP3-4, RJ45_2X4_MODULE.LP4-4, RJ45_2X4_MODULE.UP1-4, RJ45_2X4_MODULE.UP2-4, RJ45_2X4_MODULE.UP3-4, RJ45_2X4_MODULE.UP4-4, U$2.P$1, U$26.VCC
GND: ESP32-POE-ISO.GND, I/O_EXPANDER_1.GND, I/O_EXPANDER_2.GND, I/O_EXPANDER_3.GND, I/O_EXPANDER_4.GND, I/O_EXPANDER_5.GND, I/O_EXPANDER_6.GND, RELAY_1.DC-, RELAY_2.DC-, RELAY_3.DC-, RJ45_2X4_MODULE.LP1-1, RJ45_2X4_MODULE.LP1-2, RJ45_2X4_MODULE.LP2-1, RJ45_2X4_MODULE.LP2-2, RJ45_2X4_MODULE.LP3-1, RJ45_2X4_MODULE.LP3-2, RJ45_2X4_MODULE.LP4-1, RJ45_2X4_MODULE.LP4-2, RJ45_2X4_MODULE.S1, RJ45_2X4_MODULE.S2, RJ45_2X4_MODULE.S3, RJ45_2X4_MODULE.S4, RJ45_2X4_MODULE.S5, RJ45_2X4_MODULE.S6, RJ45_2X4_MODULE.UP1-1, RJ45_2X4_MODULE.UP1-2, RJ45_2X4_MODULE.UP2-1, RJ45_2X4_MODULE.UP2-2, RJ45_2X4_MODULE.UP3-1, RJ45_2X4_MODULE.UP3-2, RJ45_2X4_MODULE.UP4-1, RJ45_2X4_MODULE.UP4-2, U$7.P$1, U$26.GND
GND1: ESP8266D1MINI.GND, RJ45.1, RJ45.2, RJ45.P$1, RJ45.P$2, U$31.GND, U$41.P$1
GND2: ESP8266D1MINI1.GND, RJ1.1, RJ1.2, RJ1.P$1, RJ1.P$2, U$45.GND, U$60.P$1
unnamed: I/O_EXPANDER_1.P7, RJ45_2X4_MODULE.LP2-8
unnamed: I/O_EXPANDER_1.P6, RJ45_2X4_MODULE.LP2-7
unnamed: I/O_EXPANDER_1.P5, RJ45_2X4_MODULE.LP2-6
unnamed: ESP32-POE-ISO.ESP_EN, U$8.P$1
unnamed: ESP32-POE-ISO.0, U$9.P$1
unnamed: ESP32-POE-ISO.1, U$10.P$1
unnamed: ESP32-POE-ISO.2, U$11.P$1, U$26.MOSI
unnamed: ESP32-POE-ISO.3, U$12.P$1
unnamed: ESP32-POE-ISO.4, U$13.P$1
unnamed: ESP32-POE-ISO.5, U$14.P$1, U$26.CS
unnamed: ESP32-POE-ISO.39, U$15.P$1
unnamed: ESP32-POE-ISO.36, U$16.P$1
unnamed: ESP32-POE-ISO.35, U$17.P$1
unnamed: ESP32-POE-ISO.34, U$18.P$1
unnamed: ESP32-POE-ISO.33, U$19.P$1
unnamed: ESP32-POE-ISO.32, U$20.P$1
unnamed: RJ45.3, U$34.P$1
unnamed: 4K7.2, ESP32-POE-ISO.15, U$22.P$1
unnamed: ESP32-POE-ISO.14, U$23.P$1, U$26.SCK
unnamed: RJ45.7, U$43.P$1
unnamed: I/O_EXPANDER_3.P0, RELAY_1.CH1
unnamed: I/O_EXPANDER_3.P1, RELAY_1.CH2
unnamed: I/O_EXPANDER_3.P2, RELAY_1.CH3
unnamed: I/O_EXPANDER_3.P3, RELAY_1.CH4
unnamed: I/O_EXPANDER_3.P4, RELAY_1.CH5
unnamed: I/O_EXPANDER_1.P4, RJ45_2X4_MODULE.LP2-5
unnamed: I/O_EXPANDER_3.P5, RELAY_1.CH6
unnamed: I/O_EXPANDER_3.P6, RELAY_1.CH7
unnamed: I/O_EXPANDER_3.P7, RELAY_1.CH8
unnamed: I/O_EXPANDER_6.P0, RELAY_3.CH1
unnamed: I/O_EXPANDER_6.P1, RELAY_3.CH2
unnamed: I/O_EXPANDER_6.P2, RELAY_3.CH3
unnamed: I/O_EXPANDER_6.P3, RELAY_3.CH4
unnamed: I/O_EXPANDER_6.P4, RELAY_3.CH5
unnamed: I/O_EXPANDER_6.P5, RELAY_3.CH6
unnamed: I/O_EXPANDER_6.P6, RELAY_3.CH7
unnamed: I/O_EXPANDER_6.P7, RELAY_3.CH8
unnamed: I/O_EXPANDER_5.P0, RELAY_2.CH1
unnamed: I/O_EXPANDER_5.P1, RELAY_2.CH2
unnamed: I/O_EXPANDER_5.P2, RELAY_2.CH3
unnamed: I/O_EXPANDER_5.P3, RELAY_2.CH4
unnamed: I/O_EXPANDER_5.P4, RELAY_2.CH5
unnamed: I/O_EXPANDER_5.P5, RELAY_2.CH6
unnamed: I/O_EXPANDER_5.P6, RELAY_2.CH7
unnamed: I/O_EXPANDER_5.P7, RELAY_2.CH8
unnamed: I/O_EXPANDER_1.P3, RJ45_2X4_MODULE.UP2-8
unnamed: I/O_EXPANDER_1.P2, RJ45_2X4_MODULE.UP2-7
unnamed: I/O_EXPANDER_1.P1, RJ45_2X4_MODULE.UP2-6
unnamed: I/O_EXPANDER_1.P0, RJ45_2X4_MODULE.UP2-5
unnamed: I/O_EXPANDER_2.P0, RJ45_2X4_MODULE.UP1-5
unnamed: I/O_EXPANDER_2.P1, RJ45_2X4_MODULE.UP1-6
unnamed: I/O_EXPANDER_2.P2, RJ45_2X4_MODULE.UP1-7
unnamed: I/O_EXPANDER_2.P3, RJ45_2X4_MODULE.UP1-8
unnamed: I/O_EXPANDER_2.P4, RJ45_2X4_MODULE.LP1-5
unnamed: I/O_EXPANDER_2.P5, RJ45_2X4_MODULE.LP1-6
unnamed: I/O_EXPANDER_2.P6, RJ45_2X4_MODULE.LP1-7
unnamed: I/O_EXPANDER_2.P7, RJ45_2X4_MODULE.LP1-8
unnamed: RJ45_2X4_MODULE.LP4-5, RJ45_2X4_MODULE.UP4-5, U$26.CL
unnamed: RJ45.8, U$44.P$1
unnamed: I/O_EXPANDER_4.P7, RJ45_2X4_MODULE.UP3-8
unnamed: I/O_EXPANDER_4.P6, RJ45_2X4_MODULE.UP3-7
unnamed: I/O_EXPANDER_4.P5, RJ45_2X4_MODULE.UP3-6
unnamed: I/O_EXPANDER_4.P4, RJ45_2X4_MODULE.UP3-5
unnamed: I/O_EXPANDER_4.P0, RJ45_2X4_MODULE.LP3-5
unnamed: I/O_EXPANDER_4.P1, RJ45_2X4_MODULE.LP3-6
unnamed: I/O_EXPANDER_4.P2, RJ45_2X4_MODULE.LP3-7
unnamed: I/O_EXPANDER_4.P3, RJ45_2X4_MODULE.LP3-8
unnamed: 4K7.1, U$26.MISO
unnamed: RJ45_2X4_MODULE.UP4-7, U$1.P$1
unnamed: RJ45_2X4_MODULE.UP4-8, U$4.P$1
unnamed: RJ45_2X4_MODULE.LP4-7, U$5.P$1
unnamed: RJ45_2X4_MODULE.LP4-8, U$25.P$1
unnamed: RJ45_2X4_MODULE.LP4-6, RJ45_2X4_MODULE.UP4-6, U$26.CH
unnamed: ESP8266D1MINI.RESET, U$3.P$1
unnamed: ESP8266D1MINI.A0, U$27.P$1
unnamed: ESP8266D1MINI.D0, U$28.P$1
unnamed: ESP8266D1MINI.D5, U$29.P$1, U$31.SCK
unnamed: 4K1.2, ESP8266D1MINI.D6, U$30.P$1
unnamed: ESP8266D1MINI.D7, U$31.MOSI, U$32.P$1
unnamed: ESP8266D1MINI.D8, U$31.CS, U$33.P$1
unnamed: ESP8266D1MINI.D4, U$40.P$1
unnamed: ESP8266D1MINI.D3, U$39.P$1
unnamed: ESP8266D1MINI.D2, U$38.P$1
unnamed: ESP8266D1MINI.D1, U$37.P$1
unnamed: ESP8266D1MINI.RX, U$36.P$1
unnamed: ESP8266D1MINI.TX, U$35.P$1
unnamed: ESP8266D1MINI.5V, RJ45.4, U$31.VCC, U$42.P$1
unnamed: RJ45.5, U$31.CL
unnamed: RJ45.6, U$31.CH
unnamed: 4K1.1, U$31.MISO
unnamed: RJ1.3, U$53.P$1
unnamed: RJ1.7, U$62.P$1
unnamed: RJ1.8, U$63.P$1
unnamed: ESP8266D1MINI1.RESET, U$46.P$1
unnamed: ESP8266D1MINI1.A0, U$47.P$1
unnamed: ESP8266D1MINI1.D0, U$48.P$1
unnamed: ESP8266D1MINI1.D5, U$45.SCK, U$49.P$1
unnamed: 4K2.2, ESP8266D1MINI1.D6, U$50.P$1
unnamed: ESP8266D1MINI1.D7, U$45.MOSI, U$51.P$1
unnamed: ESP8266D1MINI1.D8, U$45.CS, U$52.P$1
unnamed: ESP8266D1MINI1.D4, U$59.P$1
unnamed: ESP8266D1MINI1.D3, U$58.P$1
unnamed: ESP8266D1MINI1.D2, U$57.P$1
unnamed: ESP8266D1MINI1.D1, U$56.P$1
unnamed: ESP8266D1MINI1.RX, U$55.P$1
unnamed: ESP8266D1MINI1.TX, U$54.P$1
unnamed: ESP8266D1MINI1.5V, RJ1.4, U$45.VCC, U$61.P$1
unnamed: RJ1.5, U$45.CL
unnamed: RJ1.6, U$45.CH
unnamed: 4K2.1, U$45.MISO
unnamed: R18.2, SJ21.2, U$64.P$2
unnamed: R19.2, SJ22.2, U$64.P$3
unnamed: R20.2, SJ23.2, U$64.P$4
unnamed: R23.2, SJ17.2, U$64.P$7
unnamed: R24.2, SJ19.2, U$64.P$8
unnamed: R11.2, SJ20.2, U$64.P$1
unnamed: R21.2, SJ10.2, U$64.P$5
unnamed: R22.2, SJ24.2, U$64.P$6
unnamed: R11.1, R18.1, R19.1, R20.1, R21.1, R22.1, R23.1, R24.1, SJ10.1, SJ17.1, SJ19.1, SJ20.1, SJ21.1, SJ22.1, SJ23.1, SJ24.1, U$64.P$9
unnamed: R2.2, SJ5.2, U$65.P$2
unnamed: R3.2, SJ6.2, U$65.P$3
unnamed: R4.2, SJ7.2, U$65.P$4
unnamed: R7.2, SJ2.2, U$65.P$7
unnamed: R8.2, SJ3.2, U$65.P$8
unnamed: R1.2, SJ4.2, U$65.P$1
unnamed: R5.2, SJ1.2, U$65.P$5
unnamed: R6.2, SJ8.2, U$65.P$6
unnamed: R1.1, R2.1, R3.1, R4.1, R5.1, R6.1, R7.1, R8.1, SJ1.1, SJ2.1, SJ3.1, SJ4.1, SJ5.1, SJ6.1, SJ7.1, SJ8.1, U$65.P$9
unnamed: R10.2, SJ14.2, U$66.P$2
unnamed: R12.2, SJ15.2, U$66.P$3
unnamed: R13.2, SJ16.2, U$66.P$4
unnamed: R16.2, SJ11.2, U$66.P$7
unnamed: R17.2, SJ12.2, U$66.P$8
unnamed: R9.2, SJ13.2, U$66.P$1
unnamed: R14.2, SJ9.2, U$66.P$5
unnamed: R15.2, SJ18.2, U$66.P$6
unnamed: R9.1, R10.1, R12.1, R13.1, R14.1, R15.1, R16.1, R17.1, SJ9.1, SJ11.1, SJ12.1, SJ13.1, SJ14.1, SJ15.1, SJ16.1, SJ18.1, U$66.P$9
SCL: ESP32-POE-ISO.16, I/O_EXPANDER_1.SCL, I/O_EXPANDER_2.SCL, I/O_EXPANDER_3.SCL, I/O_EXPANDER_4.SCL, I/O_EXPANDER_5.SCL, I/O_EXPANDER_6.SCL, U$21.P$1
SDA: ESP32-POE-ISO.13, I/O_EXPANDER_1.SDA, I/O_EXPANDER_2.SDA, I/O_EXPANDER_3.SDA, I/O_EXPANDER_4.SDA, I/O_EXPANDER_5.SDA, I/O_EXPANDER_6.SDA, U$24.P$1

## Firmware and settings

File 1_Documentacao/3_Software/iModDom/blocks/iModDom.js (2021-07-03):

Blockly.defineBlocksWithJsonArray(  // BEGIN JSON EXTRACT
  [{
    "type": "device",
    "message0": "ESPHome %1 Node name: %2 %3 Platform: %4 %5 Board: %6",
    "args0": [
      {
        "type": "input_dummy"
      },
      {
        "type": "field_input",
        "name": "name",
        "text": "name"
      },
      {
        "type": "input_dummy"
      },
      {
        "type": "field_dropdown",
        "name": "cpu",
        "options": [
          [
            "ESP32",
            "ESP32"
          ],
          [
            "ESP8266",
            "ESP8266"
          ]
        ]
      },
      {
        "type": "input_dummy"
      },
      {
        "type": "field_dropdown",
        "name": "board",
        "options": [
          [
            "esp32-poe-iso",
            "esp32-poe-iso"
          ],
          [
            "esp32-poe",
            "esp32-poe"
          ],
          [
            "esp32cam",
            "esp32cam"
          ],
          [
            "wemos_d1_mini32",
            "wemos_d1_mini32"
          ],
          [
            "node32s",
            "node32s"
          ],
          [
            "nodemcu-32s",
            "nodemcu-32s"
          ],
          [
            "esp8266 d1",
            "d1"
          ],
          [
            "esp8266 d1_mini",
            "d1_mini"
          ],
          [
            "esp8266 d1_mini_lite",
            "d1_mini_lite"
          ],
          [
            "esp8266 d1_mini_pro",
            "d1_mini_pro"
          ],
          [
            "esp8266 nodemcu",
            "nodemcu"
          ],
          [
            "esp8266 nodemcuv2",
            "nodemcuv2"
          ]
        ]
      }
    ],
    "nextStatement": "Main",
    "colour": 65,
    "tooltip": "",
    "helpUrl": ""
  },
  {
    "type": "wifi",
    "message0": "Wifi %1 SSID: %2 %3 Password: %4 %5 Manual ip: %6",
    "args0": [
      {
        "type": "input_dummy"
      },
      {
        "type": "field_input",
        "name": "ssid",
        "text": "SSID"
      },
      {
        "type": "input_dummy"
      },
      {
        "type": "field_input",
        "name": "password",
        "text": "wifi_password"
      },
      {
        "type": "input_dummy"
      },
      {
        "type": "input_value",
        "name": "manual_ip",
        "check": "Ip"
      }
    ],
    "inputsInline": false,
    "previousStatement": "Main",
    "nextStatement": "Main",
    "colour": 65,
    "tooltip": "",
    "helpUrl": ""
  },
  {
    "type": "manual_ip",
    "message0": "IP %1 Static ip: %2 . %3 . %4 . %5 %6 Gateway: %7 . %8 . %9 . %10 %11 Subnet: %12 . %13 . %14 . %15",
    "args0": [
      {
        "type": "input_dummy"
      },
      {
        "type": "field_number",
        "name": "ip_1",
        "value": 0,
        "min": 0,
        "max": 255
      },
      {
        "type": "field_number",
        "name": "ip_2",
        "value": 0,
        "min": 0,
        "max": 255
      },
      {
        "type": "field_number",
        "name": "ip_3",
        "value": 0,
        "min": 0,
        "max": 255
      },
      {
        "type": "field_number",
        "name": "ip_4",
        "value": 0,
        "min": 0,
        "max": 255
      },
      {
        "type": "input_dummy"
      },
      {
        "type": "field_number",
        "name": "gatew_1",
        "value": 0,
        "min": 0,
        "max": 255
      },
      {
        "type": "field_number",
        "name": "gatew_2",
        "value": 0,
        "min": 0,
        "max": 255
      },
      {
        "type": "field_number",
        "name": "gatew_3",
        "value": 0,
        "min": 0,
        "max": 255
      },
      {
        "type": "field_number",
        "name": "gatew_4",
        "value": 0,
        "min": 0,
        "max": 255
      },
      {
        "type": "input_dummy"
      },
      {
        "type": "field_number",
        "name": "subn_1",
        "value": 0,
        "min": 0,
        "max": 255
      },
      {
        "type": "field_number",
        "name": "subn_2",
        "value": 0,
        "min": 0,
        "max": 255
      },
      {
        "type": "field_number",
        "name": "subn_3",
        "value": 0,
        "min": 0,
        "max": 255
      },
      {
        "type": "field_number",
        "name": "subn_4",
        "value": 0,
        "min": 0,
        "max": 255
      }
    ],
    "output": "Ip",
    "colour": 65,
    "tooltip": "",
    "helpUrl": ""
  },
  {
    "type": "logger",
    "message0": "Logger %1 Level: %2",
    "args0": [
      {
        "type": "input_dummy"
      },
      {
        "type": "field_dropdown",
        "name": "level",
        "options": [
          [
            "NONE",
            "NONE"
          ],
          [
            "ERROR",
            "ERROR"
          ],
          [
            "WARN",
            "WARN"
          ],
          [
            "INFO",
            "INFO"
          ],
          [
            "DEBUG",
            "DEBUG"
          ],
          [
            "VERBOSE",
            "VERBOSE"
          ],
          [
            "VERY_VERBOSE",
            "VERY_VERBOSE"
          ]
        ]
      }
    ],
    "previousStatement": "Main",
    "nextStatement": "Main",
    "colour": 65,
    "tooltip": "",
    "helpUrl": ""
  },
  {
    "type": "i2c",
    "message0": "I2C %1 SDA pin: %2 %3 SCL pin: %4 %5 Scan: %6 %7 Id: %8",
    "args0": [
      {
        "type": "input_dummy"
      },
      {
        "type": "field_input",
        "name": "sda_pin",
        "text": "13"
      },
      {
        "type": "input_dummy"
      },
      {
        "type": "field_input",
        "name": "scl_pin",
        "text": "16"
      },
      {
        "type": "input_dummy"
      },
      {
        "type": "field_dropdown",
        "name": "scan",
        "options": [
          [
            "true",
            "True"
          ],
          [
            "false",
            "False"
          ]
        ]
      },
      {
        "type": "input_dummy"
      },
      {
        "type": "field_input",
        "name": "id",
        "text": "i2c_bus"
      }
    ],
    "previousStatement": "Main",
    "nextStatement": "Main",
    "colour": 65,
    "tooltip": "",
    "helpUrl": ""
  },
  {
    "type": "web_server",
    "message0": "Web Server %1 Port: %2",
    "args0": [
      {
        "type": "input_dummy"
      },
      {
        "type": "field_input",
        "name": "port",
        "text": "80"
      }
    ],
    "previousStatement": "Main",
    "nextStatement": "Main",
    "colour": 65,
    "tooltip": "",
    "helpUrl": ""
  },
  {
    "type": "pcf8574",
    "message0": "PCF8574 %1 %2 Adress 0x20: %3 %4 %5 Adress 0x21: %6 %7 %8 Adress 0x22: %9 %10 %11 Adress 0x23: %12 %13 %14 Adress 0x24: %15 %16 %17 Adress 0x25: %18 %19 %20 Adress 0x26: %21 %22 %23 Adress 0x27: %24",
    "args0": [
      {
        "type": "input_dummy"
      },
      {
        "type": "field_checkbox",
        "name": "0x20",
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

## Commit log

2021-07-03 First Upload
    [7_Lista_de_Hardware.xlsx, Main_Board_V1.0.brd, Main_Board_V1.0.sch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]
2021-11-02 Update Hardware Files
    [01_Lista_de_Hardware.xlsx, All_in_One_Boards_V1.0.brd, All_in_One_Boards_V2.0.brd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]
2021-11-04 Update All in One Boards
    [All_in_One_Boards_V1.0.brd, All_in_One_Boards_V2.0.brd]
